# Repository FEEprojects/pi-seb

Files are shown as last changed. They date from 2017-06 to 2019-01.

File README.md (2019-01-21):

# Pi-Seb



A PCB for the Raspberry Pi to create a flexible sensor evaluation board.

Provides the following features:
* HAT identification EEPROM
* 12V DC input
* Battery backed RTC
* Temperature/Humidity Sensor
* 8 differential ADC
* 23 GPIO
* 8 I2C connectors
* 4 SPI connectors
* Debug LEDs (can be disabled)
* 4 port USB hub
  * RS232 connection / TTL Serial
  * 2 TTL Serial ports
  * RS485 connection
* Pycom Socket
  * SD card
  * Control of Raspberry Pi Power
  * 2 TTL Serial ports
  * I2C connection
  * SPI port
  * 8 GPIO

## Assembly
Most of the passives and some of the semi conductors are available in the Seeed studio OPL, additional components then need to be sourced and hand soldred.

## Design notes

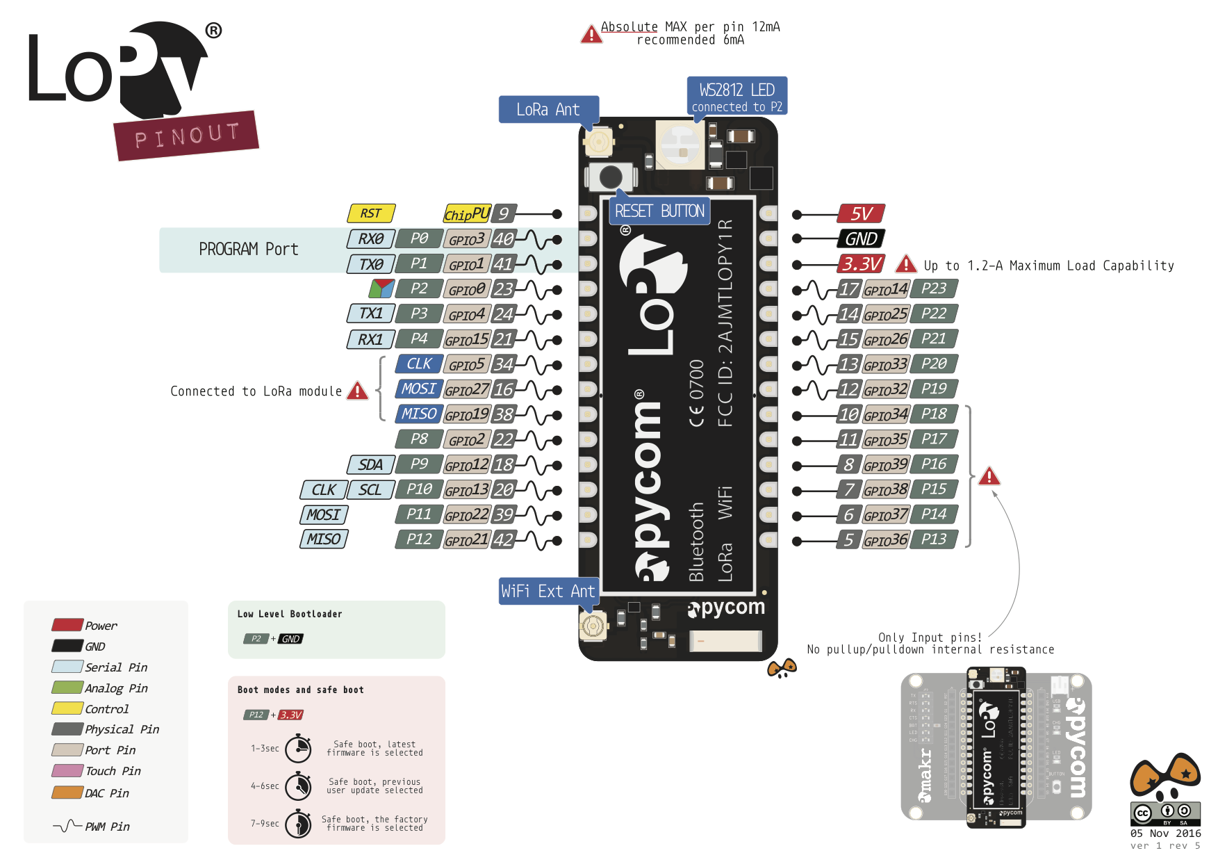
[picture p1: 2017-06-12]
datasheets/lopy_qr.png

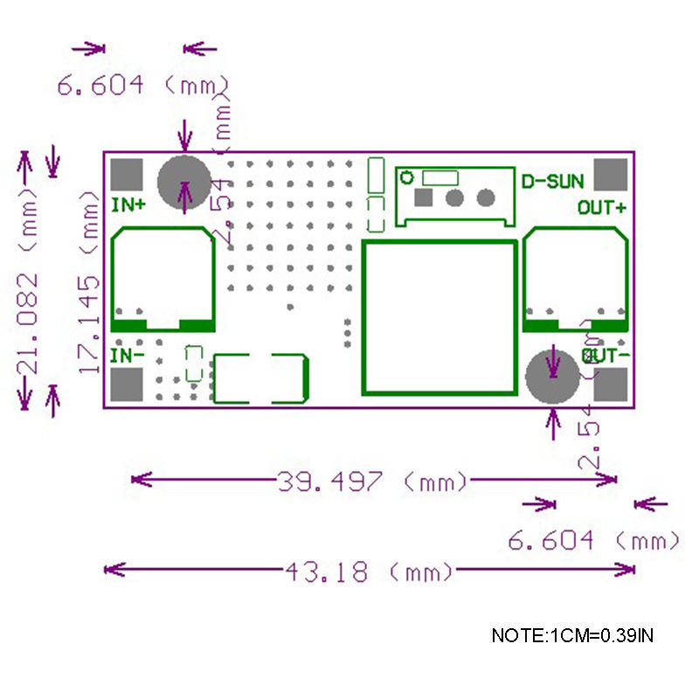
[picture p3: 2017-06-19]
datasheets/DC-Dc board dimensions.jpg

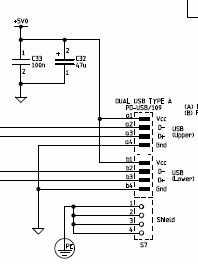
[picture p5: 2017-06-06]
OPL_pdf_lists/USB+INPUT+3+PI.png

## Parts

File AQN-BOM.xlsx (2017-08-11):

.Designator | Description | Qty | auto quantity | Value | Source (if not Seeed) | onecall part no | RS part no | Notes | MPN | Min Order (pcs) | Unit Price | Unit Price (£) | Line Total | To Order (pcs) | Order Price | Owned (pcs)
BAT1 | 320170002 | 1 | 1 |  |  |  |  |  |  | 1 | $0.01 | £0.01 | £0.01 | 6 | £0.05
C2, C6, C7, C11, C12, C13, C14, C18, C19, C20, C21, C22, C23, C24, C28, C29, C31, C35, C36, C38, C39, C42, C43, C46, C47 | 302010138 | 25 | 25 | 100nF |  |  |  |  | CC0603KRX7R9BB104 | 1 | $0.01 | £0.01 | £0.19 | 126 | £0.97
C25 | 302010140 | 1 | 1 | 10nF |  |  |  |  | CC0603KRX7R9BB103 | 1 | $0.01 | £0.01 | £0.01 | 6 | £0.05
C26, C34 | 302020002 | 2 | 2 | 10uF POL |  |  |  |  | TAJA106K016RNJ | 1 | $0.05 | £0.04 | £0.07 | 11 | £0.41
C30, C40, C44, C48 | 302020006 | 4 | 4 | 4.7uF POL |  |  |  |  | TAJA475*016#NJ | 1 | $0.04 | £0.03 | £0.13 | 21 | £0.66
C32 | 302010178 | 1 | 1 | 10uF |  |  |  |  | CC0805KKX5R8BB106 | 1 | $0.01 | £0.01 | £0.01 | 6 | £0.07
C4, C5, C8, C10 | 302020011 | 4 | 4 | 10uF POL |  |  |  |  | TAJA106K010RNJ | 1 | $0.04 | £0.03 | £0.13 | 21 | £0.66
D1 | 304020021 | 1 | 1 | 28V 5A diode |  |  |  |  | SS54B | 1 | $0.10 | £0.08 | £0.08 | 6 | £0.48
D12 | 304090071 | 1 | 1 | Yellow LED |  |  |  |  | ADL-0603W | 1 | $0.05 | £0.04 | £0.04 | 6 | £0.22
D15, D17, D19, D21 | 304090043 | 4 | 4 | green LED |  |  |  |  | 19-217-G7C-AN1P2-3T | 1 | $0.01 | £0.01 | £0.04 | 21 | £0.23
D4, D5, D6, D8, D9, D13, D14, D22 | 304090042 | 8 | 8 | red LED |  |  |  |  | 19-217-R6C-AL1M2VY-3T | 1 | $0.01 | £0.01 | £0.09 | 41 | £0.44
D7, D11, D16, D18, D20 | 304090045 | 5 | 5 | blue LED |  |  |  |  | 19-217-BHC-ZL1M2RY-3T | 1 | $0.01 | £0.01 | £0.05 | 26 | £0.28
DCDC Header |  | 4 | 1 |  | http://onecall.farnell.com/wurth-elektronik/61300111121/header-2-54mm-pin-tht-vertical/dp/2356152 | 2356152 |  |  | 61300111121 | 1 |  | £0.05 | £0.21 | 21 | £1.09
F1 |  | 1 | 1 |  |  | 1822224 |  |  |  | 1 | $0.10 | £0.08 | £0.08 | 6 | £0.45
F2, F5, F6, F9, F10, F15, F16, F19, F20, F26, F27, F28, F29, F40, F41, F42, F43, F46, F47, F48, F49, F50, F51, F54, F55, F56, F57, F59, F60, F62, F76, F78, F79, F82, F83 | 307010002 | 35 | 35 |  |  |  |  |  | SMD1206R500SF | 1 | $0.05 | £0.04 | £1.27 | 176 | £6.37
H1, H2, H3, H4, H5, H6 |  | 6 | 6 |  |  |  |  | Hole drilled through PCB |  |  |  |  |  |  | -
I2C_1, I2C_2, I2C_3, I2C_4, I2C_6, I2C_7, I2C_8, I2C_9, I_UART_HUB_1, LOPY_I2C, LOPY_UART0, LOPY_UART1, PI_RS_485, PI_UART, PI_UART_HUB_1, PI_UART_HUB_2, PI_UART_HUB_3 |  | 17 | 17 |  | http://uk.rs-online.com/web/p/pcb-headers/8201560/ |  | 820-1560 |  |  | 5 |  | £0.17 | £2.82 | 90 | £14.94
J1 | 320120002 | 1 | 1 | DC In |  |  |  |  | JACK-DC-044-A | 1 | $0.09 | £0.07 | £0.07 | 6 | £0.42
J12 | 320030017 | 1 | 1 | 4p-2.54 |  |  |  |  | F185-1104A1BSYA1 | 1 | $0.02 | £0.02 | £0.02 | 6 | £0.10
J2 | 320090008 | 1 | 1 | micro SD |  |  |  |  |  | 1 | $0.11 | £0.08 | £0.08 | 6 | £0.50
J3, J4 | 320020016 | 2 | 2 | 2 way male header |  |  |  |  | P125-1102A0BS116A1 | 1 | $0.01 | £0.01 | £0.02 | 11 | £0.08
J5, J6, J7, J9, J10, J11 | 320020034 | 6 | 6 | 16 way header |  |  |  |  | P125-1116A0BS116AX | 1 | $0.03 | £0.02 | £0.12 | 31 | £0.60
JP1, JP2 | JUMPER | 2 | 2 |  | http://onecall.farnell.com/harwin/m20-9990246/0-1-pin-header-2-way/dp/CN09983 | CN09983 |  |  | M20-9990246 | 10 |  | £0.07 | £0.13 | 20 | £1.30
L2, L3, L4 | 303030006 | 3 | 3 | 330R 1500mA |  |  |  |  | BLM21PG331SN1D | 1 | $0.01 | £0.01 | £0.03 | 16 | £0.18
LoPy Header |  | 2 | 1 |  | http://onecall.farnell.com/samtec/ces-114-01-t-s/receptacle-2-54mm-single-14way/dp/1667519 | 1667519 |  |  | CES-114-01-T-S | 1 |  | £1.41 | £2.82 | 11 | £15.51
LOPY_SPI, PI_ADC_1, PI_ADC_2, PI_ADC_3, PI_ADC_4, SPI_1, SPI_2, SPI_5, SPI_6 |  | 9 | 9 |  | http://uk.rs-online.com/web/p/pcb-headers/8201567/ |  | 820-1567 |  |  | 5 |  | £0.24 | £2.12 | 50 | £11.80
PCB1 |  | 1 | 1 |  | http://onecall.farnell.com/raspberry-pi/raspberrypi-modb-1gb/raspberry-pi-3-model-b/dp/2525225 |  |  | Raspberry Pi |  | 1 | $42.22 | £32.51 | £32.51 | 6 | £195.06
Q2, Q5 | 305030075 | 2 | 2 | ssm3j328r |  |  |  |  | SSM3J328R,LF | 1 | $0.14 | £0.10 | £0.21 | 11 | £1.15
Q3, Q4, Q6, Q7 | 305030000 | 4 | 4 | BSS138 |  |  |  |  | BSS138W-7-F | 1 | $0.03 | £0.03 | £0.10 | 21 | £0.53
Q8 | 305030014 | 1 | 1 | CJ2305 |  |  |  |  |  | 1 | $0.03 | £0.03 | £0.03 | 6 | £0.15
Q9, Q10 | 305020006 | 2 | 2 | S8550 |  |  |  |  |  | 1 | $0.01 | £0.01 | £0.02 | 11 | £0.09
R2, R16, R18, R19, R26, R27 | 301010299 | 6 | 6 | 10k |  |  |  |  | RC0603FR-0710KL | 1 | $0.01 | £0.01 | £0.05 | 31 | £0.24
R20 | 301010241 | 1 | 1 | 15k |  |  |  |  | RC0603FR-0715KL | 1 | $0.01 | £0.01 | £0.01 | 6 | £0.05
R25 |  | 1 | 1 | 120R | Onecall Part No | 9238379 |  |  |  | 10 |  | £0.01 | £0.01 | 10 | £0.14
R28 | 301010671 | 1 | 1 | 2.7k |  |  |  |  | RC0402FR-072K7L | 1 | $0.01 | £0.01 | £0.01 | 6 | £0.05
R37, R38 | 301010101 | 2 | 2 | 3.9k |  |  |  |  | RC0603JR-073K9L | 1 | $0.01 | £0.01 | £0.02 | 11 | £0.08
R39, R40, R43, R44, R45, R46 | 301010089 | 6 | 6 | 100k 5% |  |  |  |  | RC0603JR-07100KL | 1 | $0.01 | £0.01 | £0.05 | 31 | £0.24
R4, R6, R21 | 301010163 | 3 | 3 | 220R |  |  |  |  | RC0603JR-07220RL | 1 | $0.01 | £0.01 | £0.02 | 16 | £0.12
R47 | 301010084 | 1 | 1 |  |  |  |  |  |  | 1 | $0.01 | £0.01 | £0.01 | 6 | £0.05
R5, R35, R36 | 301010298 | 3 | 3 | 1k |  |  |  |  | RC0603FR-071KL | 1 | $0.01 | £0.01 | £0.02 | 16 | £0.12
R7, R23, R24, R29, R30, R31, R32, R33, R34, R42 | 301010300 | 10 | 10 | 330R |  |  |  |  | RC0603FR-07330RL | 1 | $0.01 | £0.01 | £0.08 | 51 | £0.39
R1, R3, R8, R12, R15, R17, R41 | 301010292 | 7 | 7 | 0R |  |  |  |  | RC0603JR-070RL | 1 | $0.01 | £0.01 | £0.05 | 36 | £0.28
R9, R10, R22 | 301010090 | 3 | 3 | 100R |  |  |  |  | RC0603JR-07100RL | 1 | $0.01 | £0.01 | £0.02 | 16 | £0.12
RPi Header |  | 1 | 1 |  | http://onecall.farnell.com/samtec/bcs-120-l-d-te/receptacle-2-54mm-vertical-40way/dp/2308433 | 2308433 |  |  | BCS-120-L-D-TE | 1 |  | £5.39 | £5.39 | 6 | £32.34
SW1, SW2, SW3, SW4 | 311030001 | 4 | 4 |  |  |  |  |  |  | 1 |  | £0.10 | £0.41 | 21 | £2.14
TP1, TP2, TP3, TP4, TP5, TP6, TP7, TP8, TP9, TP10, TP11, TP12, TP13, TP14, TP15, TP16, TP17 |  | 17 | 17 |  |  |  |  | Plain old test pads |  | 1 |  | £0.00 | £0.00 | 86 | £0.00
U$1, U$2 | adc | 2 | 2 |  | http://uk.farnell.com/microchip/mcp3424-e-sl/adc-18bit-quad-channel-14soic/dp/1630424 | 1630424 |  |  | MCP3424-E/SL | 1 |  | £3.41 | £6.82 | 11 | £37.51
U$3 | thyrister | 1 | 1 |  | http://uk.rs-online.com/web/p/thyristors/7743467/ | 2101366 |  |  |  | 10 |  | £0.36 | £0.36 | 10 | £3.62
U$4 | ldo | 1 | 1 |  | http://uk.farnell.com/microchip/mic29300-5-0wu/ldo-volt-reg-3a-5v-to-263-3/dp/2510021 | 2510021 |  |  |  | 1 |  | £2.85 | £2.85 | 6 | £17.10
U$5 | psu | 1 | 1 |  | http://www.amazon.co.uk/LM2596-Step-down-Adjustable-Supply-Module/dp/B008RE3YOA |  |  |  |  | 1 |  | £2.09 | £2.09 | 6 | £12.54
U$6 | usb hub | 1 | 1 |  | http://www.dhgate.com/store/product/fe1-1-s-fe1-1s-usb-2-0-hub-smd-ssop28-new/391709344.html |  |  |  |  | 10 | $0.48 | £0.37 | £0.37 | 10 | £3.72
U$7 |  | 1 | 1 | dht22 | https://www.adafruit.com/product/385 |  |  | DHT22 temp/humidity sensor - maybe you have this? |  | 1 | $9.95 | £7.66 | £7.66 | 6 | £45.97
U1 | port expander | 1 | 1 |  | http://uk.farnell.com/microchip/mcp23017-e-so/16bit-expander-i-o-i2c-i-f-smd/dp/1332087 | 1332087 |  |  | MCP23017-E/SO | 1 |  | £1.00 | £1.00 | 6 | £6.00
U10 | spi-mux | 1 | 1 |  | http://onecall.farnell.com/nexperia/74hct139d/74hct-cmos-smd-74hct139-soic16/dp/1085308 | 1085308 |  |  | 74HCT139D | 1 |  | £0.29 | £0.29 | 6 | £1.72
U11 | zener | 1 | 1 | 30v | http://onecall.farnell.com/multicomp/bzx84c30/diode-zener-0-3w-sot-23/dp/1466595 | 1466595 |  |  | BZX84C30 | 5 |  | £0.04 | £0.04 | 10 | £0.45
U12 | rs485 driver | 1 | 1 |  | http://uk.farnell.com/exar/sp483ecn-l/transceiver-rs485-smd-nsoic8-5v/dp/9387129 | 9387129 |  |  | SP483ECN-L | 1 |  | £1.46 | £1.46 | 6 | £8.76
U2 | rtc | 1 | 1 | DS3231SN | http://onecall.farnell.com/maxim-integrated-products/ds3231sn/rtc-tcxo-crystal-3-3v-16soic/dp/2518948 | 1593292 |  |  | DS3231SN# | 1 |  | £8.07 | £8.07 | 6 | £48.42
U3 |  | 1 | 1 |  | https://www.pycom.io/product/lopy/ |  |  | LoPy Board - you might have a few |  | 1 |  | £26.30 | £26.30 | 6 | £157.80
U4 | 232 driver | 1 | 1 |  | http://uk.farnell.com/texas-instruments/max213idbr/line-driv-rcvr-rs232-120kbps-ssop/dp/2395902 | 2395902 |  |  | MAX213IDBR | 1 |  | £1.50 | £1.50 | 6 | £9.00
U5, U13, U14, U15 | 310070022 | 4 | 4 | ftdi |  |  |  |  | FT232RL | 1 | $3.13 | £2.41 | £9.64 | 21 | £50.61
U8 | eeprom | 1 | 1 |  | http://uk.farnell.com/rohm/br24g32fj-3gte2/serial-eeprom-32kbit-1mhz-sop/dp/2373743?MER=sy-me-pd-mi-alte | 2373743 |  |  | br24g32-3 | 1 |  | £0.69 | £0.69 | 6 | £4.12
USB1 | 320010005 | 1 | 1 |  |  |  |  |  | ZX62-B-5PA | 1 | $0.12 | £0.09 | £0.09 | 6 | £0.54
Y2 | 306010047 | 1 | 1 |  |  |  |  |  | 5032/2P | 1 | $0.20 | £0.15 | £0.15 | 6 | £0.92
 |  |  |  |  |  |  |  |  | No. of PCBs to order: | 5 |  | Per PCB: | £118.78 | Order Total: | £700.01
 |  |  |  |  |  |  |  |  | Spares | 0.1%
 |  |  |  |  |  |  |  |  | Exchange rate | 0.77
 |  |  |  |  |  | 2449396 (http://onecall.farnell.com/iqd-frequency-products/lfxtal016178/crystal-32-768khz-6pf-smd/dp/2449396) | 10
 |  |  |  |  |  | 1085308 | 6
 |  |  |  |  |  | 2373743 | 6
 |  |  |  |  |  | 1466595 | 10
 |  |  |  |  |  | 2101366 | 10
 |  |  |  |  |  | 2395902 | 6
 |  |  |  |  |  | 1332087 | 6
 |  |  |  |  |  | 1630424 | 11
 |  |  |  |  |  | 2103565 | 6
 |  |  |  |  |  | 2510021 | 6
 |  |  |  |  |  | 9387129 | 6
 |  |  |  |  |  | 2308433 | 6
 |  |  |  |  |  | 2356152 | 21
 |  |  |  |  |  | 1667519 | 11

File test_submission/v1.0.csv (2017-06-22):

Part | Value | Device | Package | Description | MPN | OC_FARNELL | OC_NEWARK | PACKAGE | SUPPLIER | TP_SIGNAL_NAME | VALUE
BAT1 | cr1220 | DIP-BATTERY-CELL-HOLDER(1220) | BAT2P-13.5-CR1220 | 320170002 |  |  |  |  |  |  | cr1220
C1 | 10pf | CERAMIC-10PF-50V-5%-NPO(0603) | C0603 | 302010097 | CC0603JRNPO9BN100 |  |  |  |  |  | 10pf
C2 | 100nf | CERAMIC-100NF-50V-10%-X7R(0603) | C0603 | 302010138 | CC0603KRX7R9BB104 |  |  |  |  |  | 100nf
C3 | 10pf | CERAMIC-10PF-50V-5%-NPO(0603) | C0603 | 302010097 | CC0603JRNPO9BN100 |  |  |  |  |  | 10pf
C4 | 10uf | CERAMIC-10UF-10V-10%-X5R(0603) | C0603 | 302010103 | CC0603KRX5R6BB106 |  |  |  |  |  | 10uf
C5 | 1UF 6.3V | CERAMIC-1UF-6.3V-10%-X5R(0402) | C0402 | 302010003 | CC0402KRX5R5BB105 |  |  |  |  |  | 1UF 6.3V
C6 | 100nf | CERAMIC-100NF-50V-10%-X7R(0603) | C0603 | 302010138 | CC0603KRX7R9BB104 |  |  |  |  |  | 100nf
C7 | 100nf | CERAMIC-100NF-50V-10%-X7R(0603) | C0603 | 302010138 | CC0603KRX7R9BB104 |  |  |  |  |  | 100nf
C8 | 1UF 6.3V | CERAMIC-1UF-6.3V-10%-X5R(0402) | C0402 | 302010003 | CC0402KRX5R5BB105 |  |  |  |  |  | 1UF 6.3V
C9 | 10nf | CERAMIC-10NF-50V-5%-X7R(0805) | C0805 | 302010175 | CC0805JRX7R9BB103 |  |  |  |  |  | 10nf
C10 | 10uf | TANTALUM-SMD-10UF-10V-10%(AVX-A) | AVX-A | 302020011 | TAJA106K010RNJ |  |  |  |  |  | 10uf
C11 | 100nf | CERAMIC-100NF-50V-10%-X7R(0603) | C0603 | 302010138 | CC0603KRX7R9BB104 |  |  |  |  |  | 100nf
C12 | 100nf | CERAMIC-100NF-50V-10%-X7R(0603) | C0603 | 302010138 | CC0603KRX7R9BB104 |  |  |  |  |  | 100nf
C13 | 100nf | CERAMIC-100NF-50V-10%-X7R(0603) | C0603 | 302010138 | CC0603KRX7R9BB104 |  |  |  |  |  | 100nf
C14 | 100nf | CERAMIC-100NF-50V-10%-X7R(0603) | C0603 | 302010138 | CC0603KRX7R9BB104 |  |  |  |  |  | 100nf
C15 | 100nf | CERAMIC-100NF-50V-10%-X7R(0603) | C0603 | 302010138 | CC0603KRX7R9BB104 |  |  |  |  |  | 100nf
C16 | 100nf | CERAMIC-100NF-50V-10%-X7R(0603) | C0603 | 302010138 | CC0603KRX7R9BB104 |  |  |  |  |  | 100nf
C17 | 4.7uf | CERAMIC-4.7UF-10V-10%-X5R(0603) | C0603 | 302010111 | CC0603KRX5R6BB475 |  |  |  |  |  | 4.7uf
C18 | 100nf | CERAMIC-100NF-50V-10%-X7R(0603) | C0603 | 302010138 | CC0603KRX7R9BB104 |  |  |  |  |  | 100nf
C19 | 100nf | CERAMIC-100NF-50V-10%-X7R(0603) | C0603 | 302010138 | CC0603KRX7R9BB104 |  |  |  |  |  | 100nf
C28 | 100nf | CERAMIC-100NF-50V-10%-X7R(0603) | C0603 | 302010138 | CC0603KRX7R9BB104 |  |  |  |  |  | 100nf
C29 | 100nf | CERAMIC-100NF-50V-10%-X7R(0603) | C0603 | 302010138 | CC0603KRX7R9BB104 |  |  |  |  |  | 100nf
C30 | 4.7uf | CERAMIC-4.7UF-10V-10%-X5R(0603) | C0603 | 302010111 | CC0603KRX5R6BB475 |  |  |  |  |  | 4.7uf
C31 | 100nf | CERAMIC-100NF-50V-10%-X7R(0805) | C0805 | 302010165 | CC0805KRX7R9BB104 |  |  |  |  |  | 100nf
C32 | 10uf | CERAMIC-10UF-25V-10%-X5R(0805) | C0805 | 302010178 | CC0805KKX5R8BB106 |  |  |  |  |  | 10uf
C33 | 10uf | CERAMIC-10UF-25V-10%-X5R(0805) | C0805 | 302010178 | CC0805KKX5R8BB106 |  |  |  |  |  | 10uf
C34 | 10uf | CERAMIC-10UF-25V-10%-X5R(0805) | C0805 | 302010178 | CC0805KKX5R8BB106 |  |  |  |  |  | 10uf
C35 | 100nf | CERAMIC-100NF-50V-10%-X7R(0603) | C0603 | 302010138 | CC0603KRX7R9BB104 |  |  |  |  |  | 100nf
C36 | 100nf | CERAMIC-100NF-50V-10%-X7R(0603) | C0603 | 302010138 | CC0603KRX7R9BB104 |  |  |  |  |  | 100nf
C38 | 100nf | CERAMIC-100NF-50V-10%-X7R(0603) | C0603 | 302010138 | CC0603KRX7R9BB104 |  |  |  |  |  | 100nf
C39 | 100nf | CERAMIC-100NF-50V-10%-X7R(0603) | C0603 | 302010138 | CC0603KRX7R9BB104 |  |  |  |  |  | 100nf
C40 | 4.7uf | CERAMIC-4.7UF-10V-10%-X5R(0603) | C0603 | 302010111 | CC0603KRX5R6BB475 |  |  |  |  |  | 4.7uf
C42 | 100nf | CERAMIC-100NF-50V-10%-X7R(0603) | C0603 | 302010138 | CC0603KRX7R9BB104 |  |  |  |  |  | 100nf
C43 | 100nf | CERAMIC-100NF-50V-10%-X7R(0603) | C0603 | 302010138 | CC0603KRX7R9BB104 |  |  |  |  |  | 100nf
C44 | 4.7uf | CERAMIC-4.7UF-10V-10%-X5R(0603) | C0603 | 302010111 | CC0603KRX5R6BB475 |  |  |  |  |  | 4.7uf
C46 | 100nf | CERAMIC-100NF-50V-10%-X7R(0603) | C0603 | 302010138 | CC0603KRX7R9BB104 |  |  |  |  |  | 100nf
C47 | 100nf | CERAMIC-100NF-50V-10%-X7R(0603) | C0603 | 302010138 | CC0603KRX7R9BB104 |  |  |  |  |  | 100nf
C48 | 4.7uf | CERAMIC-4.7UF-10V-10%-X5R(0603) | C0603 | 302010111 | CC0603KRX5R6BB475 |  |  |  |  |  | 4.7uf
D1 | 28V-5A | SMD-DIODE-SCHOTTKY-28V-5A(DO-214AA) | DO-214AA | 304020021 | SS54B |  |  |  |  |  | 28V-5A
D2 | BLUE-0603 | SMD-LED-CLEAR-BLUE(0603) | LED-0603 | 304090045 | 19-217-BHC-ZL1M2RY-3T |  |  |  |  |  | BLUE-0603
D3 | GREEN-0603 | SMD-LED-CLEAR-GREEN(0603) | LED-0603 | 304090043 | 19-217-G7C-AN1P2-3T |  |  |  |  |  | GREEN-0603
D4 | RED-0603 | LED-SMD-RED-DIFFUSED(0603) | LED-0603 | 304090042 | 19-217-R6C-AL1M2VY-3T |  |  |  |  |  | RED-0603
D5 | RED-0603 | LED-SMD-RED-DIFFUSED(0603) | LED-0603 | 304090042 | 19-217-R6C-AL1M2VY-3T |  |  |  |  |  | RED-0603
D6 | RED-0603 | LED-SMD-RED-DIFFUSED(0603) | LED-0603 | 304090042 | 19-217-R6C-AL1M2VY-3T |  |  |  |  |  | RED-0603
D7 | BLUE-0603 | SMD-LED-CLEAR-BLUE(0603) | LED-0603 | 304090045 | 19-217-BHC-ZL1M2RY-3T |  |  |  |  |  | BLUE-0603
D8 | RED-0603 | LED-SMD-RED-DIFFUSED(0603) | LED-0603 | 304090042 | 19-217-R6C-AL1M2VY-3T |  |  |  |  |  | RED-0603
D9 | RED-0603 | LED-SMD-RED-DIFFUSED(0603) | LED-0603 | 304090042 | 19-217-R6C-AL1M2VY-3T |  |  |  |  |  | RED-0603
D10 | RED-0603 | LED-SMD-RED-DIFFUSED(0603) | LED-0603 | 304090042 | 19-217-R6C-AL1M2VY-3T |  |  |  |  |  | RED-0603
D11 | BLUE-0603 | SMD-LED-CLEAR-BLUE(0603) | LED-0603 | 304090045 | 19-217-BHC-ZL1M2RY-3T |  |  |  |  |  | BLUE-0603
D13 | RED-0603 | LED-SMD-RED-DIFFUSED(0603) | LED-0603 | 304090042 | 19-217-R6C-AL1M2VY-3T |  |  |  |  |  | RED-0603
D14 | RED-0603 | LED-SMD-RED-DIFFUSED(0603) | LED-0603 | 304090042 | 19-217-R6C-AL1M2VY-3T |  |  |  |  |  | RED-0603
D15 | GREEN-0603 | SMD-LED-CLEAR-GREEN(0603) | LED-0603 | 304090043 | 19-217-G7C-AN1P2-3T |  |  |  |  |  | GREEN-0603
D16 | BLUE-0603 | SMD-LED-CLEAR-BLUE(0603) | LED-0603 | 304090045 | 19-217-BHC-ZL1M2RY-3T |  |  |  |  |  | BLUE-0603
D17 | GREEN-0603 | SMD-LED-CLEAR-GREEN(0603) | LED-0603 | 304090043 | 19-217-G7C-AN1P2-3T |  |  |  |  |  | GREEN-0603
D18 | BLUE-0603 | SMD-LED-CLEAR-BLUE(0603) | LED-0603 | 304090045 | 19-217-BHC-ZL1M2RY-3T |  |  |  |  |  | BLUE-0603
D19 | GREEN-0603 | SMD-LED-CLEAR-GREEN(0603) | LED-0603 | 304090043 | 19-217-G7C-AN1P2-3T |  |  |  |  |  | GREEN-0603
D20 | BLUE-0603 | SMD-LED-CLEAR-BLUE(0603) | LED-0603 | 304090045 | 19-217-BHC-ZL1M2RY-3T |  |  |  |  |  | BLUE-0603
D21 | GREEN-0603 | SMD-LED-CLEAR-GREEN(0603) | LED-0603 | 304090043 | 19-217-G7C-AN1P2-3T |  |  |  |  |  | GREEN-0603
F1 | 307010005_DIP_PPTC_4A_0310 | 307010005_DIP_PPTC_4A_0310 | TH_5MM_14MM | DIP PPTC 4A-30V;0310, RLD30P400UF 2P, SKU: 307010005
F2 | SMD1206R500SF | SMD-PPTC-500MA(1206) | F1206 | 307010002 | SMD1206R500SF |  |  |  |  |  | SMD1206R500SF
F3 | SMD1206R500SF | SMD-PPTC-500MA(1206) | F1206 | 307010002 | SMD1206R500SF |  |  |  |  |  | SMD1206R500SF
F4 | SMD1206R500SF | SMD-PPTC-500MA(1206) | F1206 | 307010002 | SMD1206R500SF |  |  |  |  |  | SMD1206R500SF
F5 | SMD1206R500SF | SMD-PPTC-500MA(1206) | F1206 | 307010002 | SMD1206R500SF |  |  |  |  |  | SMD1206R500SF
F6 | SMD1206R500SF | SMD-PPTC-500MA(1206) | F1206 | 307010002 | SMD1206R500SF |  |  |  |  |  | SMD1206R500SF
F7 | SMD1206R500SF | SMD-PPTC-500MA(1206) | F1206 | 307010002 | SMD1206R500SF |  |  |  |  |  | SMD1206R500SF
F8 | SMD1206R500SF | SMD-PPTC-500MA(1206) | F1206 | 307010002 | SMD1206R500SF |  |  |  |  |  | SMD1206R500SF
F9 | SMD1206R500SF | SMD-PPTC-500MA(1206) | F1206 | 307010002 | SMD1206R500SF |  |  |  |  |  | SMD1206R500SF
F10 | SMD1206R500SF | SMD-PPTC-500MA(1206) | F1206 | 307010002 | SMD1206R500SF |  |  |  |  |  | SMD1206R500SF
F11 | SMD1206R500SF | SMD-PPTC-500MA(1206) | F1206 | 307010002 | SMD1206R500SF |  |  |  |  |  | SMD1206R500SF
F12 | SMD1206R500SF | SMD-PPTC-500MA(1206) | F1206 | 307010002 | SMD1206R500SF |  |  |  |  |  | SMD1206R500SF
F13 | SMD1206R500SF | SMD-PPTC-500MA(1206) | F1206 | 307010002 | SMD1206R500SF |  |  |  |  |  | SMD1206R500SF
F14 | SMD1206R500SF | SMD-PPTC-500MA(1206) | F1206 | 307010002 | SMD1206R500SF |  |  |  |  |  | SMD1206R500SF
F15 | SMD1206R500SF | SMD-PPTC-500MA(1206) | F1206 | 307010002 | SMD1206R500SF |  |  |  |  |  | SMD1206R500SF
F16 | SMD1206R500SF | SMD-PPTC-500MA(1206) | F1206 | 307010002 | SMD1206R500SF |  |  |  |  |  | SMD1206R500SF
F17 | SMD1206R500SF | SMD-PPTC-500MA(1206) | F1206 | 307010002 | SMD1206R500SF |  |  |  |  |  | SMD1206R500SF
F18 | SMD1206R500SF | SMD-PPTC-500MA(1206) | F1206 | 307010002 | SMD1206R500SF |  |  |  |  |  | SMD1206R500SF
F19 | SMD1206R500SF | SMD-PPTC-500MA(1206) | F1206 | 307010002 | SMD1206R500SF |  |  |  |  |  | SMD1206R500SF
F20 | SMD1206R500SF | SMD-PPTC-500MA(1206) | F1206 | 307010002 | SMD1206R500SF |  |  |  |  |  | SMD1206R500SF
F21 | SMD1206R500SF | SMD-PPTC-500MA(1206) | F1206 | 307010002 | SMD1206R500SF |  |  |  |  |  | SMD1206R500SF
F22 | SMD1206R500SF | SMD-PPTC-500MA(1206) | F1206 | 307010002 | SMD1206R500SF |  |  |  |  |  | SMD1206R500SF
F23 | SMD1206R500SF | SMD-PPTC-500MA(1206) | F1206 | 307010002 | SMD1206R500SF |  |  |  |  |  | SMD1206R500SF
F24 | SMD1206R500SF | SMD-PPTC-500MA(1206) | F1206 | 307010002 | SMD1206R500SF |  |  |  |  |  | SMD1206R500SF
F25 | SMD1206R500SF | SMD-PPTC-500MA(1206) | F1206 | 307010002 | SMD1206R500SF |  |  |  |  |  | SMD1206R500SF
F26 | SMD1206R500SF | SMD-PPTC-500MA(1206) | F1206 | 307010002 | SMD1206R500SF |  |  |  |  |  | SMD1206R500SF
F27 | SMD1206R500SF | SMD-PPTC-500MA(1206) | F1206 | 307010002 | SMD1206R500SF |  |  |  |  |  | SMD1206R500SF
F28 | SMD1206R500SF | SMD-PPTC-500MA(1206) | F1206 | 307010002 | SMD1206R500SF |  |  |  |  |  | SMD1206R500SF
F29 | SMD1206R500SF | SMD-PPTC-500MA(1206) | F1206 | 307010002 | SMD1206R500SF |  |  |  |  |  | SMD1206R500SF
F30 | SMD1206R500SF | SMD-PPTC-500MA(1206) | F1206 | 307010002 | SMD1206R500SF |  |  |  |  |  | SMD1206R500SF
F31 | SMD1206R500SF | SMD-PPTC-500MA(1206) | F1206 | 307010002 | SMD1206R500SF |  |  |  |  |  | SMD1206R500SF
F32 | SMD1206R500SF | SMD-PPTC-500MA(1206) | F1206 | 307010002 | SMD1206R500SF |  |  |  |  |  | SMD1206R500SF
F33 | SMD1206R500SF | SMD-PPTC-500MA(1206) | F1206 | 307010002 | SMD1206R500SF |  |  |  |  |  | SMD1206R500SF
F34 | SMD1206R500SF | SMD-PPTC-500MA(1206) | F1206 | 307010002 | SMD1206R500SF |  |  |  |  |  | SMD1206R500SF
F35 | SMD1206R500SF | SMD-PPTC-500MA(1206) | F1206 | 307010002 | SMD1206R500SF |  |  |  |  |  | SMD1206R500SF
F36 | SMD1206R500SF | SMD-PPTC-500MA(1206) | F1206 | 307010002 | SMD1206R500SF |  |  |  |  |  | SMD1206R500SF
F37 | SMD1206R500SF | SMD-PPTC-500MA(1206) | F1206 | 307010002 | SMD1206R500SF |  |  |  |  |  | SMD1206R500SF
F38 | SMD1206R500SF | SMD-PPTC-500MA(1206) | F1206 | 307010002 | SMD1206R500SF |  |  |  |  |  | SMD1206R500SF
F39 | SMD1206R500SF | SMD-PPTC-500MA(1206) | F1206 | 307010002 | SMD1206R500SF |  |  |  |  |  | SMD1206R500SF
F40 | SMD1206R500SF | SMD-PPTC-500MA(1206) | F1206 | 307010002 | SMD1206R500SF |  |  |  |  |  | SMD1206R500SF
F41 | SMD1206R500SF | SMD-PPTC-500MA(1206) | F1206 | 307010002 | SMD1206R500SF |  |  |  |  |  | SMD1206R500SF
F42 | SMD1206R500SF | SMD-PPTC-500MA(1206) | F1206 | 307010002 | SMD1206R500SF |  |  |  |  |  | SMD1206R500SF
F43 | SMD1206R500SF | SMD-PPTC-500MA(1206) | F1206 | 307010002 | SMD1206R500SF |  |  |  |  |  | SMD1206R500SF
F44 | SMD1206R500SF | SMD-PPTC-500MA(1206) | F1206 | 307010002 | SMD1206R500SF |  |  |  |  |  | SMD1206R500SF
F45 | SMD1206R500SF | SMD-PPTC-500MA(1206) | F1206 | 307010002 | SMD1206R500SF |  |  |  |  |  | SMD1206R500SF
F46 | SMD1206R500SF | SMD-PPTC-500MA(1206) | F1206 | 307010002 | SMD1206R500SF |  |  |  |  |  | SMD1206R500SF
F47 | SMD1206R500SF | SMD-PPTC-500MA(1206) | F1206 | 307010002 | SMD1206R500SF |  |  |  |  |  | SMD1206R500SF
F48 | SMD1206R500SF | SMD-PPTC-500MA(1206) | F1206 | 307010002 | SMD1206R500SF |  |  |  |  |  | SMD1206R500SF
F49 | SMD1206R500SF | SMD-PPTC-500MA(1206) | F1206 | 307010002 | SMD1206R500SF |  |  |  |  |  | SMD1206R500SF
F50 | SMD1206R500SF | SMD-PPTC-500MA(1206) | F1206 | 307010002 | SMD1206R500SF |  |  |  |  |  | SMD1206R500SF
F51 | SMD1206R500SF | SMD-PPTC-500MA(1206) | F1206 | 307010002 | SMD1206R500SF |  |  |  |  |  | SMD1206R500SF
F52 | SMD1206R500SF | SMD-PPTC-500MA(1206) | F1206 | 307010002 | SMD1206R500SF |  |  |  |  |  | SMD1206R500SF
F53 | SMD1206R500SF | SMD-PPTC-500MA(1206) | F1206 | 307010002 | SMD1206R500SF |  |  |  |  |  | SMD1206R500SF
F54 | SMD1206R500SF | SMD-PPTC-500MA(1206) | F1206 | 307010002 | SMD1206R500SF |  |  |  |  |  | SMD1206R500SF
F55 | SMD1206R500SF | SMD-PPTC-500MA(1206) | F1206 | 307010002 | SMD1206R500SF |  |  |  |  |  | SMD1206R500SF
F56 | SMD1206R500SF | SMD-PPTC-500MA(1206) | F1206 | 307010002 | SMD1206R500SF |  |  |  |  |  | SMD1206R500SF
F57 | SMD1206R500SF | SMD-PPTC-500MA(1206) | F1206 | 307010002 | SMD1206R500SF |  |  |  |  |  | SMD1206R500SF
F58 | SMD1206R500SF | SMD-PPTC-500MA(1206) | F1206 | 307010002 | SMD1206R500SF |  |  |  |  |  | SMD1206R500SF
F74 | SMD1206R500SF | SMD-PPTC-500MA(1206) | F1206 | 307010002 | SMD1206R500SF |  |  |  |  |  | SMD1206R500SF
F75 | SMD1206R500SF | SMD-PPTC-500MA(1206) | F1206 | 307010002 | SMD1206R500SF |  |  |  |  |  | SMD1206R500SF
F76 | SMD1206R500SF | SMD-PPTC-500MA(1206) | F1206 | 307010002 | SMD1206R500SF |  |  |  |  |  | SMD1206R500SF
F77 | SMD1206R500SF | SMD-PPTC-500MA(1206) | F1206 | 307010002 | SMD1206R500SF |  |  |  |  |  | SMD1206R500SF
F78 | SMD1206R500SF | SMD-PPTC-500MA(1206) | F1206 | 307010002 | SMD1206R500SF |  |  |  |  |  | SMD1206R500SF
F79 | SMD1206R500SF | SMD-PPTC-500MA(1206) | F1206 | 307010002 | SMD1206R500SF |  |  |  |  |  | SMD1206R500SF
F80 | SMD1206R500SF | SMD-PPTC-500MA(1206) | F1206 | 307010002 | SMD1206R500SF |  |  |  |  |  | SMD1206R500SF
F81 | SMD1206R500SF | SMD-PPTC-500MA(1206) | F1206 | 307010002 | SMD1206R500SF |  |  |  |  |  | SMD1206R500SF
F82 | SMD1206R500SF | SMD-PPTC-500MA(1206) | F1206 | 307010002 | SMD1206R500SF |  |  |  |  |  | SMD1206R500SF
F83 | SMD1206R500SF | SMD-PPTC-500MA(1206) | F1206 | 307010002 | SMD1206R500SF |  |  |  |  |  | SMD1206R500SF
I2C_1 | JST-XH-05-PIN-ROUND-PAD | JST-XH-05-PIN-ROUND-PAD | JST-XH-05-PACKAGE-ROUND-PAD | JST XH Connector 2 Pin
I2C_2 | JST-XH-05-PIN-ROUND-PAD | JST-XH-05-PIN-ROUND-PAD | JST-XH-05-PACKAGE-ROUND-PAD | JST XH Connector 2 Pin
I2C_3 | JST-XH-05-PIN-ROUND-PAD | JST-XH-05-PIN-ROUND-PAD | JST-XH-05-PACKAGE-ROUND-PAD | JST XH Connector 2 Pin
I2C_4 | JST-XH-05-PIN-ROUND-PAD | JST-XH-05-PIN-ROUND-PAD | JST-XH-05-PACKAGE-ROUND-PAD | JST XH Connector 2 Pin
I2C_5 | JST-XH-05-PIN-ROUND-PAD | JST-XH-05-PIN-ROUND-PAD | JST-XH-05-PACKAGE-ROUND-PAD | JST XH Connector 2 Pin
I2C_6 | JST-XH-05-PIN-ROUND-PAD | JST-XH-05-PIN-ROUND-PAD | JST-XH-05-PACKAGE-ROUND-PAD | JST XH Connector 2 Pin
I2C_7 | JST-XH-05-PIN-ROUND-PAD | JST-XH-05-PIN-ROUND-PAD | JST-XH-05-PACKAGE-ROUND-PAD | JST XH Connector 2 Pin
I2C_8 | JST-XH-05-PIN-ROUND-PAD | JST-XH-05-PIN-ROUND-PAD | JST-XH-05-PACKAGE-ROUND-PAD | JST XH Connector 2 Pin
I2C_9 | JST-XH-05-PIN-ROUND-PAD | JST-XH-05-PIN-ROUND-PAD | JST-XH-05-PACKAGE-ROUND-PAD | JST XH Connector 2 Pin
I2C_10 | JST-XH-05-PIN-ROUND-PAD | JST-XH-05-PIN-ROUND-PAD | JST-XH-05-PACKAGE-ROUND-PAD | JST XH Connector 2 Pin
I_UART_HUB_1 | JST-XH-05-PIN-ROUND-PAD | JST-XH-05-PIN-ROUND-PAD | JST-XH-05-PACKAGE-ROUND-PAD | JST XH Connector 2 Pin
J1 | DC-044-A | JACK-DC-044-A | DCJ3P-11.6X9.6X7.0MM | 320120002 | JACK-DC-044-A |  |  |  |  |  | DC-044-A
J2 | MICROSD-9P | MICRO-SD-CARD-HOLDER-9P | MICRO-SD9+4P-SMD-16.1X14.5X1.85MM | 320090008 |  |  |  |  |  |  | MICROSD-9P
J3 | 2p-2.54 | DIP-BLACK-MALE-HEADER-VERT(2P-2.54) | H2-2.54 | 320020016 | P125-1102A0BS116A1 |  |  |  |  |  | 2p-2.54
J4 | 2p-2.54 | DIP-BLACK-MALE-HEADER-VERT(2P-2.54) | H2-2.54 | 320020016 | P125-1102A0BS116A1 |  |  |  |  |  | 2p-2.54
J5 | 16p-2.54 | DIP-BLACK-MALE-HEADER-VERT(16P-2.54) | H16-2.54 | 320020034 | P125-1116A0BS116AX |  |  |  |  |  | 16p-2.54
J6 | 16p-2.54 | DIP-BLACK-MALE-HEADER-VERT(16P-2.54) | H16-2.54 | 320020034 | P125-1116A0BS116AX |  |  |  |  |  | 16p-2.54
J7 | 2x3p-2.54 | DIP-BLACK-MALE-HEADER(2X3P-2.54）-2.54 | H2X3-2.54 | 320020077 | P125-12A1BS116A1 |  |  |  |  |  | 2x3p-2.54
J8 | 2p-2.54 | DIP-BLACK-ROUND-FEMALE-HEADER-VERT(2P-2.54) | H2-2.54 | 320030050 | RF130-1023ABS0741 |  |  |  |  |  | 2p-2.54
L1 | 330R-1500MA | SMD-FERRITE-BEAD-330R-1500MA(0805)'0805' | L0805 | 303030006 | BLM21PG331SN1D |  |  |  |  |  | 330R-1500MA
L2 | 330R-1500MA | SMD-FERRITE-BEAD-330R-1500MA(0805)'0805' | L0805 | 303030006 | BLM21PG331SN1D |  |  |  |  |  | 330R-1500MA
L3 | 330R-1500MA | SMD-FERRITE-BEAD-330R-1500MA(0805)'0805' | L0805 | 303030006 | BLM21PG331SN1D |  |  |  |  |  | 330R-1500MA
LOPY_I2C | JST-XH-05-PIN-ROUND-PAD | JST-XH-05-PIN-ROUND-PAD | JST-XH-05-PACKAGE-ROUND-PAD | JST XH Connector 2 Pin
LOPY_SPI | JST-XH-07-PIN-ROUND-PAD | JST-XH-07-PIN-ROUND-PAD | JST-XH-07-PACKAGE-ROUND-PAD | JST XH Connector 2 Pin
LOPY_UART0 | JST-XH-05-PIN-ROUND-PAD | JST-XH-05-PIN-ROUND-PAD | JST-XH-05-PACKAGE-ROUND-PAD | JST XH Connector 2 Pin
LOPY_UART1 | JST-XH-05-PIN-ROUND-PAD | JST-XH-05-PIN-ROUND-PAD | JST-XH-05-PACKAGE-ROUND-PAD | JST XH Connector 2 Pin
PCB1 | RPI2 | RPI2 | RPI2 | Device for Raspberry Pi 2 board created by www.element14.com
PI_ADC_1 | JST-XH-07-PIN-ROUND-PAD | JST-XH-07-PIN-ROUND-PAD | JST-XH-07-PACKAGE-ROUND-PAD | JST XH Connector 2 Pin
PI_ADC_2 | JST-XH-07-PIN-ROUND-PAD | JST-XH-07-PIN-ROUND-PAD | JST-XH-07-PACKAGE-ROUND-PAD | JST XH Connector 2 Pin
PI_ADC_3 | JST-XH-07-PIN-ROUND-PAD | JST-XH-07-PIN-ROUND-PAD | JST-XH-07-PACKAGE-ROUND-PAD | JST XH Connector 2 Pin
PI_ADC_4 | JST-XH-07-PIN-ROUND-PAD | JST-XH-07-PIN-ROUND-PAD | JST-XH-07-PACKAGE-ROUND-PAD | JST XH Connector 2 Pin
PI_RS_485 | JST-XH-05-PIN-ROUND-PAD | JST-XH-05-PIN-ROUND-PAD | JST-XH-05-PACKAGE-ROUND-PAD | JST XH Connector 2 Pin
PI_UART | JST-XH-05-PIN-ROUND-PAD | JST-XH-05-PIN-ROUND-PAD | JST-XH-05-PACKAGE-ROUND-PAD | JST XH Connector 2 Pin
PI_UART_HUB_2 | JST-XH-05-PIN-ROUND-PAD | JST-XH-05-PIN-ROUND-PAD | JST-XH-05-PACKAGE-ROUND-PAD | JST XH Connector 2 Pin
PI_UART_HUB_3 | JST-XH-05-PIN-ROUND-PAD | JST-XH-05-PIN-ROUND-PAD | JST-XH-05-PACKAGE-ROUND-PAD | JST XH Connector 2 Pin
Q2 | SSM3J328R,LF | SMD-MOSFET-P-CH-20V-6A-SSM3J328R(SOT-23) | SOT-23 | 305030075 | SSM3J328R,LF |  |  |  |  |  | SSM3J328R,LF
Q3 | 6pF@32.7680kHz | CRYTAL68SMX | 86SMX | CRYSTAL
Q4 | BSS138W-7-F | SMD-MOSFET-N-CH-50V-200MA-BSS138W-7-F(SOT-23) | SOT-23 | 305030000 | BSS138W-7-F |  |  |  |  |  | BSS138W-7-F
Q5 | SSM3J328R,LF | SMD-MOSFET-P-CH-20V-6A-SSM3J328R(SOT-23) | SOT-23 | 305030075 | SSM3J328R,LF |  |  |  |  |  | SSM3J328R,LF
R1 | 330R | SMD-RES-330R-1%-1/10W(0603) | R0603 | 301010300 | RC0603FR-07330RL |  |  |  |  |  | 330R
R2 | 10K 1/10W | SMD-RES-10K-5%-1/10W(0603) | R0603 | 301010293 | RC0603JR-0710KL |  |  |  |  |  | 10K 1/10W
R3 | 330R | SMD-RES-330R-1%-1/10W(0603) | R0603 | 301010300 | RC0603FR-07330RL |  |  |  |  |  | 330R
R4 | 4.7K | SMD-RES-4.7K-5%-1/10W(0603) | R0603 | 301010290 | RC0603JR-074K7L |  |  |  |  |  | 4.7K
R5 | 1K | SMD-RES-1K-1%-1/10W(0603) | R0603 | 301010298 | RC0603FR-071KL |  |  |  |  |  | 1K
R6 | 220R | SMD-RES-220R-5%-1/10W(0603) | R0603 | 301010163 | RC0603JR-07220RL |  |  |  |  |  | 220R
R7 | 330R | SMD-RES-330R-1%-1/10W(0603) | R0603 | 301010300 | RC0603FR-07330RL |  |  |  |  |  | 330R
R8 | 10K | SMD-RES-10K-1%-1/10W(0603) | R0603 | 301010299 | RC0603FR-0710KL |  |  |  |  |  | 10K
R9 | 100R | SMD-RES-100R-5%-1/10W(0603) | R0603 | 301010090 | RC0603JR-07100RL |  |  |  |  |  | 100R
R10 | 100R | SMD-RES-100R-5%-1/10W(0603) | R0603 | 301010090 | RC0603JR-07100RL |  |  |  |  |  | 100R
R11 | 1K | SMD-RES-1K-1%-1/10W(0603) | R0603 | 301010298 | RC0603FR-071KL |  |  |  |  |  | 1K
R12 | 4.7K | SMD-RES-4.7K-5%-1/10W(0603) | R0603 | 301010290 | RC0603JR-074K7L |  |  |  |  |  | 4.7K
R13 | 10K | SMD-RES-10K-1%-1/10W(0603) | R0603 | 301010299 | RC0603FR-0710KL |  |  |  |  |  | 10K
R14 | 4.7K | SMD-RES-4.7K-5%-1/10W(0603) | R0603 | 301010290 | RC0603JR-074K7L |  |  |  |  |  | 4.7K
R15 | 10K | SMD-RES-10K-1%-1/10W(0603) | R0603 | 301010299 | RC0603FR-0710KL |  |  |  |  |  | 10K
R16 | 10K | SMD-RES-10K-1%-1/10W(0603) | R0603 | 301010299 | RC0603FR-0710KL |  |  |  |  |  | 10K
R18 | 10K | SMD-RES-10K-1%-1/10W(0603) | R0603 | 301010299 | RC0603FR-0710KL |  |  |  |  |  | 10K
R19 | 10K | SMD-RES-10K-1%-1/10W(0603) | R0603 | 301010299 | RC0603FR-0710KL |  |  |  |  |  | 10K
R20 | 15K 1/10W | SMD-RES-15K-1%-1/10W(0603) | R0603 | 301010241 | RC0603FR-0715KL |  |  |  |  |  | 15K 1/10W
R21 | 220R | SMD-RES-220R-5%-1/10W(0603) | R0603 | 301010163 | RC0603JR-07220RL |  |  |  |  |  | 220R
R22 | 100R | SMD-RES-100R-5%-1/10W(0603) | R0603 | 301010090 | RC0603JR-07100RL |  |  |  |  |  | 100R
R23 | 330R | SMD-RES-330R-1%-1/10W(0603) | R0603 | 301010300 | RC0603FR-07330RL |  |  |  |  |  | 330R
R24 | 330R | SMD-RES-330R-1%-1/10W(0603) | R0603 | 301010300 | RC0603FR-07330RL |  |  |  |  |  | 330R
R25 | 4.7K | SMD-RES-4.7K-5%-1/10W(0603) | R0603 | 301010290 | RC0603JR-074K7L |  |  |  |  |  | 4.7K
R26 | 10K | SMD-RES-10K-1%-1/10W(0603) | R0603 | 301010299 | RC0603FR-0710KL |  |  |  |  |  | 10K
R27 | 10K | SMD-RES-10K-1%-1/10W(0603) | R0603 | 301010299 | RC0603FR-0710KL |  |  |  |  |  | 10K
R28 | 2.7K 1/16W | SMD-RES-2.7K-1%-1/16W(0402) | R0402 | 301010671 | RC0402FR-072K7L |  |  |  |  |  | 2.7K 1/16W
R29 | 330R | SMD-RES-330R-1%-1/10W(0603) | R0603 | 301010300 | RC0603FR-07330RL |  |  |  |  |  | 330R
R30 | 330R | SMD-RES-330R-1%-1/10W(0603) | R0603 | 301010300 | RC0603FR-07330RL |  |  |  |  |  | 330R
R31 | 330R | SMD-RES-330R-1%-1/10W(0603) | R0603 | 301010300 | RC0603FR-07330RL |  |  |  |  |  | 330R
R32 | 330R | SMD-RES-330R-1%-1/10W(0603) | R0603 | 301010300 | RC0603FR-07330RL |  |  |  |  |  | 330R
R33 | 330R | SMD-RES-330R-1%-1/10W(0603) | R0603 | 301010300 | RC0603FR-07330RL |  |  |  |  |  | 330R
R34 | 330R | SMD-RES-330R-1%-1/10W(0603) | R0603 | 301010300 | RC0603FR-07330RL |  |  |  |  |  | 330R
R35 | 1K | SMD-RES-1K-1%-1/10W(0603) | R0603 | 301010298 | RC0603FR-071KL |  |  |  |  |  | 1K
R36 | 1M | SMD-RES-1M-1%-1/10W(0603) | R0603 | 301010151 | RC0603FR-071ML |  |  |  |  |  | 1M
R37 | 3.9K | SMD-RES-3.9K-5%-1/10W(0603) | R0603 | 301010101 | RC0603JR-073K9L |  |  |  |  |  | 3.9K
R38 | 3.9K | SMD-RES-3.9K-5%-1/10W(0603) | R0603 | 301010101 | RC0603JR-073K9L |  |  |  |  |  | 3.9K
R39 | 100K 1/10W | SMD-RES-100K-5%-1/10W(0603) | R0603 | 301010089 | RC0603JR-07100KL |  |  |  |  |  | 100K 1/10W
R40 | 100K 1/10W | SMD-RES-100K-5%-1/10W(0603) | R0603 | 301010089 | RC0603JR-07100KL |  |  |  |  |  | 100K 1/10W
SPI_1 | JST-XH-07-PIN-ROUND-PAD | JST-XH-07-PIN-ROUND-PAD | JST-XH-07-PACKAGE-ROUND-PAD | JST XH Connector 2 Pin
SPI_2 | JST-XH-07-PIN-ROUND-PAD | JST-XH-07-PIN-ROUND-PAD | JST-XH-07-PACKAGE-ROUND-PAD | JST XH Connector 2 Pin
SPI_3 | JST-XH-07-PIN-ROUND-PAD | JST-XH-07-PIN-ROUND-PAD | JST-XH-07-PACKAGE-ROUND-PAD | JST XH Connector 2 Pin
SPI_4 | JST-XH-07-PIN-ROUND-PAD | JST-XH-07-PIN-ROUND-PAD | JST-XH-07-PACKAGE-ROUND-PAD | JST XH Connector 2 Pin
SPI_5 | JST-XH-07-PIN-ROUND-PAD | JST-XH-07-PIN-ROUND-PAD | JST-XH-07-PACKAGE-ROUND-PAD | JST XH Connector 2 Pin
SPI_6 | JST-XH-07-PIN-ROUND-PAD | JST-XH-07-PIN-ROUND-PAD | JST-XH-07-PACKAGE-ROUND-PAD | JST XH Connector 2 Pin
SPI_7 | JST-XH-07-PIN-ROUND-PAD | JST-XH-07-PIN-ROUND-PAD | JST-XH-07-PACKAGE-ROUND-PAD | JST XH Connector 2 Pin
SPI_8 | JST-XH-07-PIN-ROUND-PAD | JST-XH-07-PIN-ROUND-PAD | JST-XH-07-PACKAGE-ROUND-PAD | JST XH Connector 2 Pin
SW1 | SW-200D | DIP-TILT-SWITCH-SW-200D(2P-12X3.6MM) | SW2-12.7-12.0X3.6X3.6MM | 311100000 | SW-200D |  |  |  |  |  | SW-200D
SW2 | SW-200D | DIP-TILT-SWITCH-SW-200D(2P-12X3.6MM) | SW2-12.7-12.0X3.6X3.6MM | 311100000 | SW-200D |  |  |  |  |  | SW-200D
SW3 | SW-200D | DIP-TILT-SWITCH-SW-200D(2P-12X3.6MM) | SW2-12.7-12.0X3.6X3.6MM | 311100000 | SW-200D |  |  |  |  |  | SW-200D
SW4 | SW-200D | DIP-TILT-SWITCH-SW-200D(2P-12X3.6MM) | SW2-12.7-12.0X3.6X3.6MM | 311100000 | SW-200D |  |  |  |  |  | SW-200D
SW5 | SW-200D | DIP-TILT-SWITCH-SW-200D(2P-12X3.6MM) | SW2-12.7-12.0X3.6X3.6MM | 311100000 | SW-200D |  |  |  |  |  | SW-200D
SW6 | SW-200D | DIP-TILT-SWITCH-SW-200D(2P-12X3.6MM) | SW2-12.7-12.0X3.6X3.6MM | 311100000 | SW-200D |  |  |  |  |  | SW-200D
SW7 | SW-200D | DIP-TILT-SWITCH-SW-200D(2P-12X3.6MM) | SW2-12.7-12.0X3.6X3.6MM | 311100000 | SW-200D |  |  |  |  |  | SW-200D
SW8 | SW-200D | DIP-TILT-SWITCH-SW-200D(2P-12X3.6MM) | SW2-12.7-12.0X3.6X3.6MM | 311100000 | SW-200D |  |  |  |  |  | SW-200D
TP1 | TPB2,54 | TPB2,54 | B2,54 | Test pad
TP2 | TPB2,54 | TPB2,54 | B2,54 | Test pad
TP3 | TPB2,54 | TPB2,54 | B2,54 | Test pad
TP4 | TPB2,54 | TPB2,54 | B2,54 | Test pad
TP5 | TPB2,54 | TPB2,54 | B2,54 | Test pad
TP6 | TPB2,54 | TPB2,54 | B2,54 | Test pad
TP7 | TPB2,54 | TPB2,54 | B2,54 | Test pad
TP8 | TPB2,54 | TPB2,54 | B2,54 | Test pad
U$1 | MCP3424-E/SL | MCP3424-E/SL | SOIC127P600X175-14N | Analog-to-Digital Converter | MCP3424-E/SL | 1630424 | 54M4871 | SOIC-14 | Microchip
U$2 | MCP3424-E/SL | MCP3424-E/SL | SOIC127P600X175-14N | Analog-to-Digital Converter | MCP3424-E/SL | 1630424 | 54M4871 | SOIC-14 | Microchip
U$3 | C106DG | C106DG | TO-225AA
U$4 | MCR29300 | MCR29300 | TO-263
U$5 | DC-DC-STEP-DOWN-LM2596 | DC-DC-STEP-DOWN-LM2596 | DC-DC-STEP-DOWN-LM2596 | DC/DC Step-Down Regulator based on LM2596-ADJ chip
U$6 | FE1.1S | FE1.1S | FE1.1S_SSOP-28 | A USB 2.0 hub IC.
U$7 | TEMP-HUM-SENSOR-DHT22 | TEMP-HUM-SENSOR-DHT22 | TEMP-HUM-SENSOR-DHT22 | DHT22 - digital humidity & temperature sensor
U1 | MCP23017-E/SO | MCP23017-E/SO | SOIC127P1032X265-28N | IC, 16-Bit I/O Expander with Serial Interface, SOIC-28 | MCP23017-E/SO | 1332087 | 34M7442 | SOIC-28 | Microchip
U2 | MCP79412-I/SN | MCP79412-I/SN | SOIC127P600X175-8N | RTCC, I2C, 1K EE, 64B SRAM, 8SOIC | MCP79412-I/SN | 2103565 | 94T5863 | SOIC-8 | Microchip
U3 | LOPY | LOPY | LOPY
U5 | FT232RL-SSOP28 | INTERFACE-FT232RL(SSOP28) | SSOP28-0.65-10.2X5.2MM | 310070022 | FT232RL |  |  |  |  |  | FT232RL-SSOP28
U6 | FT232RL-SSOP28 | INTERFACE-FT232RL(SSOP28) | SSOP28-0.65-10.2X5.2MM | 310070022 | FT232RL |  |  |  |  |  | FT232RL-SSOP28
U7 | 2x14p-2.54 | DIP-IC-SOCKET(2X14P-2.54) | SCK28-2.54-35.6X10MM | 320070000 | ICX-28P |  |  |  |  |  | 2x14p-2.54
U8 | BR24G32-3 | BR24G32-3 | SOP8 | http://uk.farnell.com/rohm/br24g32fj-3gte2/serial-eeprom-32kbit-1mhz-sop/dp/2373743?MER=sy-me-pd-mi-alte
U10 | 74HC139N | 74HC139N | DIP254P762X420-16 | Dual 2-to-4 line decoder/demultiplexer | 74HC139N | 380556 | 07WX3674 | DIP-16 | NXP
U11 | BZX84C30 | BZX84C30 | SOT91P240X110-3N | 350mW SURFACE MOUNT ZENER DIODE | BZX84C30 | 1902456 | - | SOT-23-3 | DIODES INC.
U12 | SP483ECN-L | SP483ECN-L | SOIC127P600X175-8N | Transceiver | SP483ECN-L | 9387129 | 24R0561 | SOIC-8 | Exar
U13 | FT232RL-SSOP28 | INTERFACE-FT232RL(SSOP28) | SSOP28-0.65-10.2X5.2MM | 310070022 | FT232RL |  |  |  |  |  | FT232RL-SSOP28
U14 | FT232RL-SSOP28 | INTERFACE-FT232RL(SSOP28) | SSOP28-0.65-10.2X5.2MM | 310070022 | FT232RL |  |  |  |  |  | FT232RL-SSOP28
U15 | FT232RL-SSOP28 | INTERFACE-FT232RL(SSOP28) | SSOP28-0.65-10.2X5.2MM | 310070022 | FT232RL |  |  |  |  |  | FT232RL-SSOP28
USB1 | ZX62-B-5PA | MICRO-USB-SMD(ZX62-B-5PA) | MICRO-USB5+6P-SMD-0.65-AB | 320010005 | ZX62-B-5PA |  |  |  |  |  | ZX62-B-5PA
USB3 | ZX62-B-5PA | MICRO-USB-SMD(ZX62-B-5PA) | MICRO-USB5+6P-SMD-0.65-AB | 320010005 | ZX62-B-5PA |  |  |  |  |  | ZX62-B-5PA
Y2 | 12MHZ | SMD-CRYSTAL-12MHZ-20PF-20PPM-40R(2P-5.0X3.2MM) | X2-SMD-5.0X3.2X1.3MM | 306010047 | 5032/2P |  |  |  |  |  | 12MHZ

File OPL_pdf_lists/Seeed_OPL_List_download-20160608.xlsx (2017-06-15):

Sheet: OPL on sale list
OPL on sale list. 20160608
Seeed SKU | MPN | Description | Category | Package | Manufacturer | Datasheet | Price（$）/pcs | Pieces/set | Solder points Qty | Assem.Cost/pcs（$） | Image URL | Distributor-URL
306010055 | FC-135 | SMD Crystal 32.768KHz-7pF-20ppm-70k | Crystal Oscillator | 2P-L3.2*W1.5mm | Xinhunjing | http://www.seeedstudio.com/wiki/images/7/78/306010055.pdf | 0.391 | 5 | 4 | 0.40 |  | http://www.seeedstudio.com/depot/OPLopen-parts-library-catalog-c-136_138/#306010055
306010037 | 49S/18PF | DIP Crystal 16MHz-18pF-30ppm-50R | Crystal Oscillator | HC49/US | Xinhunjing | http://www.seeedstudio.com/wiki/images/5/57/306010037.pdf | 0.131 | 10 | 2 | 0.20 |  | http://www.seeedstudio.com/depot/OPLopen-parts-library-catalog-c-136_138/#306010037
306010054 | X053201602002 | SMD Crystal 16MHz-8pF-20ppm-40R | Crystal Oscillator | 2P-SMD-5.0X3.2 | JINGPENGYUAN | http://www.seeedstudio.com/wiki/images/9/9f/0500290P1.pdf | 0.430 | 5 | 2 | 0.20 |  | http://www.seeedstudio.com/depot/OPLopen-parts-library-catalog-c-136_138/#0500290P1
306010047 | 5032/2P | SMD Crystal 12MHz-20pF-20ppm-40R | Crystal Oscillator | 2P-L5.0*W3.2mm | Xinhunjing | http://www.seeedstudio.com/wiki/images/c/c7/306010047.pdf | 0.449 | 5 | 2 | 0.20 |  | http://www.seeedstudio.com/depot/OPLopen-parts-library-catalog-c-136_138/#306010047
305030028 | 2N7002,215 | SMD MOSFET N-CH 60V 300mA | Transistor | SOT-23 | NXP | http://www.seeedstudio.com/wiki/images/c/c6/305030028.pdf | 0.037 | 30 | 3 | 0.30 |  | http://www.seeedstudio.com/depot/OPLopen-parts-library-catalog-c-136_138/#305030028
305030015 | CJ2302 | SMD MOSFET N-CH 20V 2.1A | Transistor | SOT23 | JCET | http://www.seeedstudio.com/wiki/images/e/e7/0440200P1.pdf | 0.090 | 10 | 3 | 0.30 |  | http://www.seeedstudio.com/depot/OPLopen-parts-library-catalog-c-136_138/#0440200P1
305030014 | CJ2305 | SMD MOSFET P-CH 8V 4.1A | Transistor | SOT-23 | JCET | http://www.seeedstudio.com/wiki/images/a/ac/0440210P1.pdf | 0.078 | 10 | 3 | 0.30 |  | http://www.seeedstudio.com/depot/OPLopen-parts-library-catalog-c-136_138/#0440210P1
305010018 | S9013 | SMD Transistors NPN 25V 500mA | Transistor | SOT-23 | JCET | http://www.seeedstudio.com/wiki/images/6/67/0400000P1.pdf | 0.023 | 50 | 3 | 0.30 |  | http://www.seeedstudio.com/depot/OPLopen-parts-library-catalog-c-136_138/#0400000P1
305020006 | S8550 | SMD Transistors PNP 25V 500mA | Transistor | SOT-23 |  | http://www.seeedstudio.com/wiki/images/e/e5/0410030P1.pdf | 0.023 | 50 | 3 | 0.30 |  | http://www.seeedstudio.com/depot/OPLopen-parts-library-catalog-c-136_138/#0410030P1
305010017 | S8050 | SMD Transistors NPN 25V 500mW | Transistor | SOT-23 | JCET | http://www.seeedstudio.com/wiki/images/b/ba/305010017.pdf | 0.023 | 50 | 3 | 0.30 |  | http://www.seeedstudio.com/depot/OPLopen-parts-library-catalog-c-136_138/#305010017
312010004 | KS-12065D03YA | DIP Buzzer 3V/30mA;2700±300Hz | Audio product | 2P-7.6-D12*H6.5mm | Guangjixing | http://www.seeedstudio.com/wiki/images/c/cb/312020003.pdf | 0.504 | 5 | 2 | 0.20 |  | http://www.seeedstudio.com/depot/OPLopen-parts-library-catalog-c-136_138/#312010004
302020027 | TAJD477M006RNJ | SMD CAP Tantalum 470uF-6.3V;D | Capacitor | AVX-D | AVX |  | 0.918 | 5 | 2 | 0.20 |  | http://www.seeedstudio.com/depot/OPLopen-parts-library-catalog-c-136_138/#302020027
302030031 |  | DIP CAP Aluminum 100uF-16V | Capacitor | Radial-D5.0*H7.0mm | JWCO | http://www.seeedstudio.com/wiki/images/1/14/302030031.pdf | 0.015 | 50 | 2 | 0.20 |  | http://www.seeedstudio.com/depot/OPLopen-parts-library-catalog-c-136_138/#302030031
302020025 | TAJC107K010RNJ | SMD CAP Tantalum 100uF-10V 10% | Capacitor | AVX-C | AVX | http://www.seeedstudio.com/wiki/images/a/ae/0130170P1.pdf | 0.281 | 10 | 2 | 0.20 |  | http://www.seeedstudio.com/depot/OPLopen-parts-library-catalog-c-136_138/#0130170P1
302020022 | TAJC476K016RNJ | SMD CAP Tantalum 47uF-16V | Capacitor | AVX-C | AVX | http://www.seeedstudio.com/wiki/images/c/c7/302020022.pdf | 0.300 | 10 | 2 | 0.20 |  | http://www.seeedstudio.com/depot/OPLopen-parts-library-catalog-c-136_138/#302020022
302020020 | TAJB476K010RNJ | SMD CAP Tantalum 47uF-10V 10% | Capacitor | AVX-B | AVX | http://www.seeedstudio.com/wiki/images/f/fb/0130180P1.pdf | 0.157 | 10 | 2 | 0.20 |  | http://www.seeedstudio.com/depot/OPLopen-parts-library-catalog-c-136_138/#0130180P1
302020005 | TAJC476K006RNJ | SMD CAP Tantalum 47uF-6.3V | Capacitor | AVX-A | AVX |  | 0.109 | 20 | 2 | 0.20 |  | http://www.seeedstudio.com/depot/OPLopen-parts-library-catalog-c-136_138/#302020005
302020021 | TAJB226K010RNJ | SMD CAP Tantalum 22uF-10V 10% | Capacitor | AVX-B | AVX | http://www.seeedstudio.com/wiki/images/8/82/0130240P1.pdf | 0.125 | 20 | 2 | 0.20 |  | http://www.seeedstudio.com/depot/OPLopen-parts-library-catalog-c-136_138/#0130240P1
302010171 | CC0805MKX5R5BB226 | SMD CAP Ceramic 22uF-6.3V-20%-X5R; | Capacitor | 0805 | YAGEO |  | 0.055 | 50 | 2 | 0.20 |  | http://www.seeedstudio.com/depot/OPLopen-parts-library-catalog-c-136_138/#302010171
302010181 | CC1206KKX5R8BB106 | SMD CAP Ceramic 10uF-25V-10%-X5R | Capacitor | 1206 | YAGEO |  | 0.091 | 20 | 2 | 0.20 |  | http://www.seeedstudio.com/depot/OPLopen-parts-library-catalog-c-136_138/#302010181
302010178 | CC0805KKX5R8BB106 | SMD CAP Ceramic 10uF-25V-10%-X5R | Capacitor | 0805 | YAGEO | http://www.seeedstudio.com/wiki/images/2/20/0100080P1.pdf | 0.055 | 50 | 2 | 0.20 |  | http://www.seeedstudio.com/depot/OPLopen-parts-library-catalog-c-136_138/#0100080P1
302020019 | TAJB106K016RNJ | SMD CAP Tantalum 10uF-16V 10% | Capacitor | AVX-B | AVX | http://www.seeedstudio.com/wiki/images/f/f6/0130120P1.pdf | 0.109 | 20 | 2 | 0.20 |  | http://www.seeedstudio.com/depot/OPLopen-parts-library-catalog-c-136_138/#0130120P1
302020002 | TAJA106K016RNJ | SMD CAP Tantalum 10uF-16V 10% | Capacitor | AVX-A | AVX | http://www.seeedstudio.com/wiki/images/1/1b/0130050P1.pdf | 0.098 | 20 | 2 | 0.20 |  | http://www.seeedstudio.com/depot/OPLopen-parts-library-catalog-c-136_138/#0130050P1
302020011 | TAJA106K010RNJ | SMD CAP Tantalum 10uF-10V 10% | Capacitor | AVX-A | AVX | http://www.seeedstudio.com/wiki/images/5/59/0130040P1.pdf (http://www.seeedstudio.com/wiki/images/0/0d/302010146.pdf) | 0.105 | 20 | 2 | 0.20 |  | http://www.seeedstudio.com/depot/OPLopen-parts-library-catalog-c-136_138/#0130040P1
302010146 | CC0805KKX5R8BB475 | SMD CAP Ceramic 4.7uF-25V-10%-X5R;0805 | Capacitor | C0805 | YAGEO | http://www.seeedstudio.com/wiki/images/0/0d/302010146.pdf | 0.041 | 50 | 2 | 0.20 |  | http://www.seeedstudio.com/depot/OPLopen-parts-library-catalog-c-136_138/#302010146
302010111 | CC0603KRX5R6BB475 | SMD CAP Ceramic 4.7uF-10V-10%-X5R; | Capacitor | 0603 | YAGEO |  | 0.023 | 50 | 2 | 0.20 |  | http://www.seeedstudio.com/depot/OPLopen-parts-library-catalog-c-136_138/#302010111
302010019 | CC0402MRX5R5BB475 | SMD CAP Ceramic 4.7uF-6.3V-20%-X5R | Capacitor | 0402 | YAGEO |  | 0.016 | 10 | 2 | 0.20 |  | http://www.seeedstudio.com/depot/OPLopen-parts-library-catalog-c-136_138/#302010019
302010148 | CC0805KKX7R8BB225 | SMD CAP Ceramic 2.2uF-25V-10%-X7R;0805 | Capacitor | C0805 | YAGEO | http://www.seeedstudio.com/wiki/images/a/ac/302010056.pdf | 0.042 | 50 | 2 | 0.20 |  | http://www.seeedstudio.com/depot/OPLopen-parts-library-catalog-c-136_138/#302010148
302010179 | CC0805KKX7R8BB105 | SMD CAP Ceramic 1uF-25V-10%-X7R | Capacitor | 0805 | YAGEO | http://www.seeedstudio.com/wiki/images/8/89/0100440P1.pdf (http://www.seeedstudio.com/wiki/images/a/ac/302010056.pdf) | 0.014 | 50 | 2 | 0.20 |  | http://www.seeedstudio.com/depot/OPLopen-parts-library-catalog-c-136_138/#0100440P1
302010139 | CC0603KRX7R8BB105 | SMD CAP Ceramic 1uF-25V-10%-X7R | Capacitor | 0603 | YAGEO | http://www.seeedstudio.com/wiki/images/a/af/0100340P1.pdf (http://www.seeedstudio.com/wiki/File:302010056.pdf) | 0.010 | 100 | 2 | 0.20 |  | http://www.seeedstudio.com/depot/OPLopen-parts-library-catalog-c-136_138/#0100340P1
302010040 | CC0402KRX5R6BB105 | SMD CAP Ceramic 1uF-10V-10%-X5R | Capacitor | 0402 | YAGEO |  | 0.010 | 100 | 2 | 0.20 |  | http://www.seeedstudio.com/depot/OPLopen-parts-library-catalog-c-136_138/#302010040
302010073 | CC0603KRX7R8BB224 | SMD CAP Ceramic 220nF-25V-10%-X7R;0603 | Capacitor | 0603 | YAGEO | http://www.seeedstudio.com/wiki/images/a/ac/302010056.pdf | 0.014 | 100 | 2 | 0.20 |  | http://www.seeedstudio.com/depot/OPLopen-parts-library-catalog-c-136_138/#302010073
302010165 | CC0805KRX7R9BB104 | SMD CAP Ceramic 100nF-50V-10%-X7R; | Capacitor | 0805 | YAGEO | http://www.seeedstudio.com/wiki/File:302010056.pdf (http://www.seeedstudio.com/wiki/images/a/ac/302010056.pdf) | 0.010 | 100 | 2 | 0.20 |  | http://www.seeedstudio.com/depot/OPLopen-parts-library-catalog-c-136_138/#302010165
302010138 | CC0603KRX7R9BB104 | SMD CAP Ceramic 100nF-50V-10%-X7R | Capacitor | 0603 | YAGEO | http://www.seeedstudio.com/wiki/images/3/35/0100020P1.pdf | 0.010 | 100 | 2 | 0.20 |  | http://www.seeedstudio.com/depot/OPLopen-parts-library-catalog-c-136_138/#0100020P1
302010024 | CC0402KRX7R8BB104 | SMD CAP Ceramic 100nF-25V-10%-X7R | Capacitor | 0402 | YAGEO | http://www.seeedstudio.com/wiki/images/a/ac/302010056.pdf | 0.010 | 100 | 2 | 0.20 |  | http://www.seeedstudio.com/depot/OPLopen-parts-library-catalog-c-136_138/#302010024
302010002 | CC0402KRX7R8BB473 | SMD CAP Ceramic 47nF-25V-10%-X7R; | Capacitor | 0402 | YAGEO |  | 0.010 | 100 | 2 | 0.20 |  | http://www.seeedstudio.com/depot/OPLopen-parts-library-catalog-c-136_138/#302010002
302010088 | CC0603KRX7R9BB333 | SMD CAP Ceramic 33nF-50V-10%-X7R;0603 | Capacitor | 0603 | YAGEO | http://www.seeedstudio.com/wiki/images/a/ac/302010056.pdf | 0.010 | 100 | 2 | 0.20 |  | http://www.seeedstudio.com/depot/OPLopen-parts-library-catalog-c-136_138/#302010088
302010095 | CC0603KRX7R9BB223 | SMD CAP Ceramic 22nF-50V-10%-X7R;0603 | Capacitor | C0603 | YAGEO | http://www.seeedstudio.com/wiki/images/a/ac/302010056.pdf | 0.010 | 100 | 2 | 0.20 |  | http://www.seeedstudio.com/depot/OPLopen-parts-library-catalog-c-136_138/#302010095
302010202 |  | DIP CAP Ceramic Disc 10nF-50V-Y5V | Capacitor | Radial-Disc-2.5-D4.0mm |  |  | 0.020 | 100 | 2 | 0.20 |  | http://www.seeedstudio.com/depot/OPLopen-parts-library-catalog-c-136_138/#302010202
302010140 | CC0603KRX7R9BB103 | SMD CAP Ceramic 10nF-50V-10%-X7R | Capacitor | 0603 | YAGEO | http://www.seeedstudio.com/wiki/images/e/eb/0100350P1.pdf (http://www.seeedstudio.com/wiki/images/f/f0/302010067.pdf%20302010094) | 0.010 | 100 | 2 | 0.20 |  | http://www.seeedstudio.com/depot/OPLopen-parts-library-catalog-c-136_138/#0100350P1
302010006 | CC0402KRX7R9BB103 | SMD CAP Ceramic 10nF-50V-10%-X7R | Capacitor | 0402 | YAGEO | http://www.seeedstudio.com/wiki/images/f/f0/302010067.pdf | 0.010 | 100 | 2 | 0.20 |  | http://www.seeedstudio.com/depot/OPLopen-parts-library-catalog-c-136_138/#302010006
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

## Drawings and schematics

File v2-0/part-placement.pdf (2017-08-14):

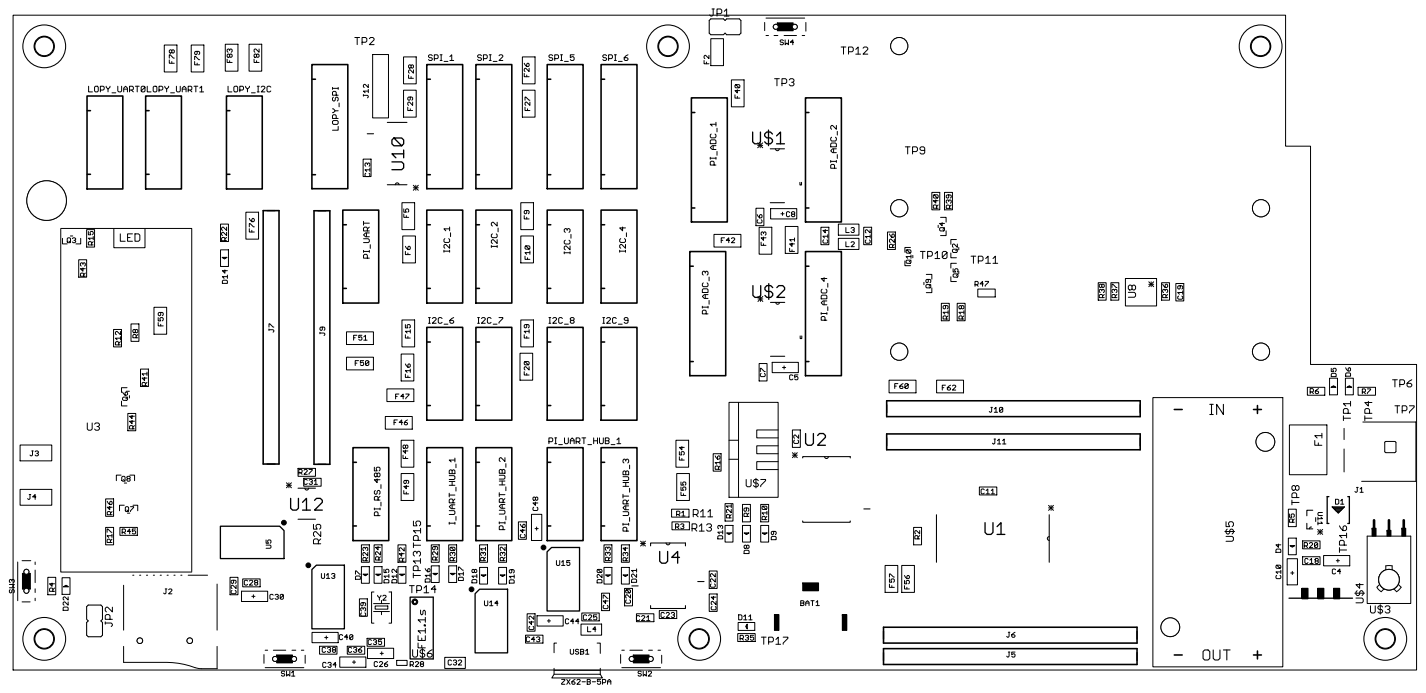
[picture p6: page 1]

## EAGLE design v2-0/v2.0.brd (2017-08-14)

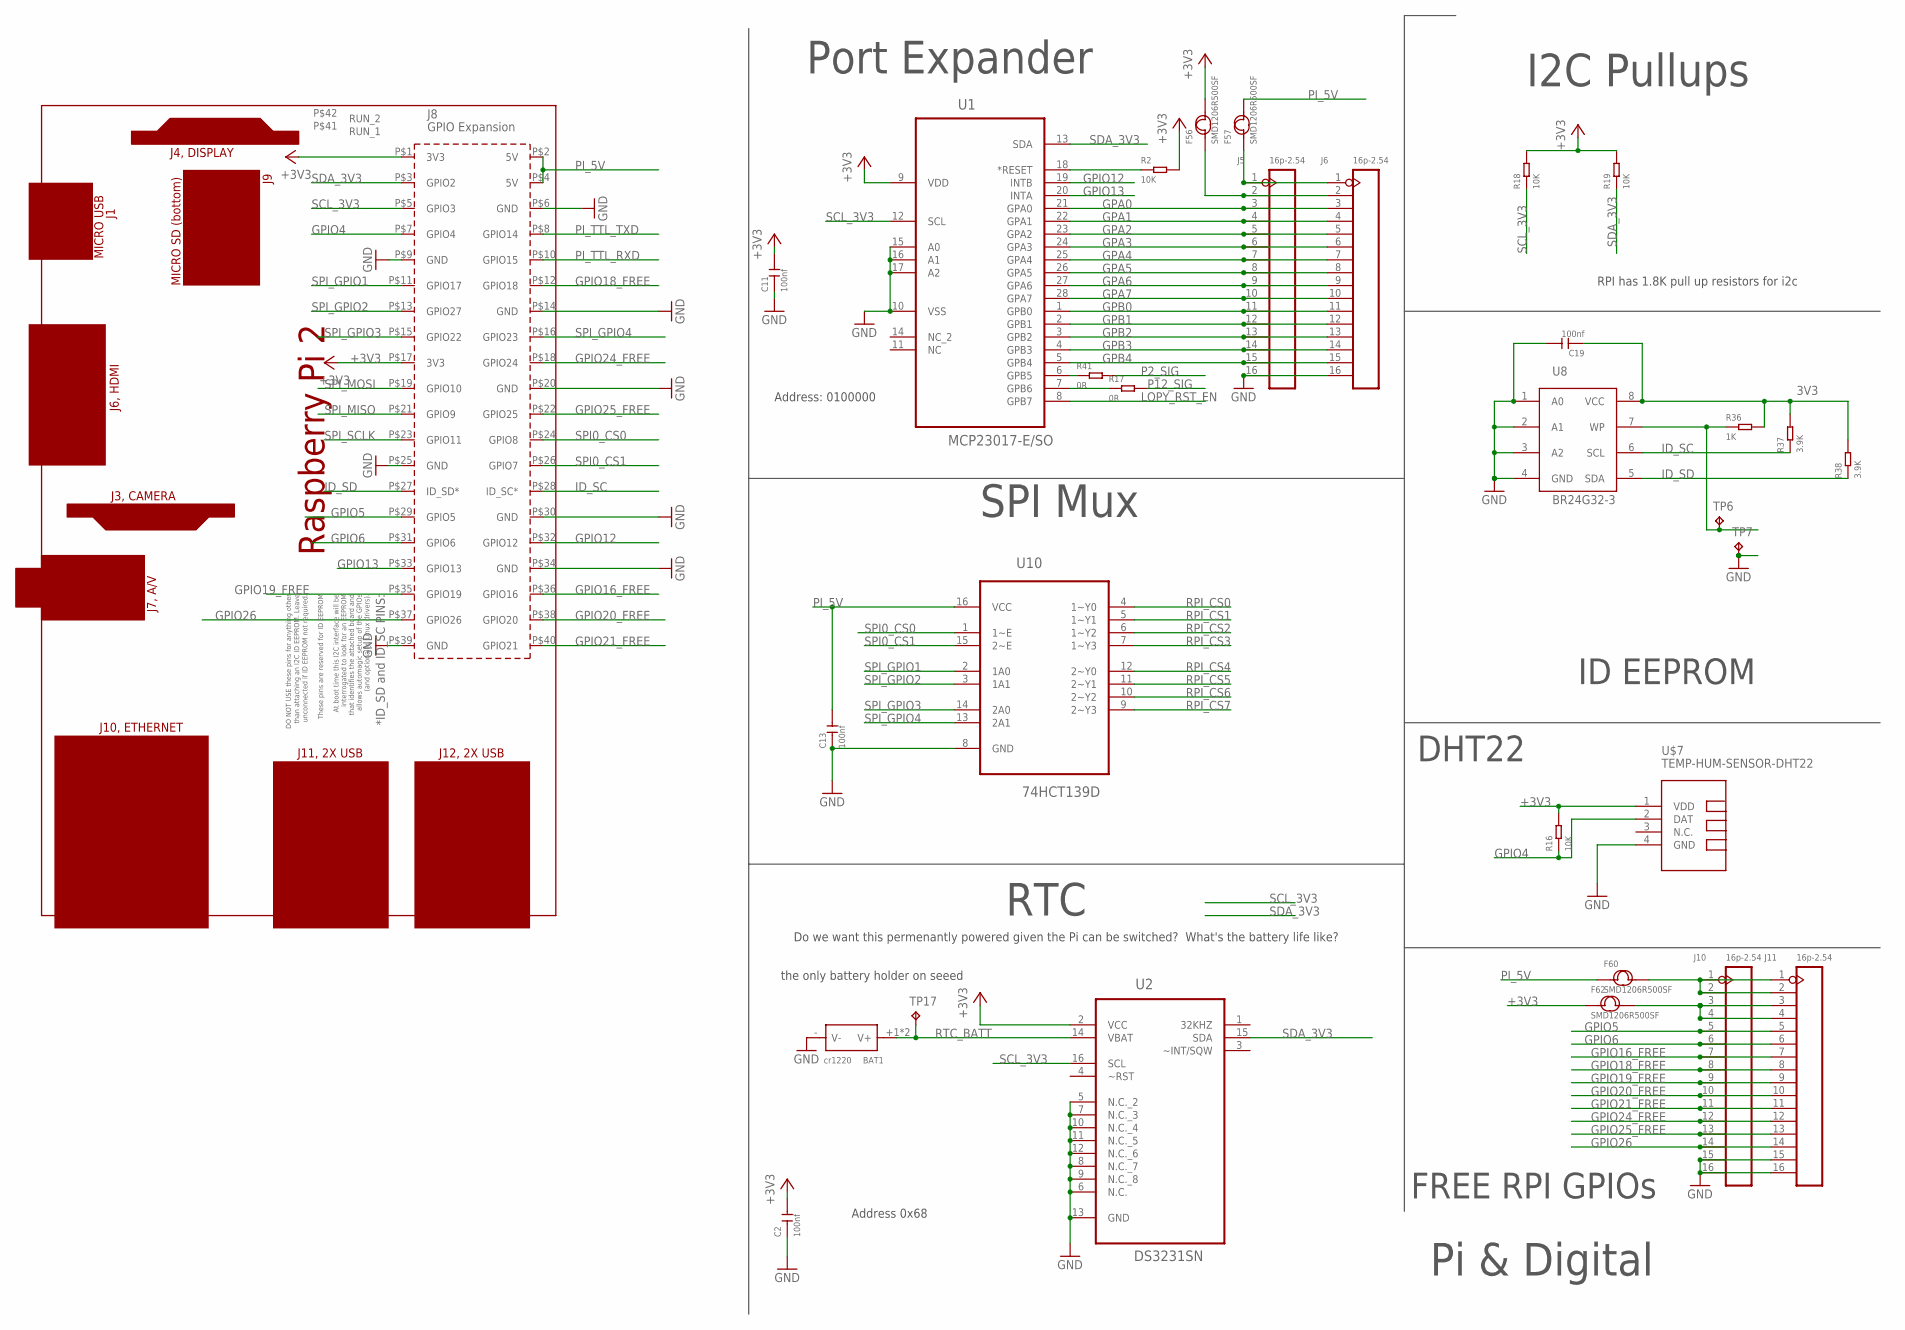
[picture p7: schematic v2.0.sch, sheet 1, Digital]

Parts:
BAT1: cr1220; BAT2P-13.5-CR1220
C2, C11, C13, C19: 100nf; C0603
F56, F57, F60, F62: SMD1206R500SF; F1206
J5, J6, J10, J11: 16p-2.54; H16-2.54
PCB1: RPI2
R2, R16, R18, R19: 10K; R0603
R17, R41: 0R; R0603
R36: 1K; R0603
R37, R38: 3.9K; R0603
TP6, TP7, TP17: TPB2,54; B2,54
U1: MCP23017-E/SO; SOIC127P1032X265-28N
U2: DS3231SN; SOIC127P1032X265-16N
U8: BR24G32-3; SOP8
U10: 74HCT139D; SOIC127P600X175-16N
U$7: TEMP-HUM-SENSOR-DHT22

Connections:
3V3: C19.1, R36.2, R37.2, R38.2, U8.8 (VCC)
+3V3: C2.2, C11.2, F56.2, F62.1, PCB1.P$1 (3V3), PCB1.P$17 (3V3), R2.2, R16.2, R18.2, R19.2, U1.9 (VDD), U2.2 (VCC), U$7.1 (VDD); also elsewhere on the board
EEPROM_WP: R36.1, TP6.TP, U8.7 (WP)
EXP_3V3: F56.1, J5.2, J6.2
EXP_5V: F57.1, J5.1, J6.1
GND: BAT1.- (V-), C2.1, C11.1, C13.1, C19.2, J5.16, J6.16, J10.15, J10.16, J11.15, J11.16, PCB1.P$6 (GND), PCB1.P$9 (GND), PCB1.P$14 (GND), PCB1.P$20 (GND), PCB1.P$25 (GND), PCB1.P$30 (GND), PCB1.P$34 (GND), PCB1.P$39 (GND), TP7.TP, U1.10 (VSS), U1.15 (A0), U1.16 (A1), U1.17 (A2), U2.5 (N.C._2), U2.6 (N.C.), U2.7 (N.C._3), U2.8 (N.C._7), U2.9 (N.C._8), U2.10 (N.C._4), U2.11 (N.C._5), U2.12 (N.C._6), U2.13 (GND), U8.1 (A0), U8.2 (A1), U8.3 (A2), U8.4 (GND), U10.8 (GND), U$7.4 (GND); also elsewhere on the board
GPA0: J5.3, J6.3, U1.21 (GPA0)
GPA1: J5.4, J6.4, U1.22 (GPA1)
GPA2: J5.5, J6.5, U1.23 (GPA2)
GPA3: J5.6, J6.6, U1.24 (GPA3)
GPA4: J5.7, J6.7, U1.25 (GPA4)
GPA5: J5.8, J6.8, U1.26 (GPA5)
GPA6: J5.9, J6.9, U1.27 (GPA6)
GPA7: J5.10, J6.10, U1.28 (GPA7)
GPB0: J5.11, J6.11, U1.1 (GPB0)
GPB1: J5.12, J6.12, U1.2 (GPB1)
GPB2: J5.13, J6.13, U1.3 (GPB2)
GPB3: J5.14, J6.14, U1.4 (GPB3)
GPB4: J5.15, J6.15, U1.5 (GPB4)
GPIO4: PCB1.P$7 (GPIO4), R16.1, U$7.2 (DAT)
GPIO5: J10.5, J11.5, PCB1.P$29 (GPIO5)
GPIO6: J10.6, J11.6, PCB1.P$31 (GPIO6)
GPIO12: PCB1.P$32 (GPIO12), U1.19 (INTB)
GPIO13: PCB1.P$33 (GPIO13), U1.20 (INTA)
GPIO16_FREE: J10.7, J11.7, PCB1.P$36 (GPIO16)
GPIO18_FREE: J10.8, J11.8, PCB1.P$12 (GPIO18)
GPIO19_FREE: J10.9, J11.9, PCB1.P$35 (GPIO19)
GPIO20_FREE: J10.10, J11.10, PCB1.P$38 (GPIO20)
GPIO21_FREE: J10.11, J11.11, PCB1.P$40 (GPIO21)
GPIO24_FREE: J10.12, J11.12, PCB1.P$18 (GPIO24)
GPIO25_FREE: J10.13, J11.13, PCB1.P$22 (GPIO25)
GPIO26: J10.14, J11.14, PCB1.P$37 (GPIO26)
GPIO_5V_FUSED: F60.2, J10.1, J10.2, J11.1, J11.2
ID_SC: PCB1.P$28 (ID_SC*), R37.1, U8.6 (SCL)
ID_SD: PCB1.P$27 (ID_SD*), R38.1, U8.5 (SDA)
LOPY_RST_EN: U1.8 (GPB7); also elsewhere on the board
unnamed: R2.1, U1.18 (*RESET)
unnamed: F62.2, J10.3, J10.4, J11.3, J11.4
P2_EN: R41.1, U1.6 (GPB5)
P2_SIG: R41.2; also elsewhere on the board
P12_SIG: R17.2; also elsewhere on the board
PI12_EN: R17.1, U1.7 (GPB6)
PI_5V: C13.2, F57.2, F60.1, PCB1.P$2 (5V), PCB1.P$4 (5V), U10.16 (VCC); also elsewhere on the board
PI_TTL_RXD: PCB1.P$10 (GPIO15); also elsewhere on the board
PI_TTL_TXD: PCB1.P$8 (GPIO14); also elsewhere on the board
RPI_CS0: U10.4 (1~Y0); also elsewhere on the board
RPI_CS1: U10.5 (1~Y1); also elsewhere on the board
RPI_CS2: U10.6 (1~Y2); also elsewhere on the board
RPI_CS3: U10.7 (1~Y3); also elsewhere on the board
RPI_CS4: U10.12 (2~Y0); also elsewhere on the board
RPI_CS5: U10.11 (2~Y1); also elsewhere on the board
RPI_CS6: U10.10 (2~Y2); also elsewhere on the board
RPI_CS7: U10.9 (2~Y3); also elsewhere on the board
RTC_BATT: BAT1.+1 (V+), BAT1.+2 (V+), TP17.TP, U2.14 (VBAT)
SCL_3V3: PCB1.P$5 (GPIO3), R18.1, U1.12 (SCL), U2.16 (SCL); also elsewhere on the board
SDA_3V3: PCB1.P$3 (GPIO2), R19.1, U1.13 (SDA), U2.15 (SDA); also elsewhere on the board
SPI0_CS0: PCB1.P$24 (GPIO8), U10.1 (1~E)
SPI0_CS1: PCB1.P$26 (GPIO7), U10.15 (2~E)
SPI_GPIO1: PCB1.P$11 (GPIO17), U10.2 (1A0)
SPI_GPIO2: PCB1.P$13 (GPIO27), U10.3 (1A1)
SPI_GPIO3: PCB1.P$15 (GPIO22), U10.14 (2A0)
SPI_GPIO4: PCB1.P$16 (GPIO23), U10.13 (2A1)
SPI_MISO: PCB1.P$21 (GPIO9); also elsewhere on the board
SPI_MOSI: PCB1.P$19 (GPIO10); also elsewhere on the board
SPI_SCLK: PCB1.P$23 (GPIO11); also elsewhere on the board

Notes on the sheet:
Pi & Digital
Port Expander
SPI Mux
RTC
I2C Pullups
Do we want this permenantly powered given the Pi can be switched? What's the battery life like?
RPI has 1.8K pull up resistors for i2c
the only battery holder on seeed
ID EEPROM
Address: 0100000
DHT22
FREE RPI GPIOs
Address 0x68

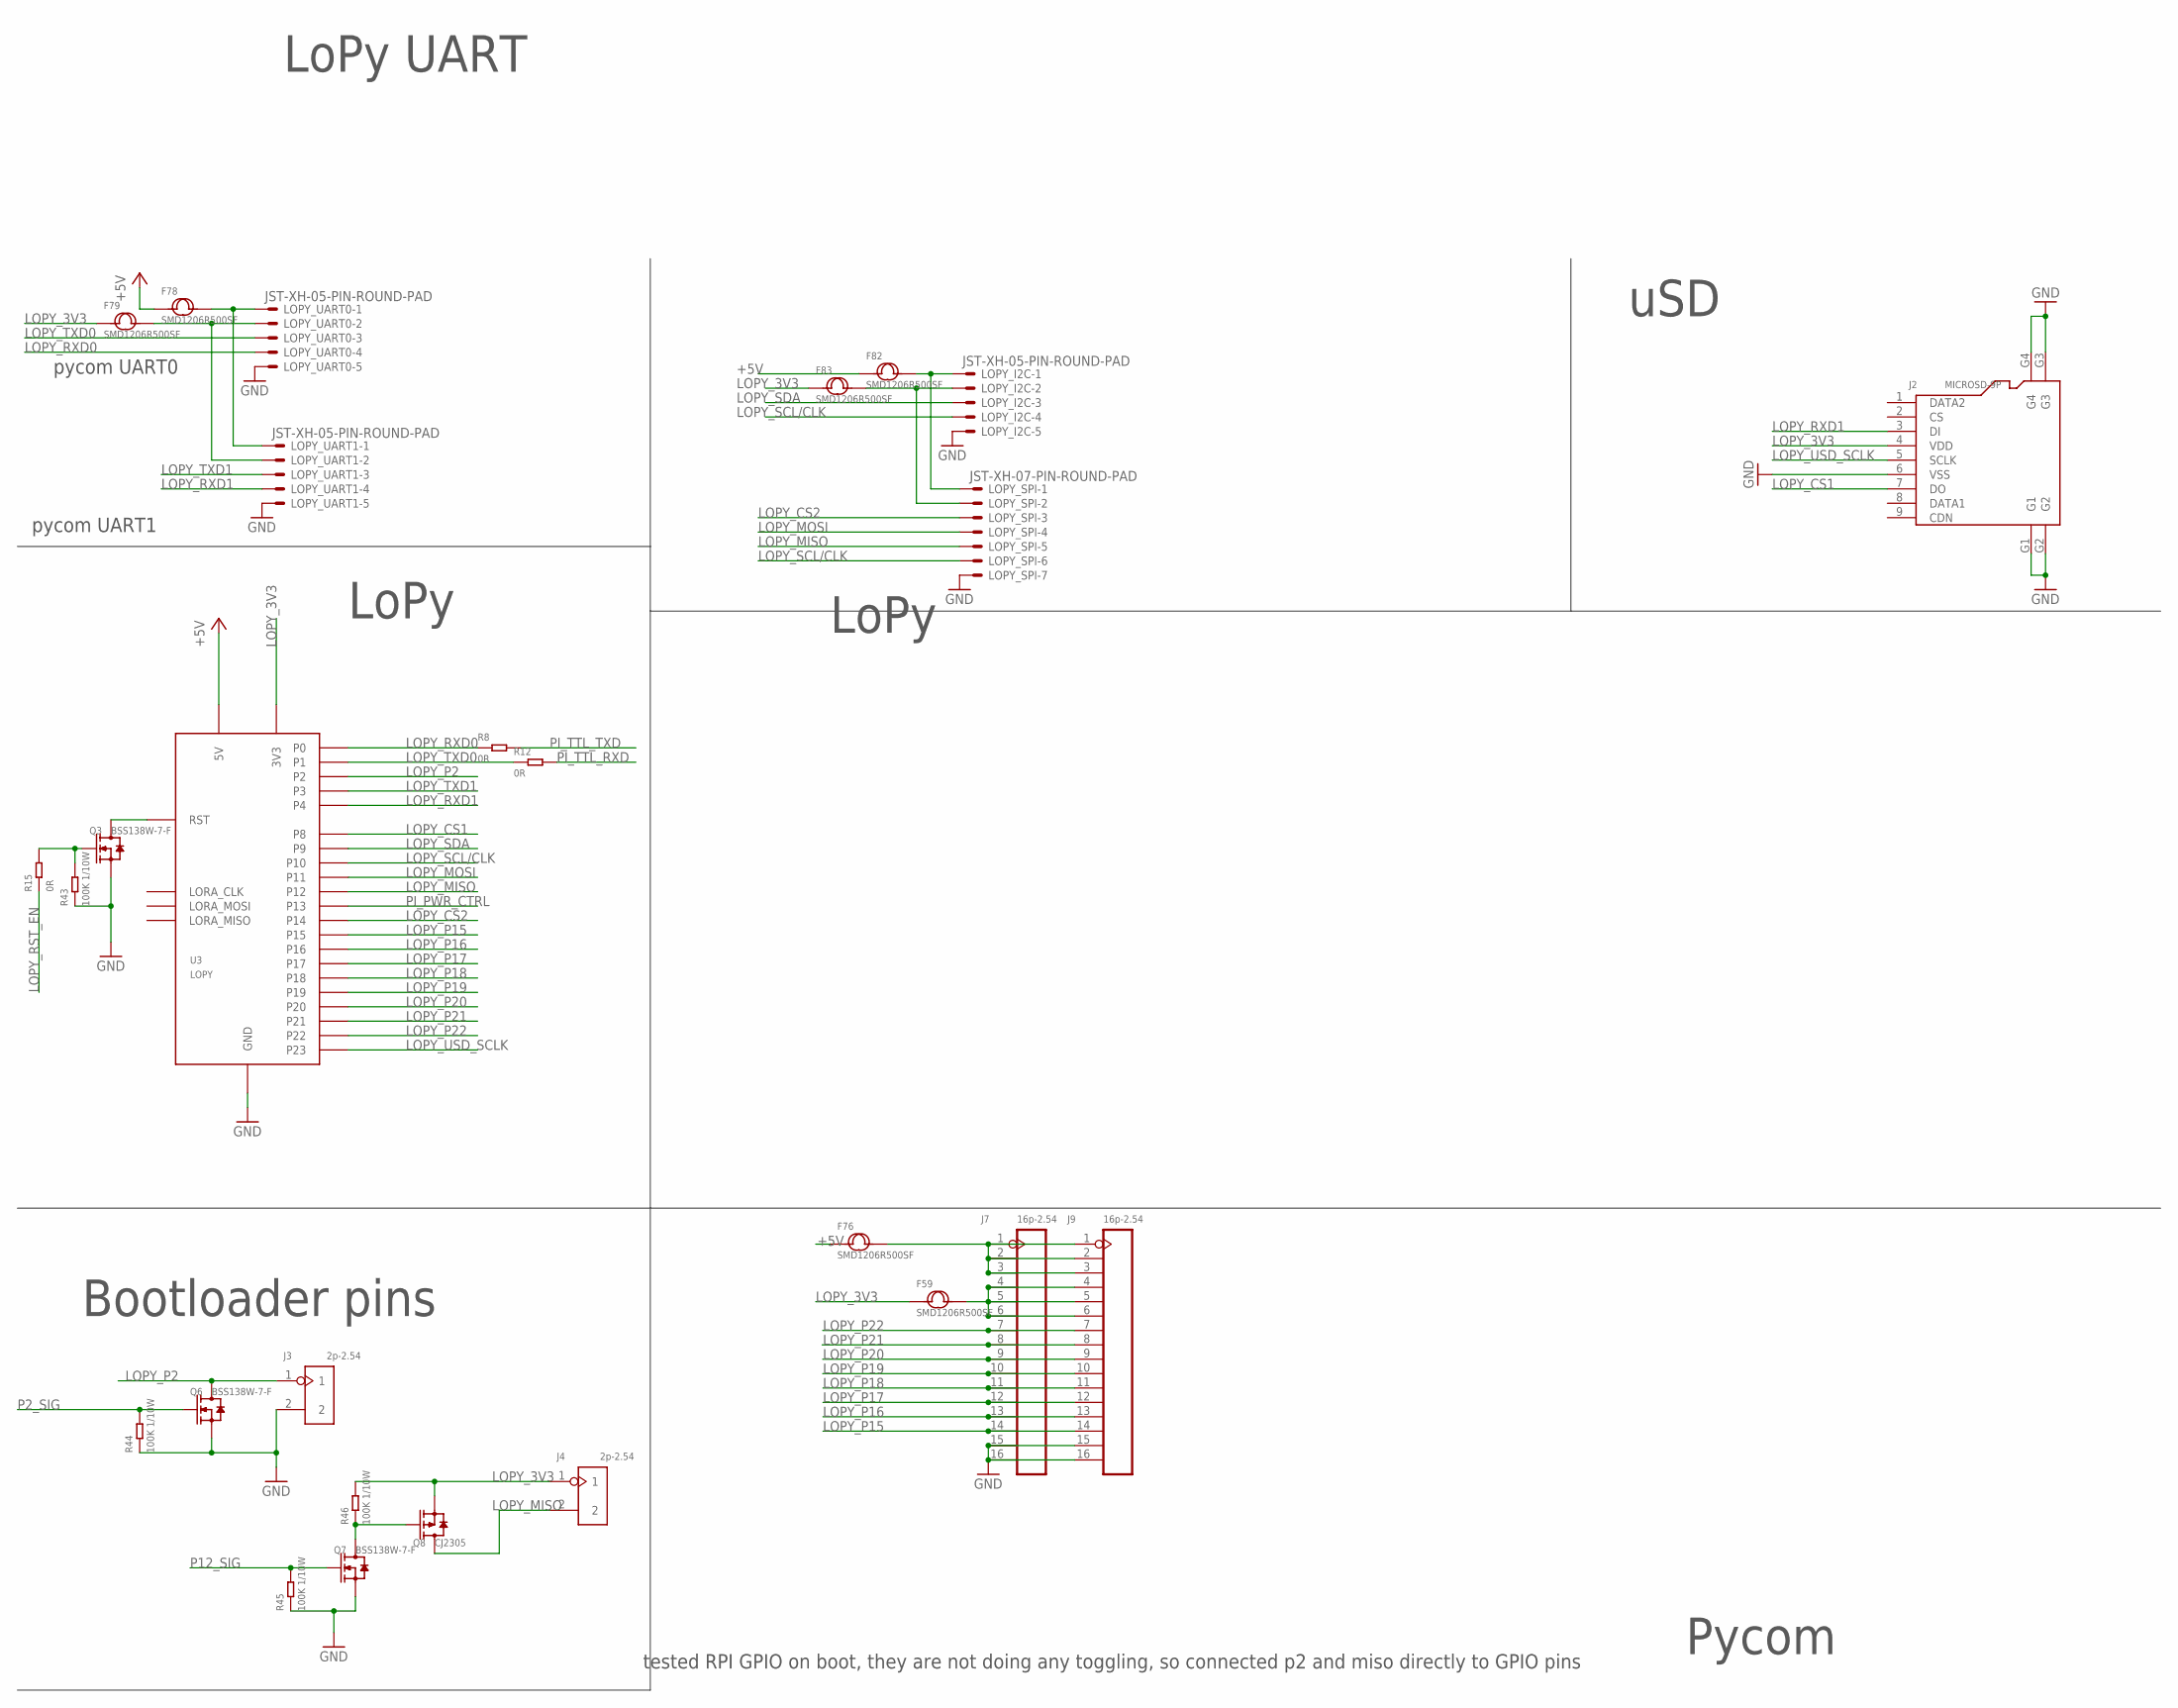
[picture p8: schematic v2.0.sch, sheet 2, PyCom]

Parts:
F59, F76, F78, F79, F82, F83: SMD1206R500SF; F1206
J2: MICROSD-9P; MICRO-SD9+4P-SMD-16.1X14.5X1.85MM
J3, J4: 2p-2.54; H2-2.54
J7, J9: 16p-2.54; H16-2.54
LOPY_I2C: JST-XH-05-PIN-ROUND-PAD; JST-XH-05-PACKAGE-ROUND-PAD
LOPY_SPI: JST-XH-07-PIN-ROUND-PAD; JST-XH-07-PACKAGE-ROUND-PAD
LOPY_UART0, LOPY_UART1: JST-XH-05-PIN-ROUND-PAD; JST-XH-05-PACKAGE-ROUND-PAD
Q3, Q6, Q7: BSS138W-7-F; SOT-23
Q8: CJ2305; SOT-23
R8, R12, R15: 0R; R0603
R43, R44, R45, R46: 100K 1/10W; R0603
U3: LOPY

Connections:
+5V: F76.1, F78.1, F82.1, U3.P$28 (5V); also elsewhere on the board
GND: J2.6 (VSS), J2.G1, J2.G2, J2.G3, J2.G4, J3.2, J7.15, J7.16, J9.15, J9.16, LOPY_I2C.5, LOPY_SPI.7, LOPY_UART0.5, LOPY_UART1.5, Q3.2 (S), Q6.2 (S), Q7.2 (S), R43.1, R44.1, R45.1, U3.P$27 (GND); also elsewhere on the board
LOPY_3V3: F59.1, F79.1, F83.1, J2.4 (VDD), J4.1, Q8.2 (S), R46.2, U3.P$26 (3V3); also elsewhere on the board
LOPY_3V3_FUSED: F59.2, J7.4, J7.5, J7.6, J9.4, J9.5, J9.6
LOPY_5V_FUSED: F76.2, J7.1, J7.2, J7.3, J9.1, J9.2, J9.3
LOPY_CS1: J2.7 (DO), U3.P$10 (P8)
LOPY_CS2: LOPY_SPI.3, U3.P$16 (P14)
LOPY_I2C_3V3_PROTECTED: F83.2, LOPY_I2C.2, LOPY_SPI.2
LOPY_MISO: J4.2, LOPY_SPI.5, Q8.3 (D), U3.P$14 (P12)
LOPY_MOSI: LOPY_SPI.4, U3.P$13 (P11)
LOPY_P2: J3.1, Q6.3 (D), U3.P$4 (P2)
LOPY_P15: J7.14, J9.14, U3.P$17 (P15)
LOPY_P16: J7.13, J9.13, U3.P$18 (P16)
LOPY_P17: J7.12, J9.12, U3.P$19 (P17)
LOPY_P18: J7.11, J9.11, U3.P$20 (P18)
LOPY_P19: J7.10, J9.10, U3.P$21 (P19)
LOPY_P20: J7.9, J9.9, U3.P$22 (P20)
LOPY_P21: J7.8, J9.8, U3.P$23 (P21)
LOPY_P22: J7.7, J9.7, U3.P$24 (P22)
LOPY_RST: Q3.3 (D), U3.P$1 (RST)
LOPY_RST_EN: R15.1; also elsewhere on the board
LOPY_RXD0: LOPY_UART0.4, R8.1, U3.P$2 (P0)
LOPY_RXD1: J2.3 (DI), LOPY_UART1.4, U3.P$6 (P4)
LOPY_SCL/CLK: LOPY_I2C.4, LOPY_SPI.6, U3.P$12 (P10)
LOPY_SDA: LOPY_I2C.3, U3.P$11 (P9)
LOPY_TXD0: LOPY_UART0.3, R12.1, U3.P$3 (P1)
LOPY_TXD1: LOPY_UART1.3, U3.P$5 (P3)
LOPY_UART0_3V3_PROTECTED: F79.2, LOPY_UART0.2, LOPY_UART1.2
LOPY_UART0_5V_PROTECTED: F78.2, LOPY_UART0.1, LOPY_UART1.1
LOPY_USD_SCLK: J2.5 (SCLK), U3.P$25 (P23)
unnamed: F82.2, LOPY_I2C.1, LOPY_SPI.1
unnamed: Q3.1 (G), R15.2, R43.2
unnamed: Q7.3 (D), Q8.1 (G), R46.1
P2_SIG: Q6.1 (G), R44.2; also elsewhere on the board
P12_SIG: Q7.1 (G), R45.2; also elsewhere on the board
PI_PWR_CTRL: U3.P$15 (P13); also elsewhere on the board
PI_TTL_RXD: R12.2; also elsewhere on the board
PI_TTL_TXD: R8.2; also elsewhere on the board

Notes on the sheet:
Pycom
pycom UART1
pycom UART0
LoPy
LoPy UART
uSD
tested RPI GPIO on boot, they are not doing any toggling, so connected p2 and miso directly to GPIO pins
Bootloader pins

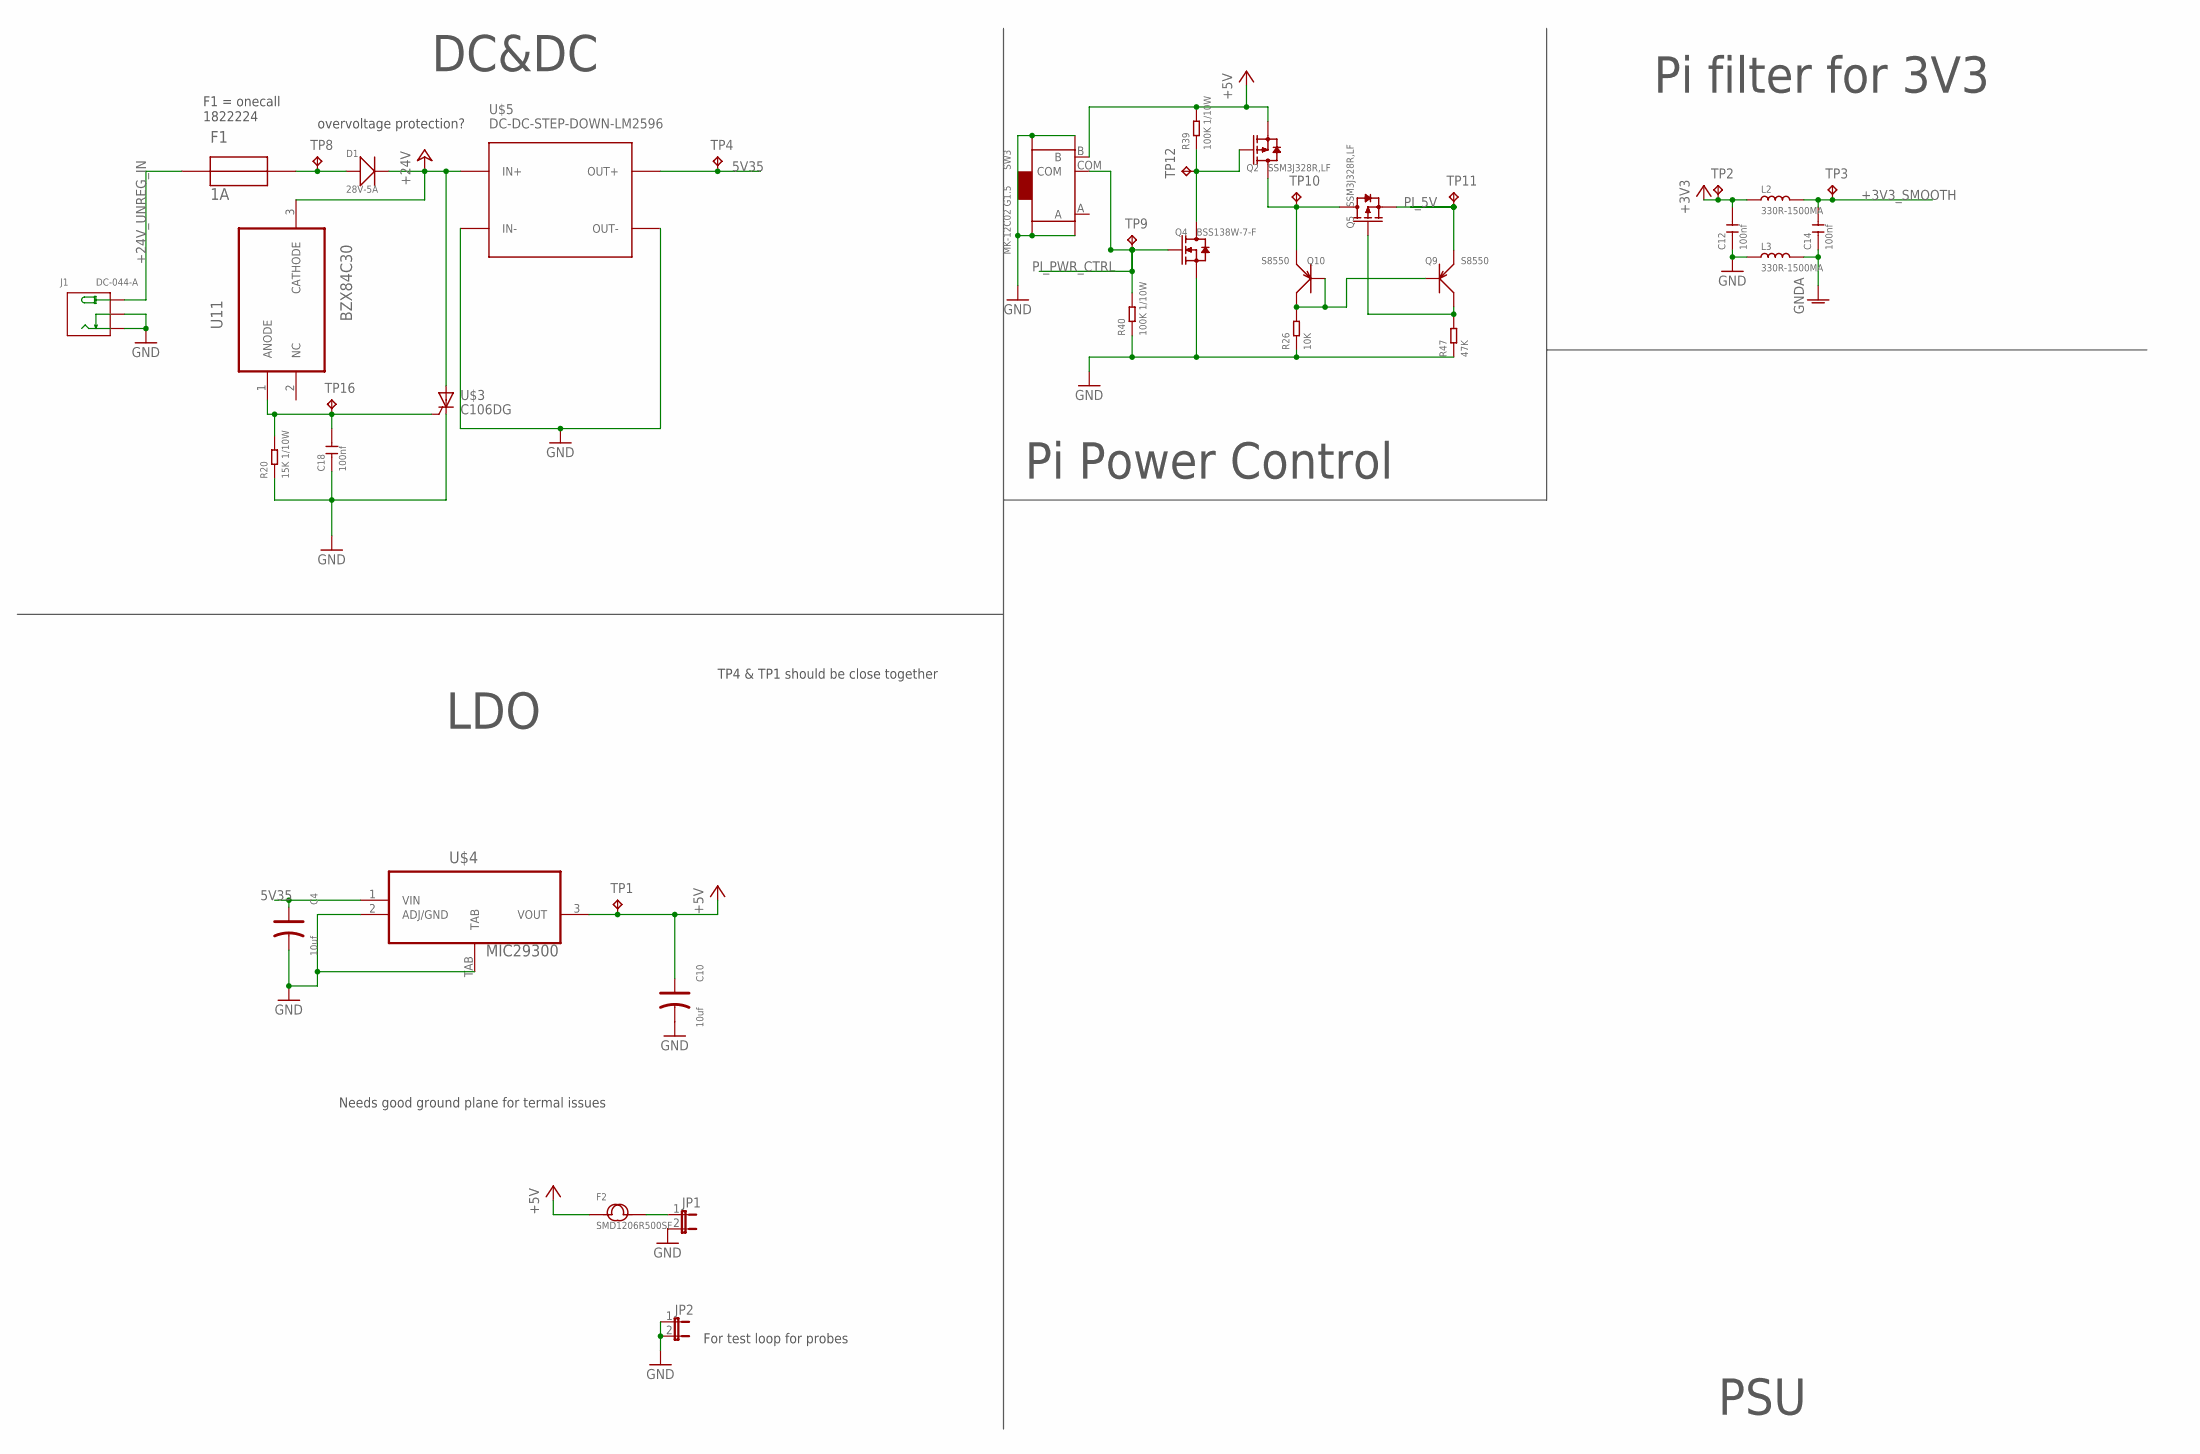
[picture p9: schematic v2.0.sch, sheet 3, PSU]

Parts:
C4, C10: 10uf; AVX-A
C12, C14, C18: 100nf; C0603
D1: 28V-5A; DO-214AA
F1: 1A; 2920
F2: SMD1206R500SF; F1206
J1: DC-044-A; DCJ3P-11.6X9.6X7.0MM
JP1, JP2: JP1E; JP1
L2, L3: 330R-1500MA; L0805
Q2, Q5: SSM3J328R,LF; SOT-23
Q4: BSS138W-7-F; SOT-23
Q9, Q10: S8550; SOT-23
R20: 15K 1/10W; R0603
R26: 10K; R0603
R39, R40: 100K 1/10W; R0603
R47: 47K; R0603
SW3: MK-12C02 G1.5; SW7-SMD-L6.7X2.7X3.2MM
TP1, TP2, TP3, TP4, TP8, TP9, TP10, TP11, TP12, TP16: TPB2,54; B2,54
U11: BZX84C30; SOT91P240X110-3N
U$3: C106DG; TO-225AA
U$4: MIC29300; TO-263
U$5: DC-DC-STEP-DOWN-LM2596

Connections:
5V35: C4.+, TP4.TP, U$4.1 (VIN), U$5.OUT+; also elsewhere on the board
+3V3: C12.2, L2.1, TP2.TP; also elsewhere on the board
+3V3_SMOOTH: C14.2, L2.2, TP3.TP; also elsewhere on the board
+5V: C10.+, F2.1, Q2.2 (S), R39.2, SW3.B, TP1.TP, U$4.3 (VOUT); also elsewhere on the board
+24V: D1.-, U11.3 (CATHODE), U$3.2 (A), U$5.IN+; also elsewhere on the board
+24V_UNREG_IN: F1.1, J1.+
GND: C4.-, C10.-, C12.1, C18.1, J1.-, J1.CDN, JP1.2, JP2.1, JP2.2, L3.1, Q4.2 (S), R20.1, R26.1, R40.1, R47.1, SW3.SS1, SW3.SS2, SW3.SS3, SW3.SS4, U$3.1 (C), U$4.2 (ADJ/GND), U$4.TAB, U$5.IN-, U$5.OUT-; also elsewhere on the board
GNDA: C14.1, L3.2; also elsewhere on the board
unnamed: F2.2, JP1.1
unnamed: Q9.1 (B), Q10.1 (B), Q10.3 (C), R26.2
unnamed: Q5.1 (G), Q9.3 (C), R47.2
unnamed: D1.+, F1.2, TP8.TP
unnamed: C18.2, R20.2, TP16.TP, U11.1 (ANODE), U$3.3 (G1)
unnamed: Q2.3 (D), Q5.3 (D), Q10.2 (E), TP10.TP
unnamed: Q2.1 (G), Q4.3 (D), R39.1, TP12.TP
PI_5V: Q5.2 (S), Q9.2 (E), TP11.TP; also elsewhere on the board
PI_PWR_CTRL: Q4.1 (G), R40.2, SW3.COM, TP9.TP; also elsewhere on the board

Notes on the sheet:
PSU
LDO
DC&DC
Pi filter for 3V3
overvoltage protection?
Pi Power Control
Needs good ground plane for termal issues
TP4 & TP1 should be close together
F1 = onecall 1822224
For test loop for probes

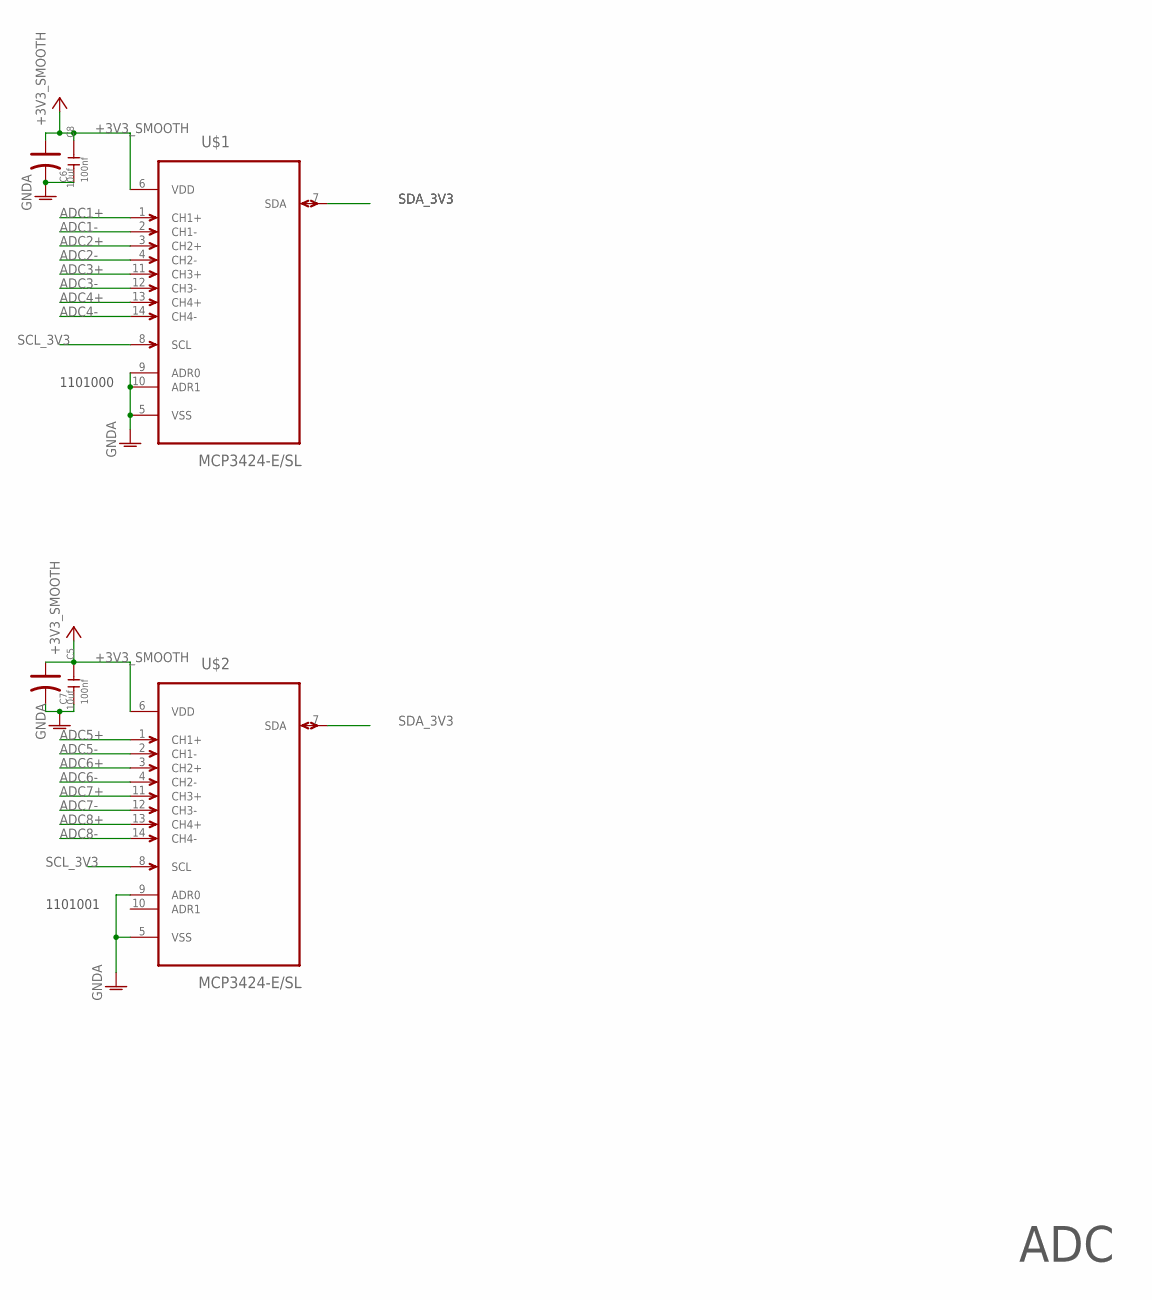
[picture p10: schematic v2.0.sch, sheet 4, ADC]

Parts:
C5, C8: 10uf; AVX-A
C6, C7: 100nf; C0603
U$1, U$2: MCP3424-E/SL; SOIC127P600X175-14N

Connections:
+3V3_SMOOTH: C5.+, C6.2, C7.2, C8.+, U$1.6 (VDD), U$2.6 (VDD); also elsewhere on the board
ADC1+: U$1.1 (CH1+); also elsewhere on the board
ADC1-: U$1.2 (CH1-); also elsewhere on the board
ADC2+: U$1.3 (CH2+); also elsewhere on the board
ADC2-: U$1.4 (CH2-); also elsewhere on the board
ADC3+: U$1.11 (CH3+); also elsewhere on the board
ADC3-: U$1.12 (CH3-); also elsewhere on the board
ADC4+: U$1.13 (CH4+); also elsewhere on the board
ADC4-: U$1.14 (CH4-); also elsewhere on the board
ADC5+: U$2.1 (CH1+); also elsewhere on the board
ADC5-: U$2.2 (CH1-); also elsewhere on the board
ADC6+: U$2.3 (CH2+); also elsewhere on the board
ADC6-: U$2.4 (CH2-); also elsewhere on the board
ADC7+: U$2.11 (CH3+); also elsewhere on the board
ADC7-: U$2.12 (CH3-); also elsewhere on the board
ADC8+: U$2.13 (CH4+); also elsewhere on the board
ADC8-: U$2.14 (CH4-); also elsewhere on the board
GNDA: C5.-, C6.1, C7.1, C8.-, U$1.5 (VSS), U$1.9 (ADR0), U$1.10 (ADR1), U$2.5 (VSS), U$2.9 (ADR0); also elsewhere on the board
SCL_3V3: U$1.8 (SCL), U$2.8 (SCL); also elsewhere on the board
SDA_3V3: U$1.7 (SDA), U$2.7 (SDA); also elsewhere on the board

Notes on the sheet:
ADC
1101000
1101001

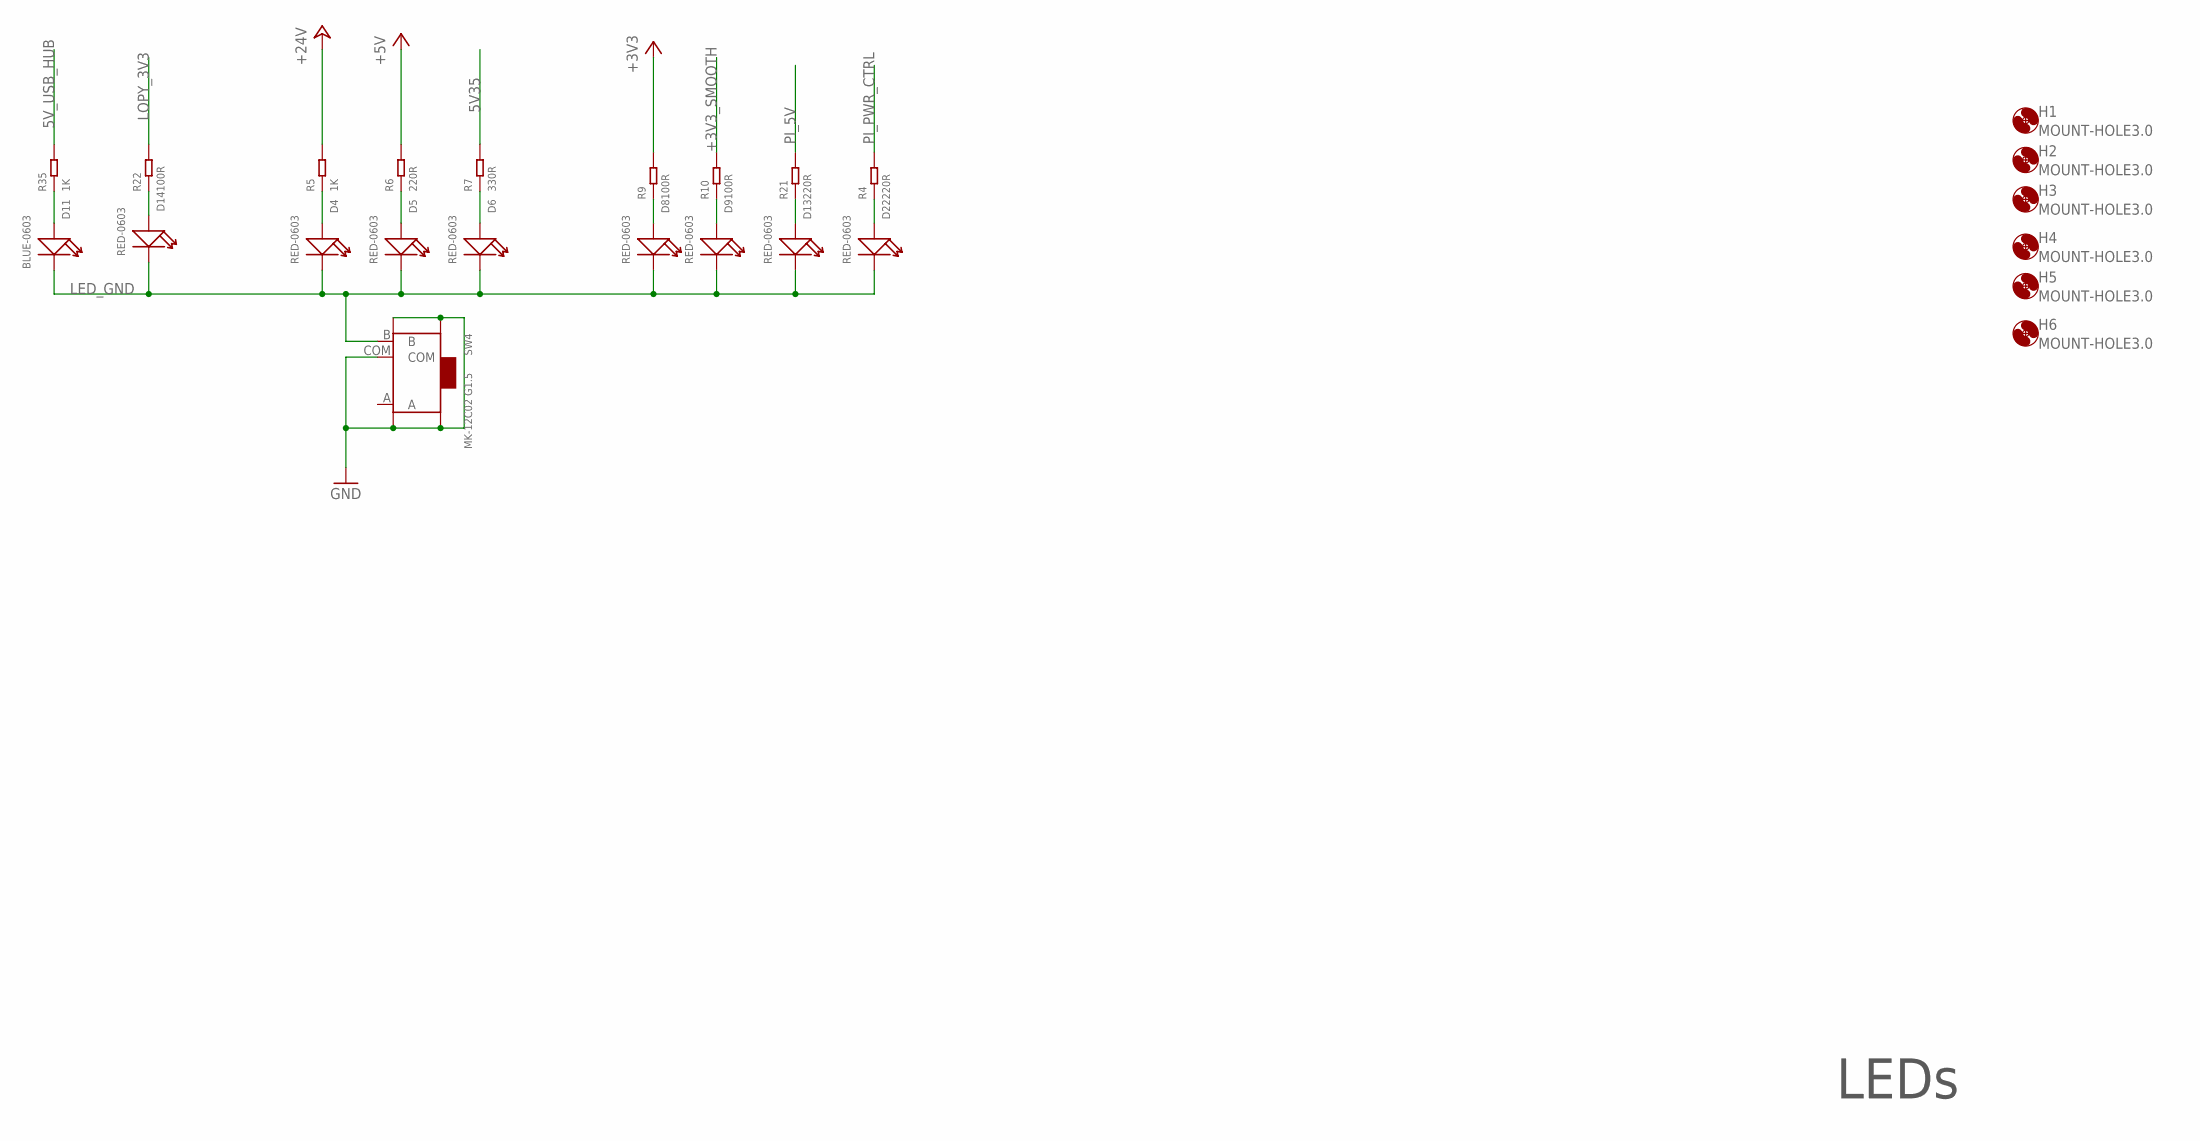
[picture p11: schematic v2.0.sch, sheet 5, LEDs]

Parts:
D4, D5, D6, D8, D9, D13, D14, D22: RED-0603; LED-0603
D11: BLUE-0603; LED-0603
H1, H2, H3, H4, H5, H6: MOUNT-HOLE3.0; 3,0
R4, R6, R21: 220R; R0603
R5, R35: 1K; R0603
R7: 330R; R0603
R9, R10, R22: 100R; R0603
SW4: MK-12C02 G1.5; SW7-SMD-L6.7X2.7X3.2MM

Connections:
5V35: R7.2; also elsewhere on the board
5V_USB_HUB: R35.2; also elsewhere on the board
+3V3: R9.2; also elsewhere on the board
+3V3_SMOOTH: R10.2; also elsewhere on the board
+5V: R6.2; also elsewhere on the board
+24V: R5.2; also elsewhere on the board
GND: SW4.COM, SW4.SS1, SW4.SS2, SW4.SS3, SW4.SS4; also elsewhere on the board
LED_GND: D4.-, D5.-, D6.-, D8.-, D9.-, D11.-, D13.-, D14.-, D22.-, SW4.B; also elsewhere on the board
LOPY_3V3: R22.2; also elsewhere on the board
unnamed: D22.+, R4.1
unnamed: D9.+, R10.1
unnamed: D8.+, R9.1
unnamed: D6.+, R7.1
unnamed: D5.+, R6.1
unnamed: D4.+, R5.1
unnamed: D11.+, R35.1
unnamed: D14.+, R22.1
unnamed: D13.+, R21.1
PI_5V: R21.2; also elsewhere on the board
PI_PWR_CTRL: R4.2; also elsewhere on the board

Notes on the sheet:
LEDs

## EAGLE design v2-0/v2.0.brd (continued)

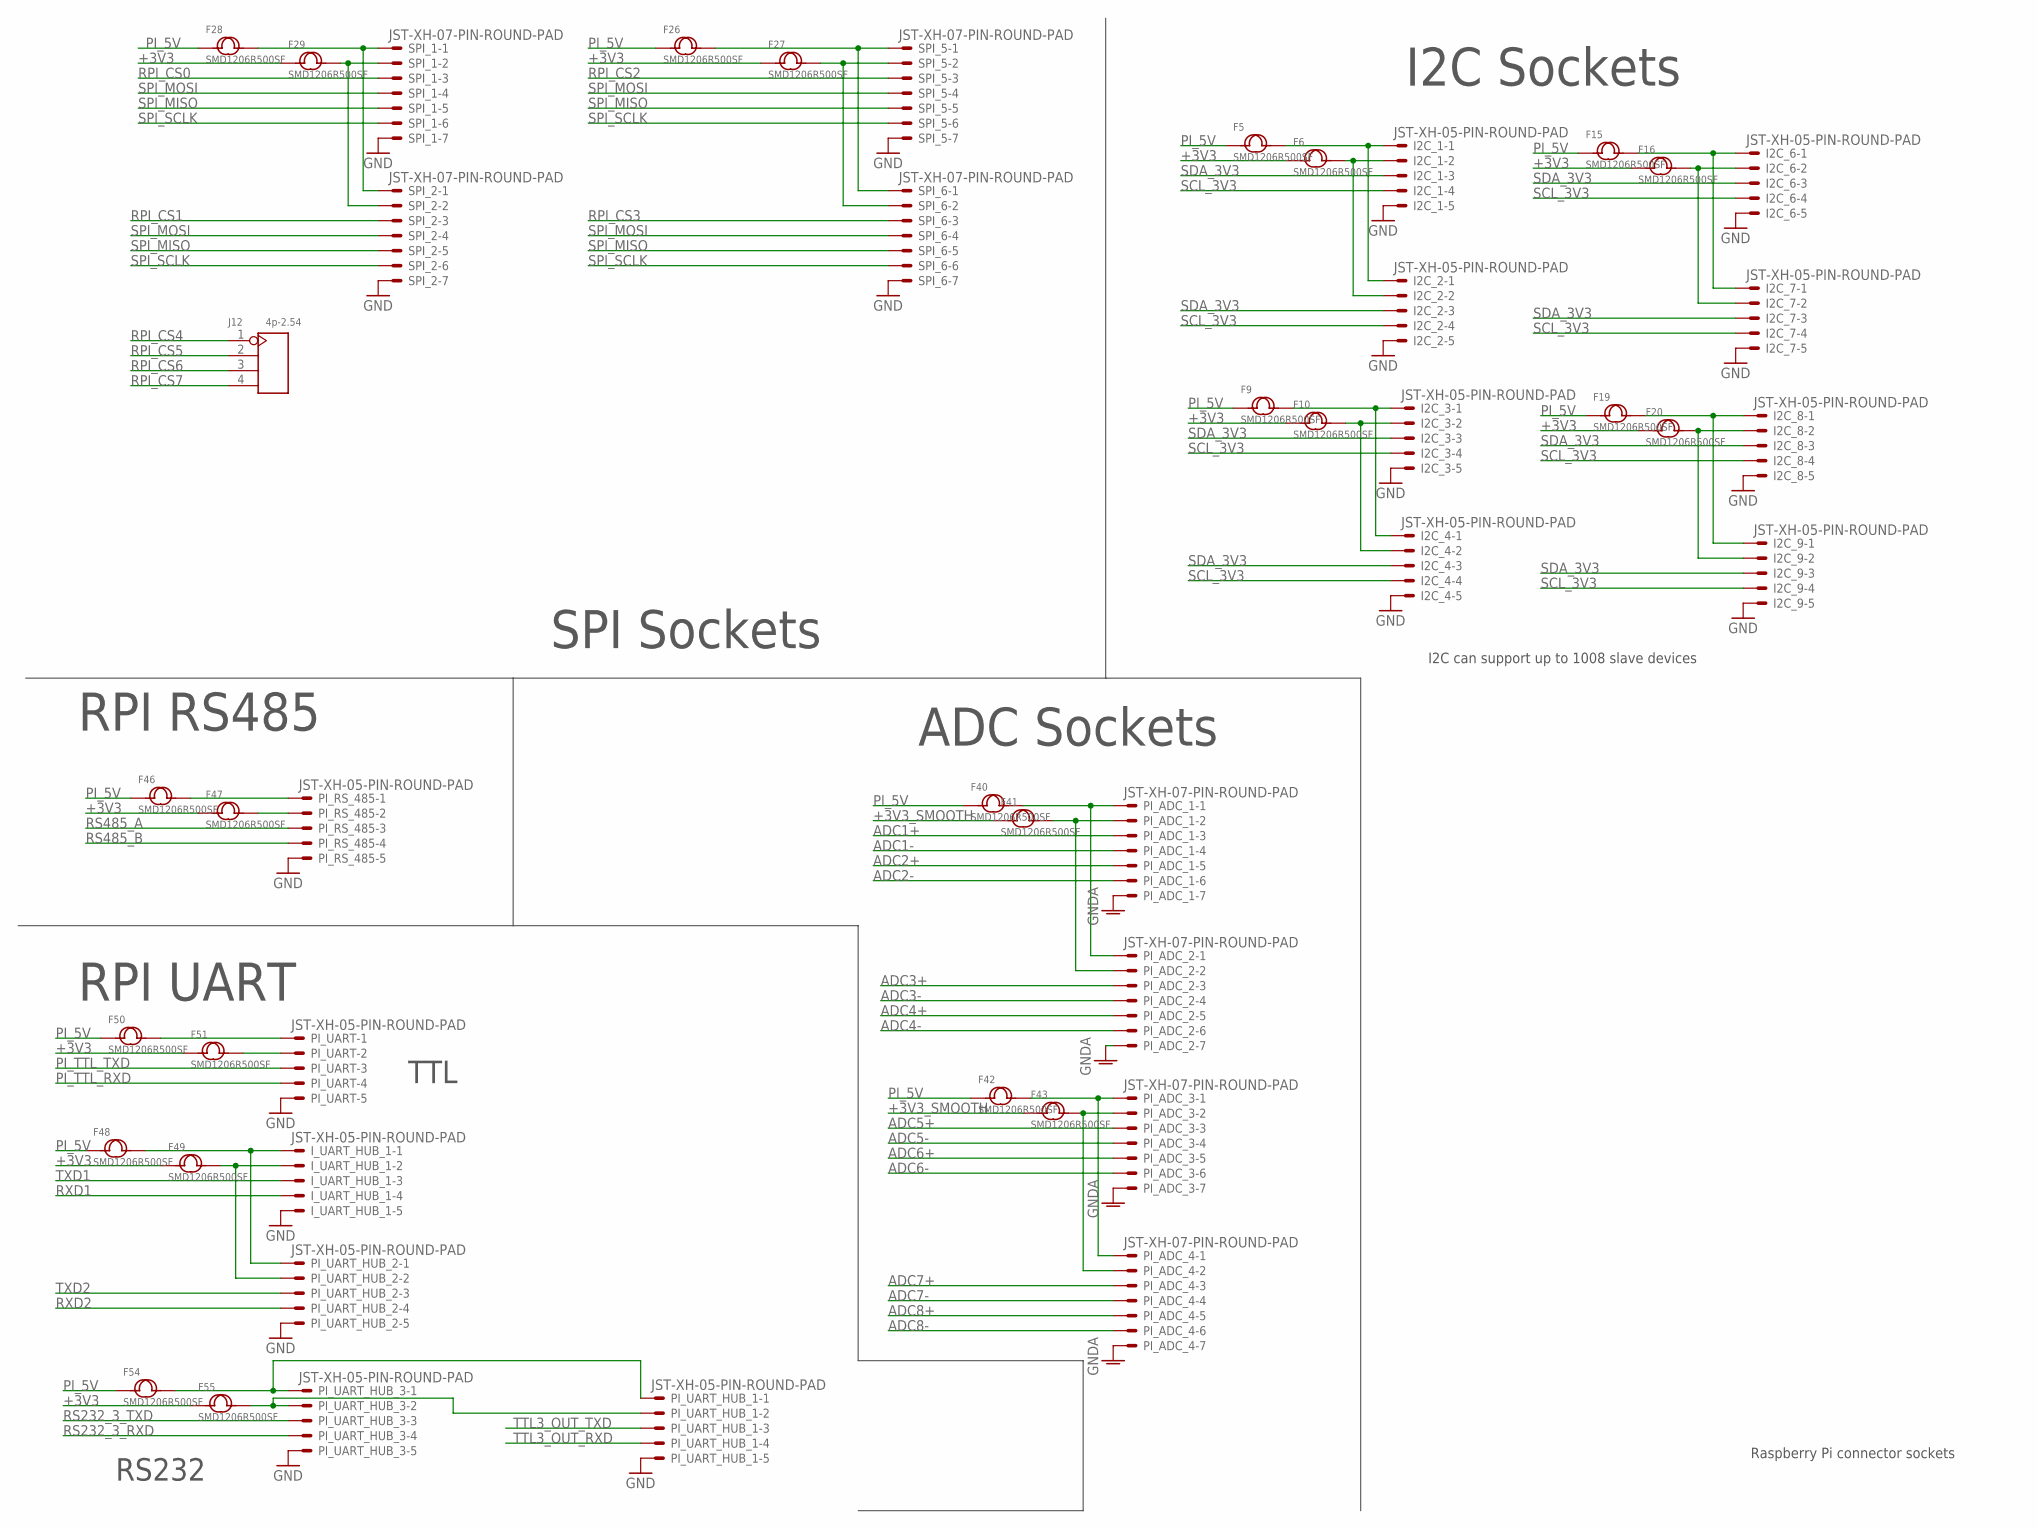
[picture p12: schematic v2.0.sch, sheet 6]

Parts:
F5, F6, F9, F10, F15, F16, F19, F20, F26, F27, F28, F29, F40, F41, F42, F43, F46, F47, F48, F49, F50, F51, F54, F55: SMD1206R500SF; F1206
I2C_1, I2C_2, I2C_3, I2C_4, I2C_6, I2C_7, I2C_8, I2C_9: JST-XH-05-PIN-ROUND-PAD; JST-XH-05-PACKAGE-ROUND-PAD
I_UART_HUB_1: JST-XH-05-PIN-ROUND-PAD; JST-XH-05-PACKAGE-ROUND-PAD
J12: 4p-2.54; H4-2.54
PI_ADC_1, PI_ADC_2, PI_ADC_3, PI_ADC_4: JST-XH-07-PIN-ROUND-PAD; JST-XH-07-PACKAGE-ROUND-PAD
PI_RS_485: JST-XH-05-PIN-ROUND-PAD; JST-XH-05-PACKAGE-ROUND-PAD
PI_UART: JST-XH-05-PIN-ROUND-PAD; JST-XH-05-PACKAGE-ROUND-PAD
PI_UART_HUB_1, PI_UART_HUB_2, PI_UART_HUB_3: JST-XH-05-PIN-ROUND-PAD; JST-XH-05-PACKAGE-ROUND-PAD
SPI_1, SPI_2, SPI_5, SPI_6: JST-XH-07-PIN-ROUND-PAD; JST-XH-07-PACKAGE-ROUND-PAD

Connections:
+3V3: F6.1, F10.1, F16.1, F20.1, F27.1, F29.1, F47.1, F49.1, F51.1, F55.1; also elsewhere on the board
+3V3_SMOOTH: F41.1, F43.1; also elsewhere on the board
ADC1+: PI_ADC_1.3; also elsewhere on the board
ADC1-: PI_ADC_1.4; also elsewhere on the board
ADC2+: PI_ADC_1.5; also elsewhere on the board
ADC2-: PI_ADC_1.6; also elsewhere on the board
ADC3+: PI_ADC_2.3; also elsewhere on the board
ADC3-: PI_ADC_2.4; also elsewhere on the board
ADC4+: PI_ADC_2.5; also elsewhere on the board
ADC4-: PI_ADC_2.6; also elsewhere on the board
ADC5+: PI_ADC_3.3; also elsewhere on the board
ADC5-: PI_ADC_3.4; also elsewhere on the board
ADC6+: PI_ADC_3.5; also elsewhere on the board
ADC6-: PI_ADC_3.6; also elsewhere on the board
ADC7+: PI_ADC_4.3; also elsewhere on the board
ADC7-: PI_ADC_4.4; also elsewhere on the board
ADC8+: PI_ADC_4.5; also elsewhere on the board
ADC8-: PI_ADC_4.6; also elsewhere on the board
ADC_1_3V3_P: F41.2, PI_ADC_1.2, PI_ADC_2.2
ADC_1_5V_P: F40.2, PI_ADC_1.1, PI_ADC_2.1
ADC_3_5V_P: F42.2, PI_ADC_3.1, PI_ADC_4.1
ADC_4_3V3_P: F43.2, PI_ADC_3.2, PI_ADC_4.2
GND: I2C_1.5, I2C_2.5, I2C_3.5, I2C_4.5, I2C_6.5, I2C_7.5, I2C_8.5, I2C_9.5, I_UART_HUB_1.5, PI_RS_485.5, PI_UART.5, PI_UART_HUB_1.5, PI_UART_HUB_2.5, PI_UART_HUB_3.5, SPI_1.7, SPI_2.7, SPI_5.7, SPI_6.7; also elsewhere on the board
GNDA: PI_ADC_1.7, PI_ADC_2.7, PI_ADC_3.7, PI_ADC_4.7; also elsewhere on the board
PI_5V: F5.1, F9.1, F15.1, F19.1, F26.1, F28.1, F40.1, F42.1, F46.1, F48.1, F50.1, F54.1; also elsewhere on the board
PI_5V_SPI_1_P: F28.2, SPI_1.1, SPI_2.1
PI_I2C_3V3_2: F10.2, I2C_3.2, I2C_4.2
PI_I2C_3V3_3: F6.2, I2C_1.2, I2C_2.2
PI_I2C_3V3_6: F16.2, I2C_6.2, I2C_7.2
PI_I2C_3V3_8: F20.2, I2C_8.2, I2C_9.2
PI_I2C_5V_P: F5.2, I2C_1.1, I2C_2.1
PI_I2C_5V_P2: F9.2, I2C_3.1, I2C_4.1
PI_I2C_5V_P5: F15.2, I2C_6.1, I2C_7.1
PI_I2C_5V_P7: F19.2, I2C_8.1, I2C_9.1
PI_RS485_3V3_P: F47.2, PI_RS_485.2
PI_RS485_5V_P: F46.2, PI_RS_485.1
PI_SPI_3V3_1_P: F29.2, SPI_1.2, SPI_2.2
PI_TTL_RXD: PI_UART.4; also elsewhere on the board
PI_TTL_TXD: PI_UART.3; also elsewhere on the board
PI_UART_3V3_P: F51.2, PI_UART.2
PI_UART_5V_P: F50.2, PI_UART.1
PI_UART_HUB_1_3V3_P: F49.2, I_UART_HUB_1.2, PI_UART_HUB_2.2
PI_UART_HUB_1_5V_P: F48.2, I_UART_HUB_1.1, PI_UART_HUB_2.1
RPI_CS0: SPI_1.3; also elsewhere on the board
RPI_CS1: SPI_2.3; also elsewhere on the board
RPI_CS2: SPI_5.3; also elsewhere on the board
RPI_CS3: SPI_6.3; also elsewhere on the board
RPI_CS4: J12.1; also elsewhere on the board
RPI_CS5: J12.2; also elsewhere on the board
RPI_CS6: J12.3; also elsewhere on the board
RPI_CS7: J12.4; also elsewhere on the board
RS232_3_RXD: PI_UART_HUB_3.4; also elsewhere on the board
RS232_3_TXD: PI_UART_HUB_3.3; also elsewhere on the board
RS485_A: PI_RS_485.3; also elsewhere on the board
RS485_B: PI_RS_485.4; also elsewhere on the board
RXD1: I_UART_HUB_1.4; also elsewhere on the board
RXD2: PI_UART_HUB_2.4; also elsewhere on the board
SCL_3V3: I2C_1.4, I2C_2.4, I2C_3.4, I2C_4.4, I2C_6.4, I2C_7.4, I2C_8.4, I2C_9.4; also elsewhere on the board
SDA_3V3: I2C_1.3, I2C_2.3, I2C_3.3, I2C_4.3, I2C_6.3, I2C_7.3, I2C_8.3, I2C_9.3; also elsewhere on the board
SPI_3V3_5_P: F27.2, SPI_5.2, SPI_6.2
SPI_5V_5_P: F26.2, SPI_5.1, SPI_6.1
SPI_MISO: SPI_1.5, SPI_2.5, SPI_5.5, SPI_6.5; also elsewhere on the board
SPI_MOSI: SPI_1.4, SPI_2.4, SPI_5.4, SPI_6.4; also elsewhere on the board
SPI_SCLK: SPI_1.6, SPI_2.6, SPI_5.6, SPI_6.6; also elsewhere on the board
TTL3_OUT_RXD: PI_UART_HUB_1.4; also elsewhere on the board
TTL3_OUT_TXD: PI_UART_HUB_1.3; also elsewhere on the board
TXD1: I_UART_HUB_1.3; also elsewhere on the board
TXD2: PI_UART_HUB_2.3; also elsewhere on the board
UART_HUB_3_3V3_P: F55.2, PI_UART_HUB_1.2, PI_UART_HUB_3.2
UART_USB_HUB_3_5V: F54.2, PI_UART_HUB_1.1, PI_UART_HUB_3.1

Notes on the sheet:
Raspberry Pi connector sockets
I2C can support up to 1008 slave devices
ADC Sockets
RPI RS485
RPI UART
I2C Sockets
SPI Sockets
TTL
RS232

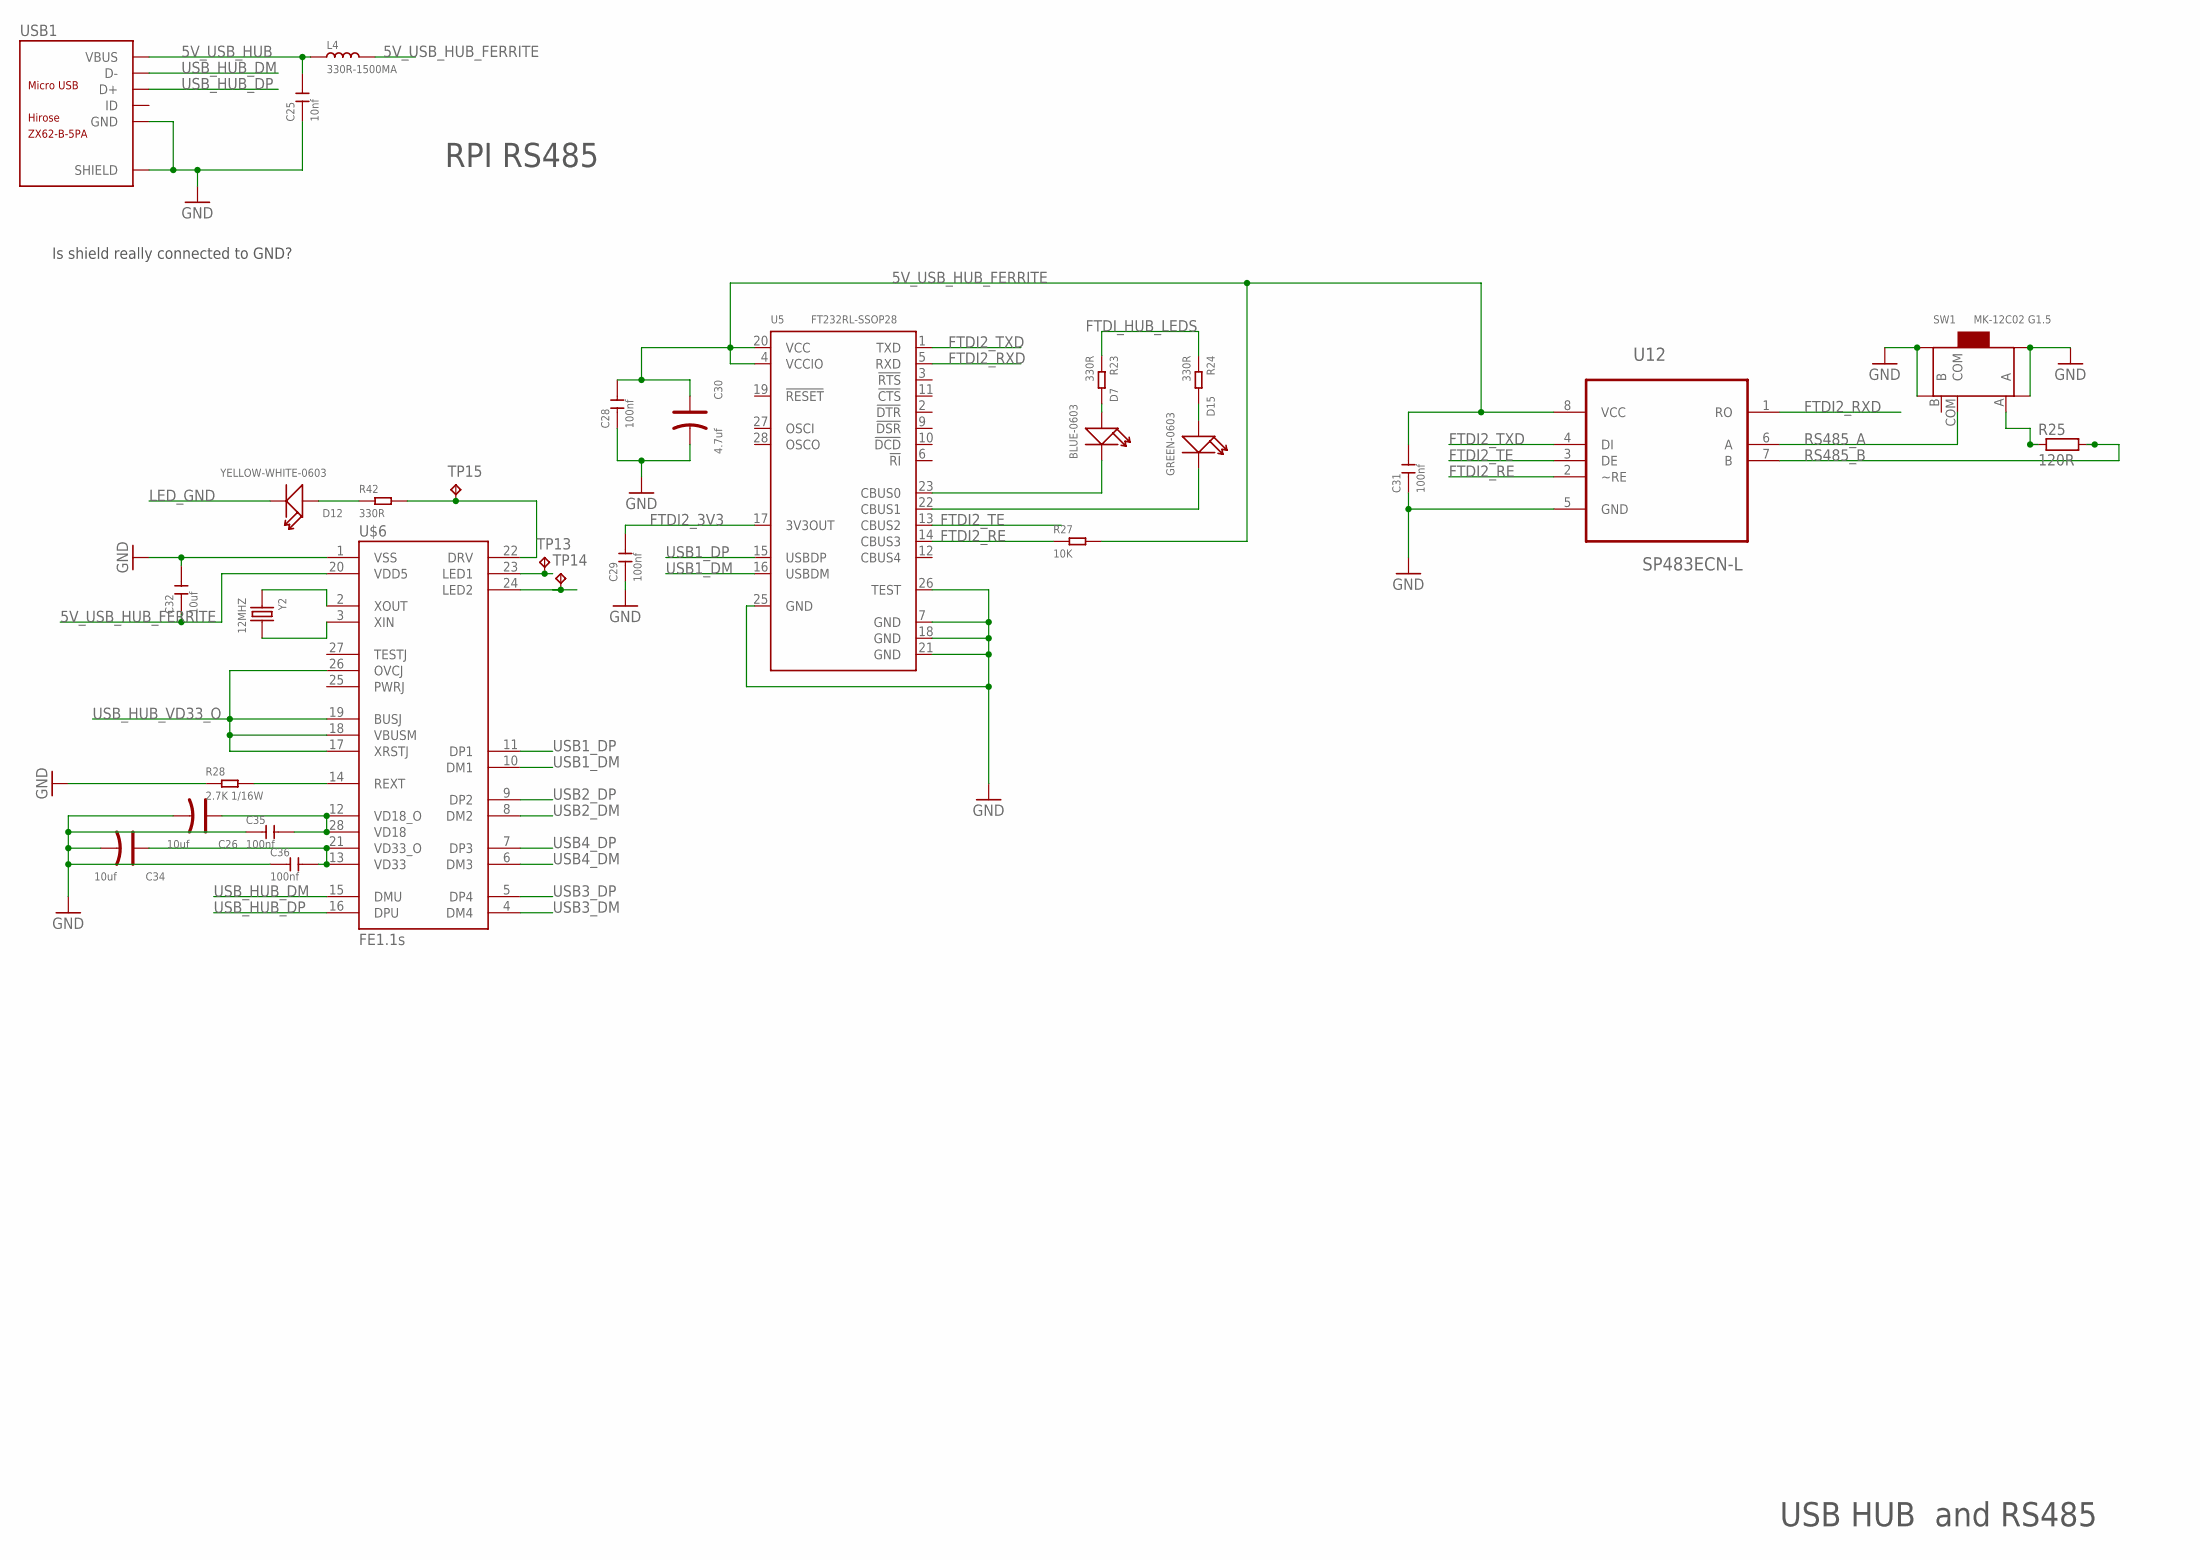
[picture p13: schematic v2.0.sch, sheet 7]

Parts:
C25: 10nf; C0603
C26, C34: 10uf; AVX-A
C28, C29, C31, C35, C36: 100nf; C0603
C30: 4.7uf; AVX-A
C32: 10uf; C0805
D7: BLUE-0603; LED-0603
D12: YELLOW-WHITE-0603; LED-0603
D15: GREEN-0603; LED-0603
L4: 330R-1500MA; L0805
R23, R24, R42: 330R; R0603
R25: 120R; R0603
R27: 10K; R0603
R28: 2.7K 1/16W; R0402
SW1: MK-12C02 G1.5; SW7-SMD-L6.7X2.7X3.2MM
TP13, TP14, TP15: TPB2,54; B2,54
U5: FT232RL-SSOP28; SSOP28-0.65-10.2X5.2MM
U12: SP483ECN-L; SOIC127P600X175-8N
U$6: FE1.1S; FE1.1S_SSOP-28
USB1: ZX62-B-5PA; MICRO-USB5+6P-SMD-0.65-AB
Y2: 12MHZ; X2-SMD-5.0X3.2X1.3MM

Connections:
5V_USB_HUB: C25.2, L4.1, USB1.1 (VBUS); also elsewhere on the board
5V_USB_HUB_FERRITE: C28.2, C30.+, C31.2, C32.1, L4.2, R27.2, U5.4 (VCCIO), U5.20 (VCC), U12.8 (VCC), U$6.20 (VDD5); also elsewhere on the board
FTDI2_3V3: C29.2, U5.17 (3V3OUT)
FTDI2_RE: R27.1, U5.14 (CBUS3), U12.2 (~RE)
FTDI2_RXD: U5.5 (RXD), U12.1 (RO)
FTDI2_TE: U5.13 (CBUS2), U12.3 (DE)
FTDI2_TXD: U5.1 (TXD), U12.4 (DI)
FTDI_HUB_LEDS: R23.1, R24.1; also elsewhere on the board
GND: C25.1, C26.-, C28.1, C29.1, C30.-, C31.1, C32.2, C34.-, C35.1, C36.1, R28.1, SW1.SS1, SW1.SS2, SW1.SS3, SW1.SS4, U5.7 (GND), U5.18 (GND), U5.21 (GND), U5.25 (GND), U5.26 (TEST), U12.5 (GND), U$6.1 (VSS), USB1.5 (GND), USB1.P1 (SHIELD), USB1.P2 (SHIELD), USB1.P3 (SHIELD), USB1.P4 (SHIELD), USB1.P5 (SHIELD), USB1.P6 (SHIELD); also elsewhere on the board
LED_GND: D12.-; also elsewhere on the board
unnamed: R25.1, SW1.A
unnamed: D15.+, R24.2
unnamed: D7.+, R23.2
unnamed: D12.+, R42.1
unnamed: U$6.2 (XOUT), Y2.1
unnamed: U$6.3 (XIN), Y2.2
unnamed: R28.2, U$6.14 (REXT)
unnamed: C26.+, C35.2, U$6.12 (VD18_O), U$6.28 (VD18)
unnamed: C34.+, C36.2, U$6.13 (VD33), U$6.21 (VD33_O)
RS485_A: SW1.COM, U12.6 (A); also elsewhere on the board
RS485_B: R25.2, U12.7 (B); also elsewhere on the board
RS485_CBUS0: D7.-, U5.23 (CBUS0)
RS485_CBUS2: D15.-, U5.22 (CBUS1)
USB1_DM: U5.16 (USBDM), U$6.10 (DM1)
USB1_DP: U5.15 (USBDP), U$6.11 (DP1)
USB2_DM: U$6.8 (DM2); also elsewhere on the board
USB2_DP: U$6.9 (DP2); also elsewhere on the board
USB3_DM: U$6.4 (DM4); also elsewhere on the board
USB3_DP: U$6.5 (DP4); also elsewhere on the board
USB4_DM: U$6.6 (DM3); also elsewhere on the board
USB4_DP: U$6.7 (DP3); also elsewhere on the board
USB_HUB_DM: U$6.15 (DMU), USB1.2 (D-)
USB_HUB_DP: U$6.16 (DPU), USB1.3 (D+)
USB_HUB_DRV: R42.2, TP15.TP, U$6.22 (DRV)
USB_HUB_LED1: TP13.TP, U$6.23 (LED1)
USB_HUB_LED2: TP14.TP, U$6.24 (LED2)
USB_HUB_VD33_O: U$6.17 (XRSTJ), U$6.18 (VBUSM), U$6.19 (BUSJ), U$6.26 (OVCJ)

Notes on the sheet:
RPI RS485
USB HUB and RS485
Is shield really connected to GND?

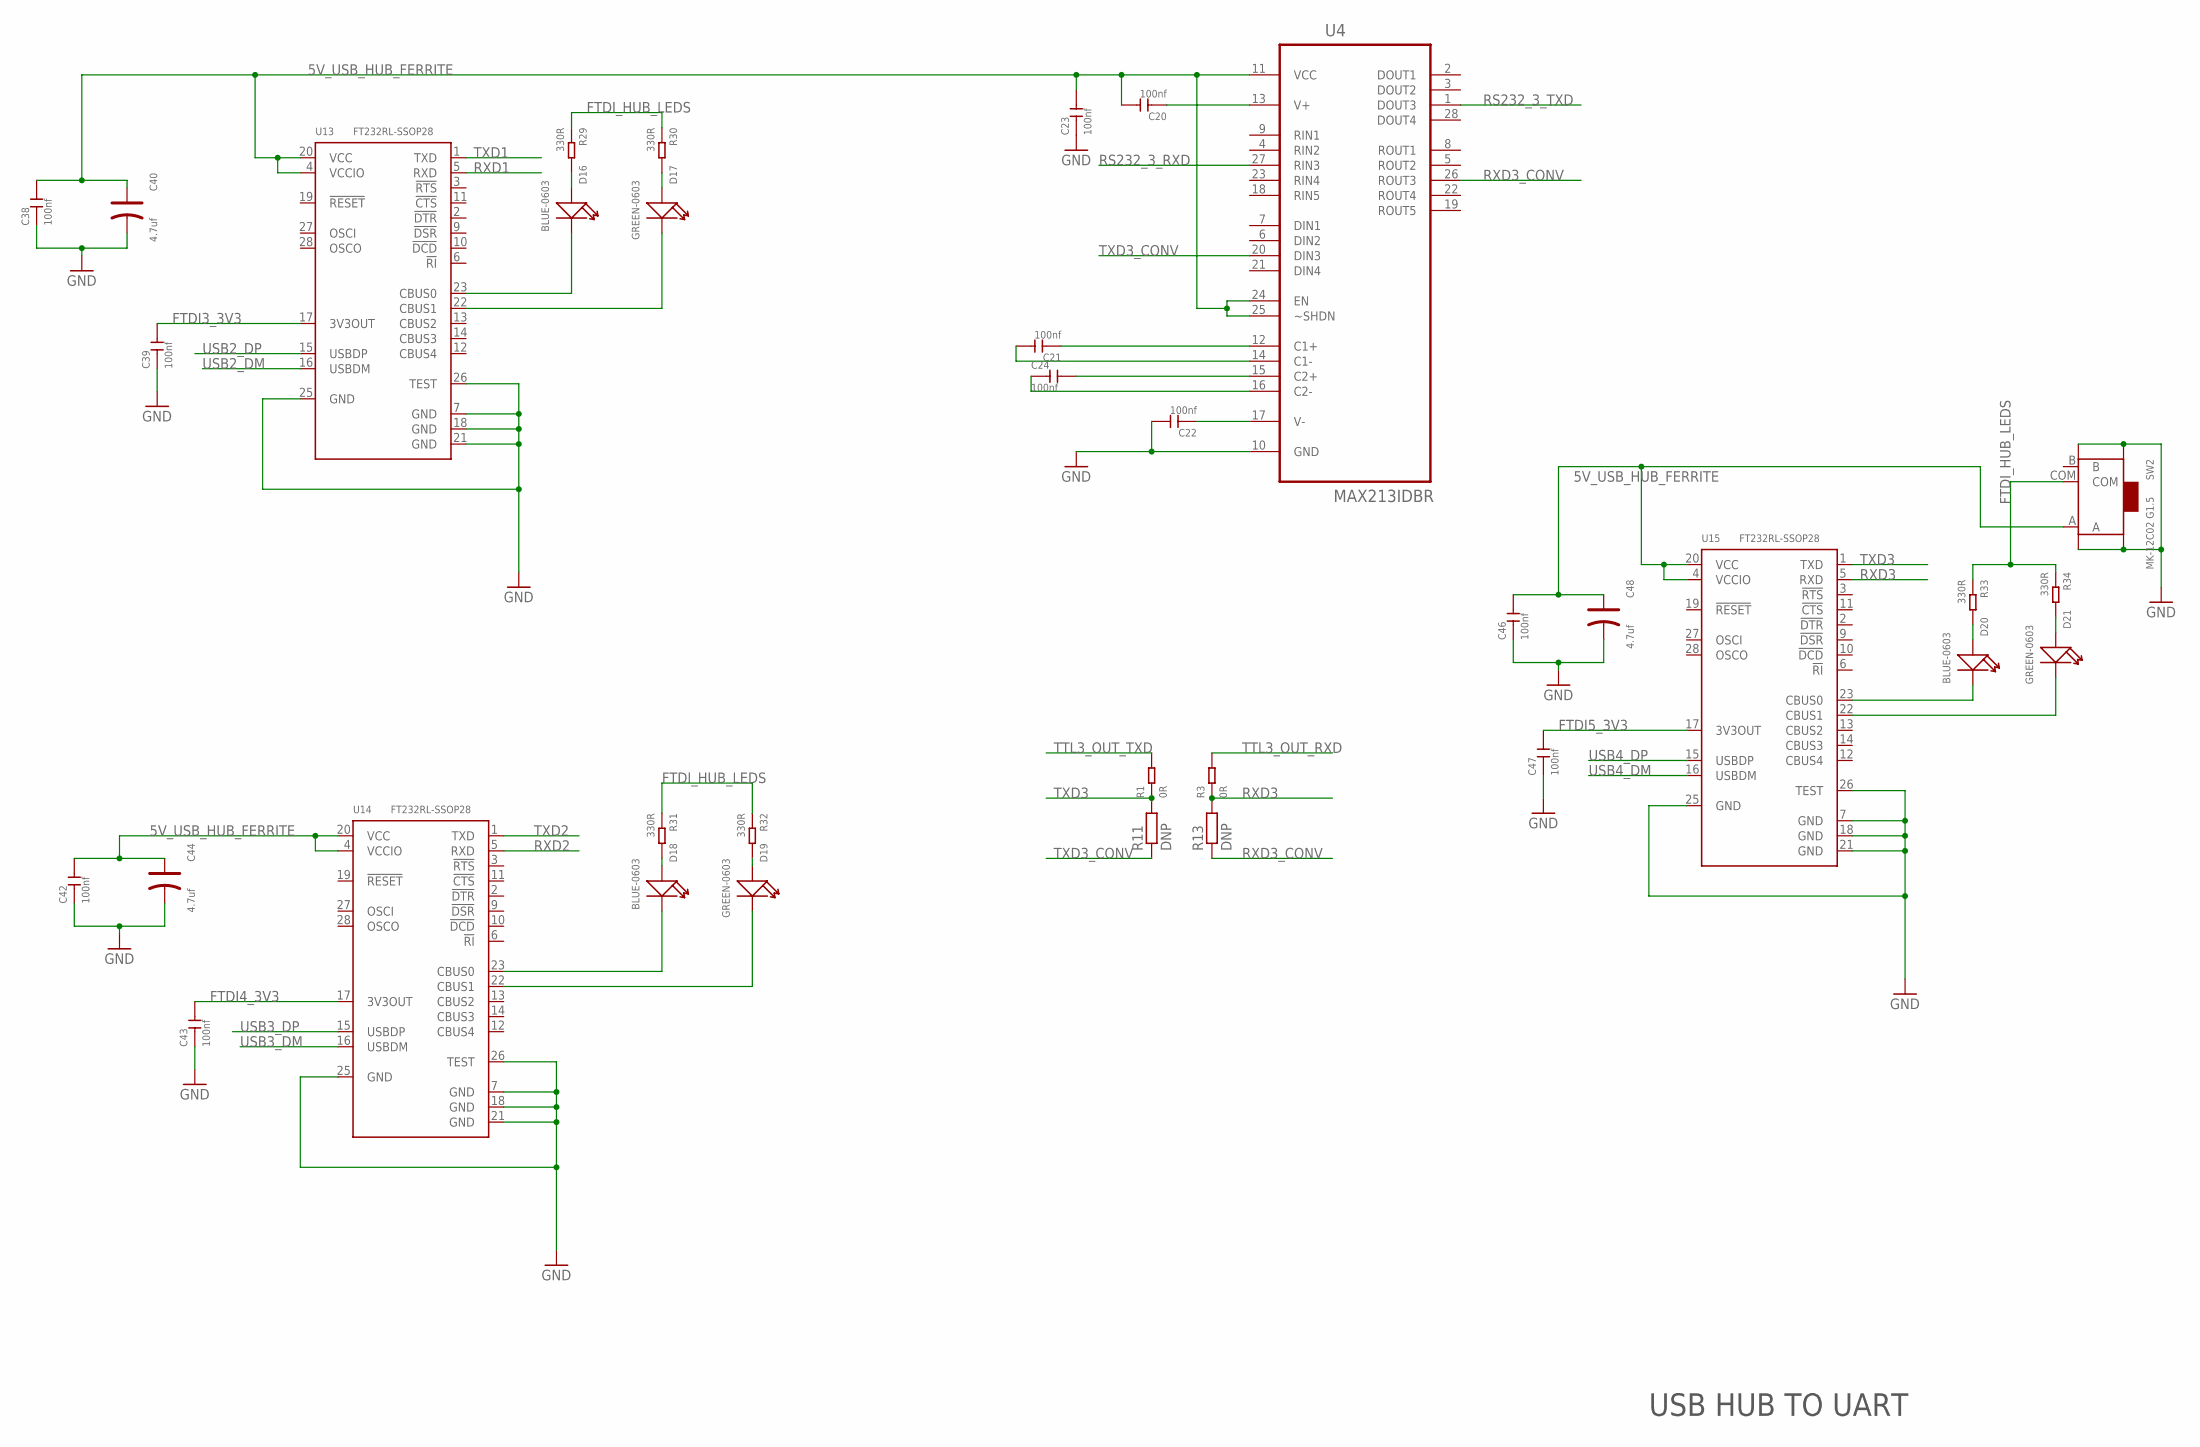
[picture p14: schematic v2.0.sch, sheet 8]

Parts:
C20, C21, C22, C23, C24, C38, C39, C42, C43, C46, C47: 100nf; C0603
C40, C44, C48: 4.7uf; AVX-A
D16, D18, D20: BLUE-0603; LED-0603
D17, D19, D21: GREEN-0603; LED-0603
R1, R3: 0R; R0603
R11, R13: DNP; R0603
R29, R30, R31, R32, R33, R34: 330R; R0603
SW2: MK-12C02 G1.5; SW7-SMD-L6.7X2.7X3.2MM
U4: MAX213IDBR; SOP65P780X200-28N
U13, U14, U15: FT232RL-SSOP28; SSOP28-0.65-10.2X5.2MM

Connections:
5V_USB_HUB_FERRITE: C20.2, C23.2, C38.2, C40.+, C42.2, C44.+, C46.2, C48.+, SW2.A, U4.11 (VCC), U4.24 (EN), U4.25 (~SHDN), U13.4 (VCCIO), U13.20 (VCC), U14.4 (VCCIO), U14.20 (VCC), U15.4 (VCCIO), U15.20 (VCC); also elsewhere on the board
FTDI3_3V3: C39.2, U13.17 (3V3OUT)
FTDI4_3V3: C43.2, U14.17 (3V3OUT)
FTDI5_3V3: C47.2, U15.17 (3V3OUT)
FTDI_HUB_LEDS: R29.1, R30.1, R31.1, R32.1, R33.1, R34.1, SW2.COM; also elsewhere on the board
GND: C22.2, C23.1, C38.1, C39.1, C40.-, C42.1, C43.1, C44.-, C46.1, C47.1, C48.-, SW2.SS1, SW2.SS2, SW2.SS3, SW2.SS4, U4.10 (GND), U13.7 (GND), U13.18 (GND), U13.21 (GND), U13.25 (GND), U13.26 (TEST), U14.7 (GND), U14.18 (GND), U14.21 (GND), U14.25 (GND), U14.26 (TEST), U15.7 (GND), U15.18 (GND), U15.21 (GND), U15.25 (GND), U15.26 (TEST); also elsewhere on the board
unnamed: C20.1, U4.13 (V+)
unnamed: C22.1, U4.17 (V-)
unnamed: C21.1, U4.12 (C1+)
unnamed: C21.2, U4.14 (C1-)
unnamed: D20.+, R33.2
unnamed: C24.2, U4.15 (C2+)
unnamed: C24.1, U4.16 (C2-)
unnamed: D21.+, R34.2
unnamed: D16.+, R29.2
unnamed: D17.+, R30.2
unnamed: D18.+, R31.2
unnamed: D19.+, R32.2
RS232_1_LED1: D16.-, U13.23 (CBUS0)
RS232_1_LED2: D17.-, U13.22 (CBUS1)
RS232_2_LED1: D18.-, U14.23 (CBUS0)
RS232_2_LED2: D19.-, U14.22 (CBUS1)
RS232_3_LED1: D20.-, U15.23 (CBUS0)
RS232_3_LED2: D21.-, U15.22 (CBUS1)
RS232_3_RXD: U4.27 (RIN3); also elsewhere on the board
RS232_3_TXD: U4.1 (DOUT3); also elsewhere on the board
RXD1: U13.5 (RXD); also elsewhere on the board
RXD2: U14.5 (RXD); also elsewhere on the board
RXD3: R3.1, R13.2, U15.5 (RXD)
RXD3_CONV: R13.1, U4.26 (ROUT3)
TTL3_OUT_RXD: R3.2; also elsewhere on the board
TTL3_OUT_TXD: R1.2; also elsewhere on the board
TXD1: U13.1 (TXD); also elsewhere on the board
TXD2: U14.1 (TXD); also elsewhere on the board
TXD3: R1.1, R11.2, U15.1 (TXD)
TXD3_CONV: R11.1, U4.20 (DIN3)
USB2_DM: U13.16 (USBDM); also elsewhere on the board
USB2_DP: U13.15 (USBDP); also elsewhere on the board
USB3_DM: U14.16 (USBDM); also elsewhere on the board
USB3_DP: U14.15 (USBDP); also elsewhere on the board
USB4_DM: U15.16 (USBDM); also elsewhere on the board
USB4_DP: U15.15 (USBDP); also elsewhere on the board

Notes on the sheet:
USB HUB TO UART

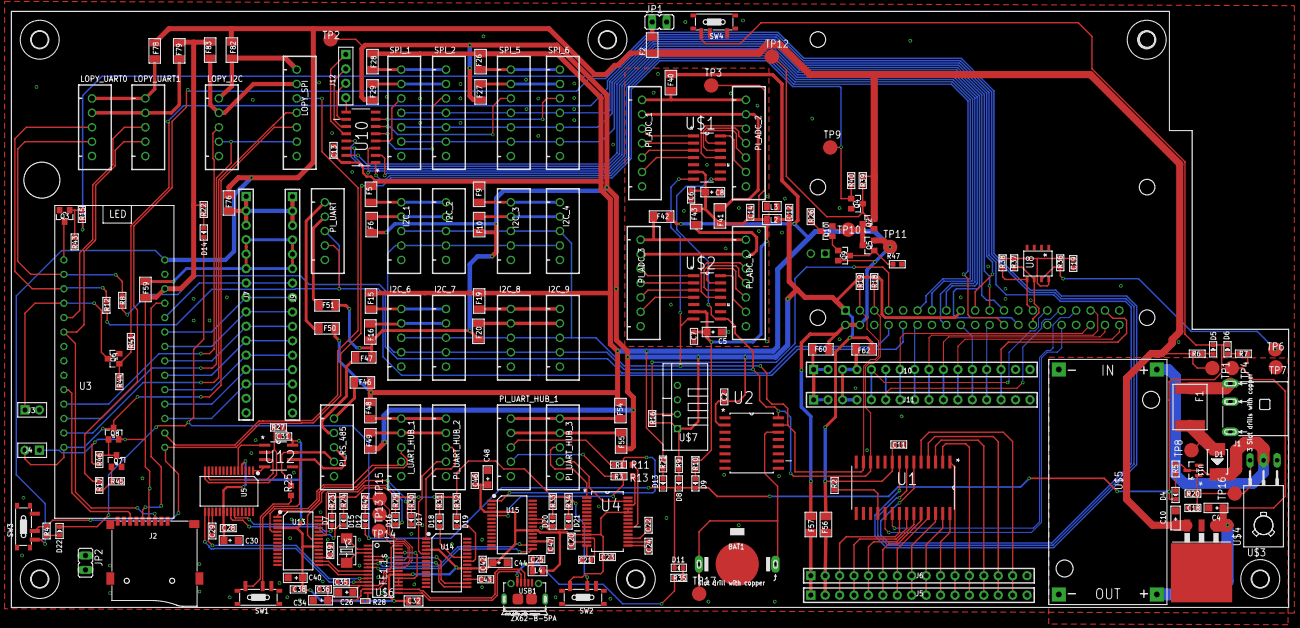
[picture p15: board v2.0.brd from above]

Board: 2 copper layers, 225.0 x 105.7 mm, 238 parts (1 on the bottom side), 227 nets.

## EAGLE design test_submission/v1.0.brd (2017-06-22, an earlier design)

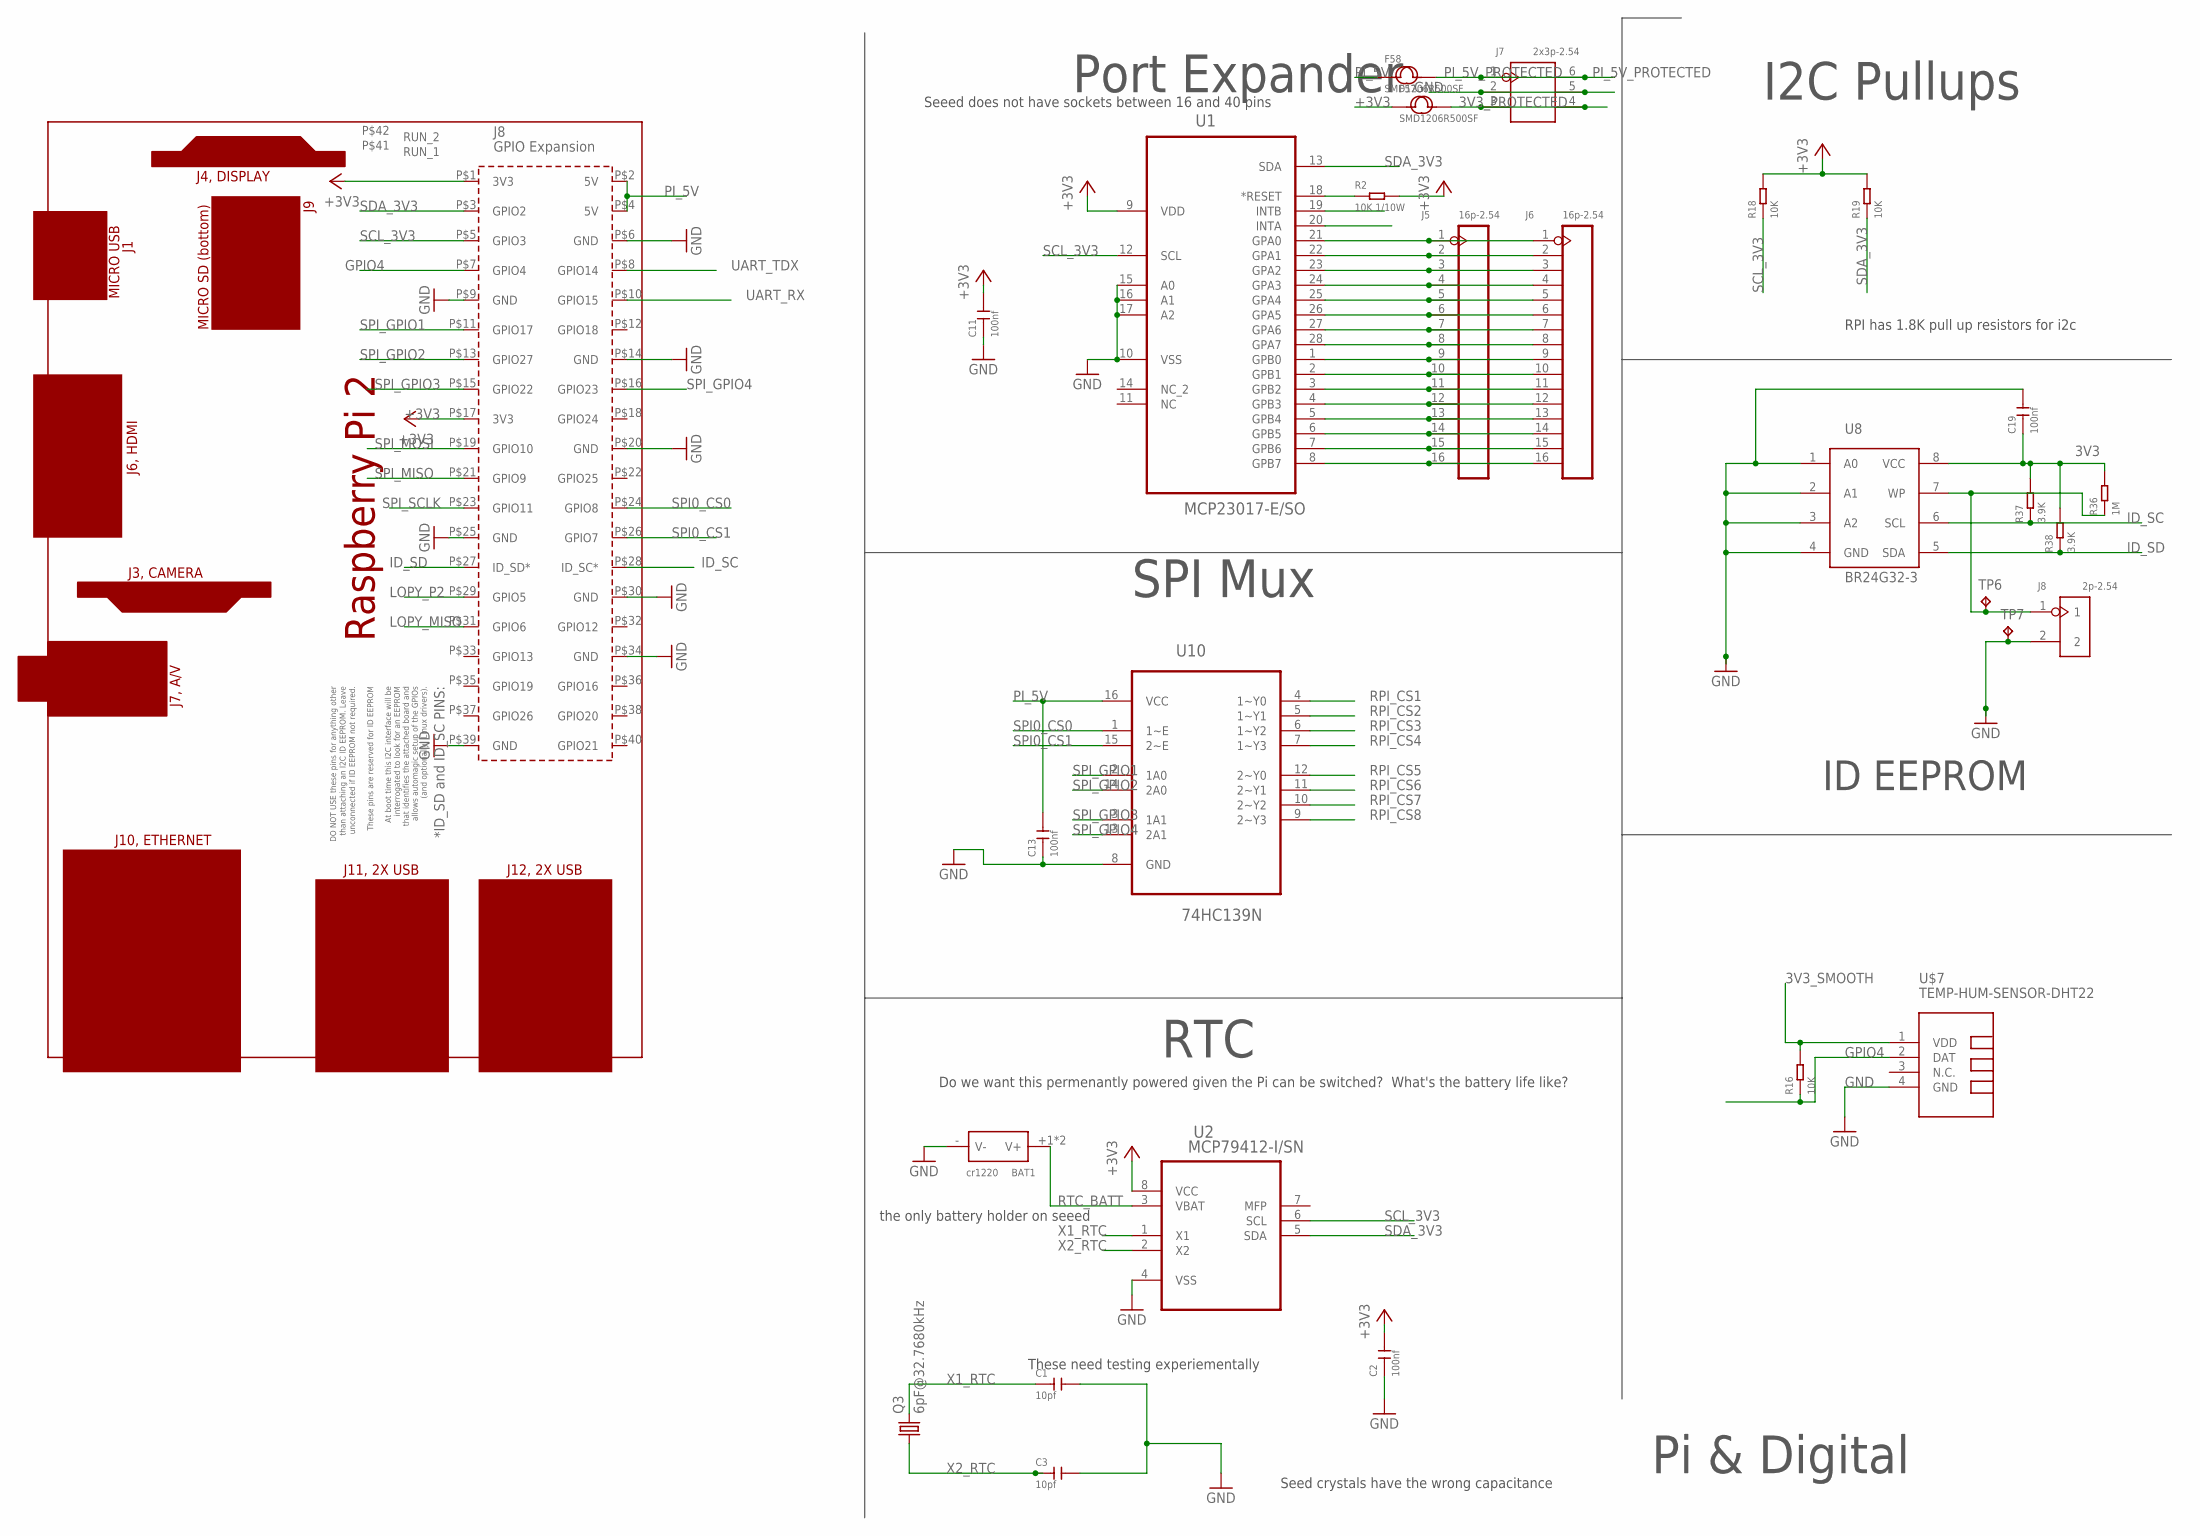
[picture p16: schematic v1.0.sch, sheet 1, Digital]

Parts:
BAT1: cr1220; BAT2P-13.5-CR1220
C1, C3: 10pf; C0603
C2, C11, C13, C19: 100nf; C0603
F57, F58: SMD1206R500SF; F1206
J5, J6: 16p-2.54; H16-2.54
J7: 2x3p-2.54; H2X3-2.54
J8: 2p-2.54; H2-2.54
PCB1: RPI2
Q3: 6pF@32.7680kHz; 86SMX
R2: 10K 1/10W; R0603
R16, R18, R19: 10K; R0603
R36: 1M; R0603
R37, R38: 3.9K; R0603
TP6, TP7: TPB2,54; B2,54
U1: MCP23017-E/SO; SOIC127P1032X265-28N
U2: MCP79412-I/SN; SOIC127P600X175-8N
U8: BR24G32-3; SOP8
U10: 74HC139N; DIP254P762X420-16
U$7: TEMP-HUM-SENSOR-DHT22

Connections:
3V3: C19.1, R36.2, R37.2, R38.2, U8.8 (VCC)
3V3_PROTECTED: F57.2, J7.3, J7.4
3V3_SMOOTH: R16.2, U$7.1 (VDD); also elsewhere on the board
+3V3: C2.2, C11.2, F57.1, PCB1.P$1 (3V3), PCB1.P$17 (3V3), R2.2, R18.2, R19.2, U1.9 (VDD), U2.8 (VCC); also elsewhere on the board
GND: BAT1.- (V-), C1.2, C2.1, C3.2, C11.1, C13.1, C19.2, J7.2, J7.5, J8.2, PCB1.P$6 (GND), PCB1.P$9 (GND), PCB1.P$14 (GND), PCB1.P$20 (GND), PCB1.P$25 (GND), PCB1.P$30 (GND), PCB1.P$34 (GND), PCB1.P$39 (GND), TP7.TP, U1.10 (VSS), U1.15 (A0), U1.16 (A1), U1.17 (A2), U2.4 (VSS), U8.1 (A0), U8.2 (A1), U8.3 (A2), U8.4 (GND), U10.8 (GND), U$7.4 (GND); also elsewhere on the board
GPIO4: PCB1.P$7 (GPIO4), R16.1, U$7.2 (DAT)
ID_SC: PCB1.P$28 (ID_SC*), R37.1, U8.6 (SCL)
ID_SD: PCB1.P$27 (ID_SD*), R38.1, U8.5 (SDA)
LOPY_MISO: PCB1.P$31 (GPIO6); also elsewhere on the board
LOPY_P2: PCB1.P$29 (GPIO5); also elsewhere on the board
unnamed: R2.1, U1.18 (*RESET)
unnamed: J5.1, J6.1, U1.21 (GPA0)
unnamed: J5.2, J6.2, U1.22 (GPA1)
unnamed: J5.3, J6.3, U1.23 (GPA2)
unnamed: J5.4, J6.4, U1.24 (GPA3)
unnamed: J5.5, J6.5, U1.25 (GPA4)
unnamed: J5.6, J6.6, U1.26 (GPA5)
unnamed: J5.7, J6.7, U1.27 (GPA6)
unnamed: J5.8, J6.8, U1.28 (GPA7)
unnamed: J5.9, J6.9, U1.1 (GPB0)
unnamed: J5.10, J6.10, U1.2 (GPB1)
unnamed: J5.11, J6.11, U1.3 (GPB2)
unnamed: J5.12, J6.12, U1.4 (GPB3)
unnamed: J5.13, J6.13, U1.5 (GPB4)
unnamed: J5.14, J6.14, U1.6 (GPB5)
unnamed: J5.15, J6.15, U1.7 (GPB6)
unnamed: J5.16, J6.16, U1.8 (GPB7)
unnamed: J8.1, R36.1, TP6.TP, U8.7 (WP)
PI_5V: C13.2, F58.1, PCB1.P$2 (5V), PCB1.P$4 (5V), U10.16 (VCC); also elsewhere on the board
PI_5V_PROTECTED: F58.2, J7.1, J7.6
RPI_CS1: U10.4 (1~Y0); also elsewhere on the board
RPI_CS2: U10.5 (1~Y1); also elsewhere on the board
RPI_CS3: U10.6 (1~Y2); also elsewhere on the board
RPI_CS4: U10.7 (1~Y3); also elsewhere on the board
RPI_CS5: U10.12 (2~Y0); also elsewhere on the board
RPI_CS6: U10.11 (2~Y1); also elsewhere on the board
RPI_CS7: U10.10 (2~Y2); also elsewhere on the board
RPI_CS8: U10.9 (2~Y3); also elsewhere on the board
RTC_BATT: BAT1.+1 (V+), BAT1.+2 (V+), U2.3 (VBAT)
SCL_3V3: PCB1.P$5 (GPIO3), R18.1, U1.12 (SCL), U2.6 (SCL); also elsewhere on the board
SDA_3V3: PCB1.P$3 (GPIO2), R19.1, U1.13 (SDA), U2.5 (SDA); also elsewhere on the board
SPI0_CS0: PCB1.P$24 (GPIO8), U10.1 (1~E)
SPI0_CS1: PCB1.P$26 (GPIO7), U10.15 (2~E)
SPI_GPIO1: PCB1.P$11 (GPIO17), U10.2 (1A0)
SPI_GPIO2: PCB1.P$13 (GPIO27), U10.14 (2A0)
SPI_GPIO3: PCB1.P$15 (GPIO22), U10.3 (1A1)
SPI_GPIO4: PCB1.P$16 (GPIO23), U10.13 (2A1)
SPI_MISO: PCB1.P$21 (GPIO9); also elsewhere on the board
SPI_MOSI: PCB1.P$19 (GPIO10); also elsewhere on the board
SPI_SCLK: PCB1.P$23 (GPIO11); also elsewhere on the board
UART_RX: PCB1.P$10 (GPIO15); also elsewhere on the board
UART_TDX: PCB1.P$8 (GPIO14); also elsewhere on the board
X1_RTC: C1.1, Q3.4 (2), U2.1 (X1)
X2_RTC: C3.1, Q3.1, U2.2 (X2)

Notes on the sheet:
Pi & Digital
Port Expander
SPI Mux
RTC
I2C Pullups
Do we want this permenantly powered given the Pi can be switched? What's the battery life like?
Seed crystals have the wrong capacitance
These need testing experiementally
Seeed does not have sockets between 16 and 40 pins
RPI has 1.8K pull up resistors for i2c
the only battery holder on seeed
ID EEPROM

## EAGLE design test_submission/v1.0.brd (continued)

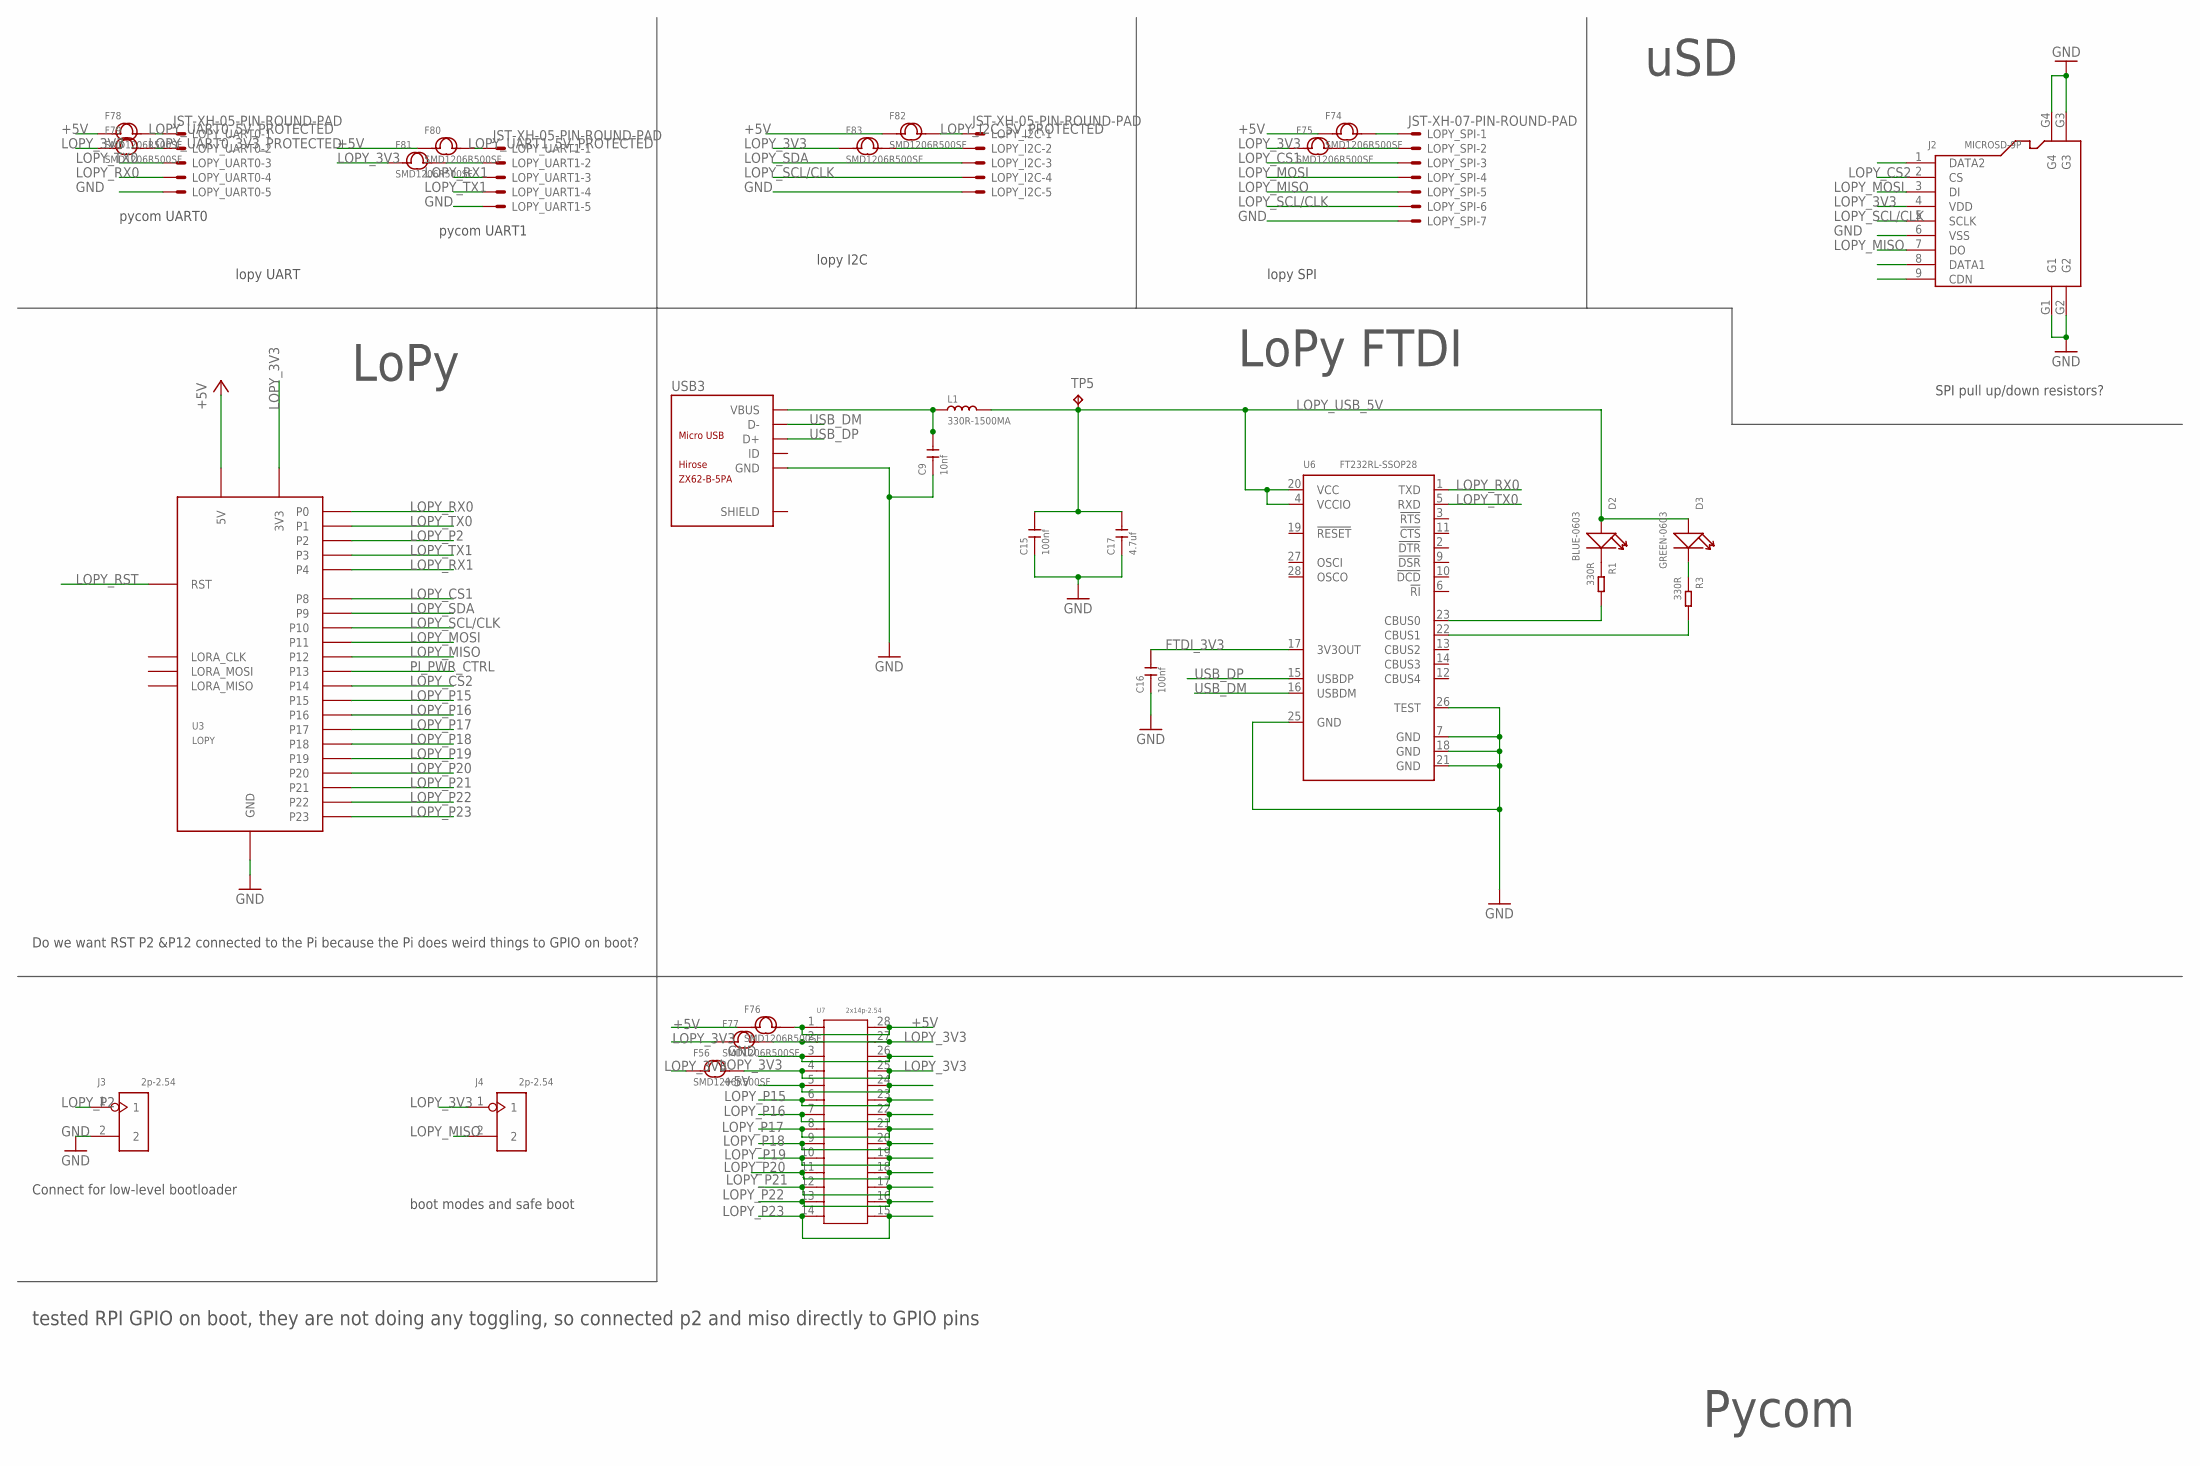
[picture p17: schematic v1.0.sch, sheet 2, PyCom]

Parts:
C9: 10nf; C0805
C15, C16: 100nf; C0603
C17: 4.7uf; C0603
D2: BLUE-0603; LED-0603
D3: GREEN-0603; LED-0603
F56, F74, F75, F76, F77, F78, F79, F80, F81, F82, F83: SMD1206R500SF; F1206
J2: MICROSD-9P; MICRO-SD9+4P-SMD-16.1X14.5X1.85MM
J3, J4: 2p-2.54; H2-2.54
L1: 330R-1500MA; L0805
LOPY_I2C: JST-XH-05-PIN-ROUND-PAD; JST-XH-05-PACKAGE-ROUND-PAD
LOPY_SPI: JST-XH-07-PIN-ROUND-PAD; JST-XH-07-PACKAGE-ROUND-PAD
LOPY_UART0, LOPY_UART1: JST-XH-05-PIN-ROUND-PAD; JST-XH-05-PACKAGE-ROUND-PAD
R1, R3: 330R; R0603
TP5: TPB2,54; B2,54
U3: LOPY
U6: FT232RL-SSOP28; SSOP28-0.65-10.2X5.2MM
U7: 2x14p-2.54; SCK28-2.54-35.6X10MM
USB3: ZX62-B-5PA; MICRO-USB5+6P-SMD-0.65-AB

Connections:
+5V: F74.1, F76.1, F76.2, F78.1, F80.1, F82.1, U3.P$28 (5V), U7.1, U7.5, U7.24, U7.28; also elsewhere on the board
FTDI_3V3: C16.2, U6.17 (3V3OUT); also elsewhere on the board
GND: C9.1, C15.1, C16.1, C17.1, J2.6 (VSS), J2.G1, J2.G2, J2.G3, J2.G4, J3.2, LOPY_I2C.5, LOPY_SPI.7, LOPY_UART0.5, LOPY_UART1.5, U3.P$27 (GND), U6.7 (GND), U6.18 (GND), U6.21 (GND), U6.25 (GND), U6.26 (TEST), U7.3, U7.26, USB3.5 (GND); also elsewhere on the board
LOPY_3V3: F56.1, F56.2, F75.1, F77.1, F77.2, F79.1, F81.1, F83.1, J2.4 (VDD), J4.1, U3.P$26 (3V3), U7.2, U7.4, U7.25, U7.27; also elsewhere on the board
LOPY_CS1: LOPY_SPI.3, U3.P$10 (P8)
LOPY_CS2: J2.2 (CS), U3.P$16 (P14)
LOPY_I2C_3V3_PROTECTED: F83.2, LOPY_I2C.2
LOPY_I2C_5V_PROTECTED: F82.2, LOPY_I2C.1
LOPY_MISO: J2.7 (DO), J4.2, LOPY_SPI.5, U3.P$14 (P12); also elsewhere on the board
LOPY_MOSI: J2.3 (DI), LOPY_SPI.4, U3.P$13 (P11)
LOPY_P2: J3.1, U3.P$4 (P2); also elsewhere on the board
LOPY_P15: U3.P$17 (P15), U7.6, U7.23
LOPY_P16: U3.P$18 (P16), U7.7, U7.22
LOPY_P17: U3.P$19 (P17), U7.8, U7.21
LOPY_P18: U3.P$20 (P18), U7.9, U7.20
LOPY_P19: U3.P$21 (P19), U7.10, U7.19
LOPY_P20: U3.P$22 (P20), U7.11, U7.18
LOPY_P21: U3.P$23 (P21), U7.12, U7.17
LOPY_P22: U3.P$24 (P22), U7.13, U7.16
LOPY_P23: U3.P$25 (P23), U7.14, U7.15
LOPY_RST: U3.P$1 (RST)
LOPY_RX0: LOPY_UART0.4, U3.P$2 (P0), U6.1 (TXD)
LOPY_RX1: LOPY_UART1.3, U3.P$6 (P4)
LOPY_SCL/CLK: J2.5 (SCLK), LOPY_I2C.4, LOPY_SPI.6, U3.P$12 (P10)
LOPY_SDA: LOPY_I2C.3, U3.P$11 (P9)
LOPY_SPI_3V3_PROTECTED: F75.2, LOPY_SPI.2
LOPY_SPI_5V_PROTECTED: F74.2, LOPY_SPI.1
LOPY_TX0: LOPY_UART0.3, U3.P$3 (P1), U6.5 (RXD)
LOPY_TX1: LOPY_UART1.4, U3.P$5 (P3)
LOPY_UART0_3V3_PROTECTED: F79.2, LOPY_UART0.2
LOPY_UART0_5V_PROTECTED: F78.2, LOPY_UART0.1
LOPY_UART1_3V3_PROTECTED: F81.2, LOPY_UART1.2
LOPY_UART1_5V_PROTECTED: F80.2, LOPY_UART1.1
LOPY_USB_5V: C15.2, C17.2, D2.+, D3.+, L1.2, TP5.TP, U6.4 (VCCIO), U6.20 (VCC); also elsewhere on the board
unnamed: D2.-, R1.1
unnamed: D3.-, R3.1
unnamed: R1.2, U6.23 (CBUS0)
unnamed: R3.2, U6.22 (CBUS1)
PI_PWR_CTRL: U3.P$15 (P13); also elsewhere on the board
USB_DM: U6.16 (USBDM), USB3.2 (D-)
USB_DP: U6.15 (USBDP), USB3.3 (D+)
VBUS: C9.2, L1.1, USB3.1 (VBUS)

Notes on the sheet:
Pycom
pycom UART1
pycom UART0
lopy I2C
lopy SPI
lopy UART
Do we want RST P2 &P12 connected to the Pi because the Pi does weird things to GPIO on boot?
SPI pull up/down resistors?
LoPy
uSD
LoPy FTDI
Connect for low-level bootloader
boot modes and safe boot
tested RPI GPIO on boot, they are not doing any toggling, so connected p2 and miso directly to GPIO pins

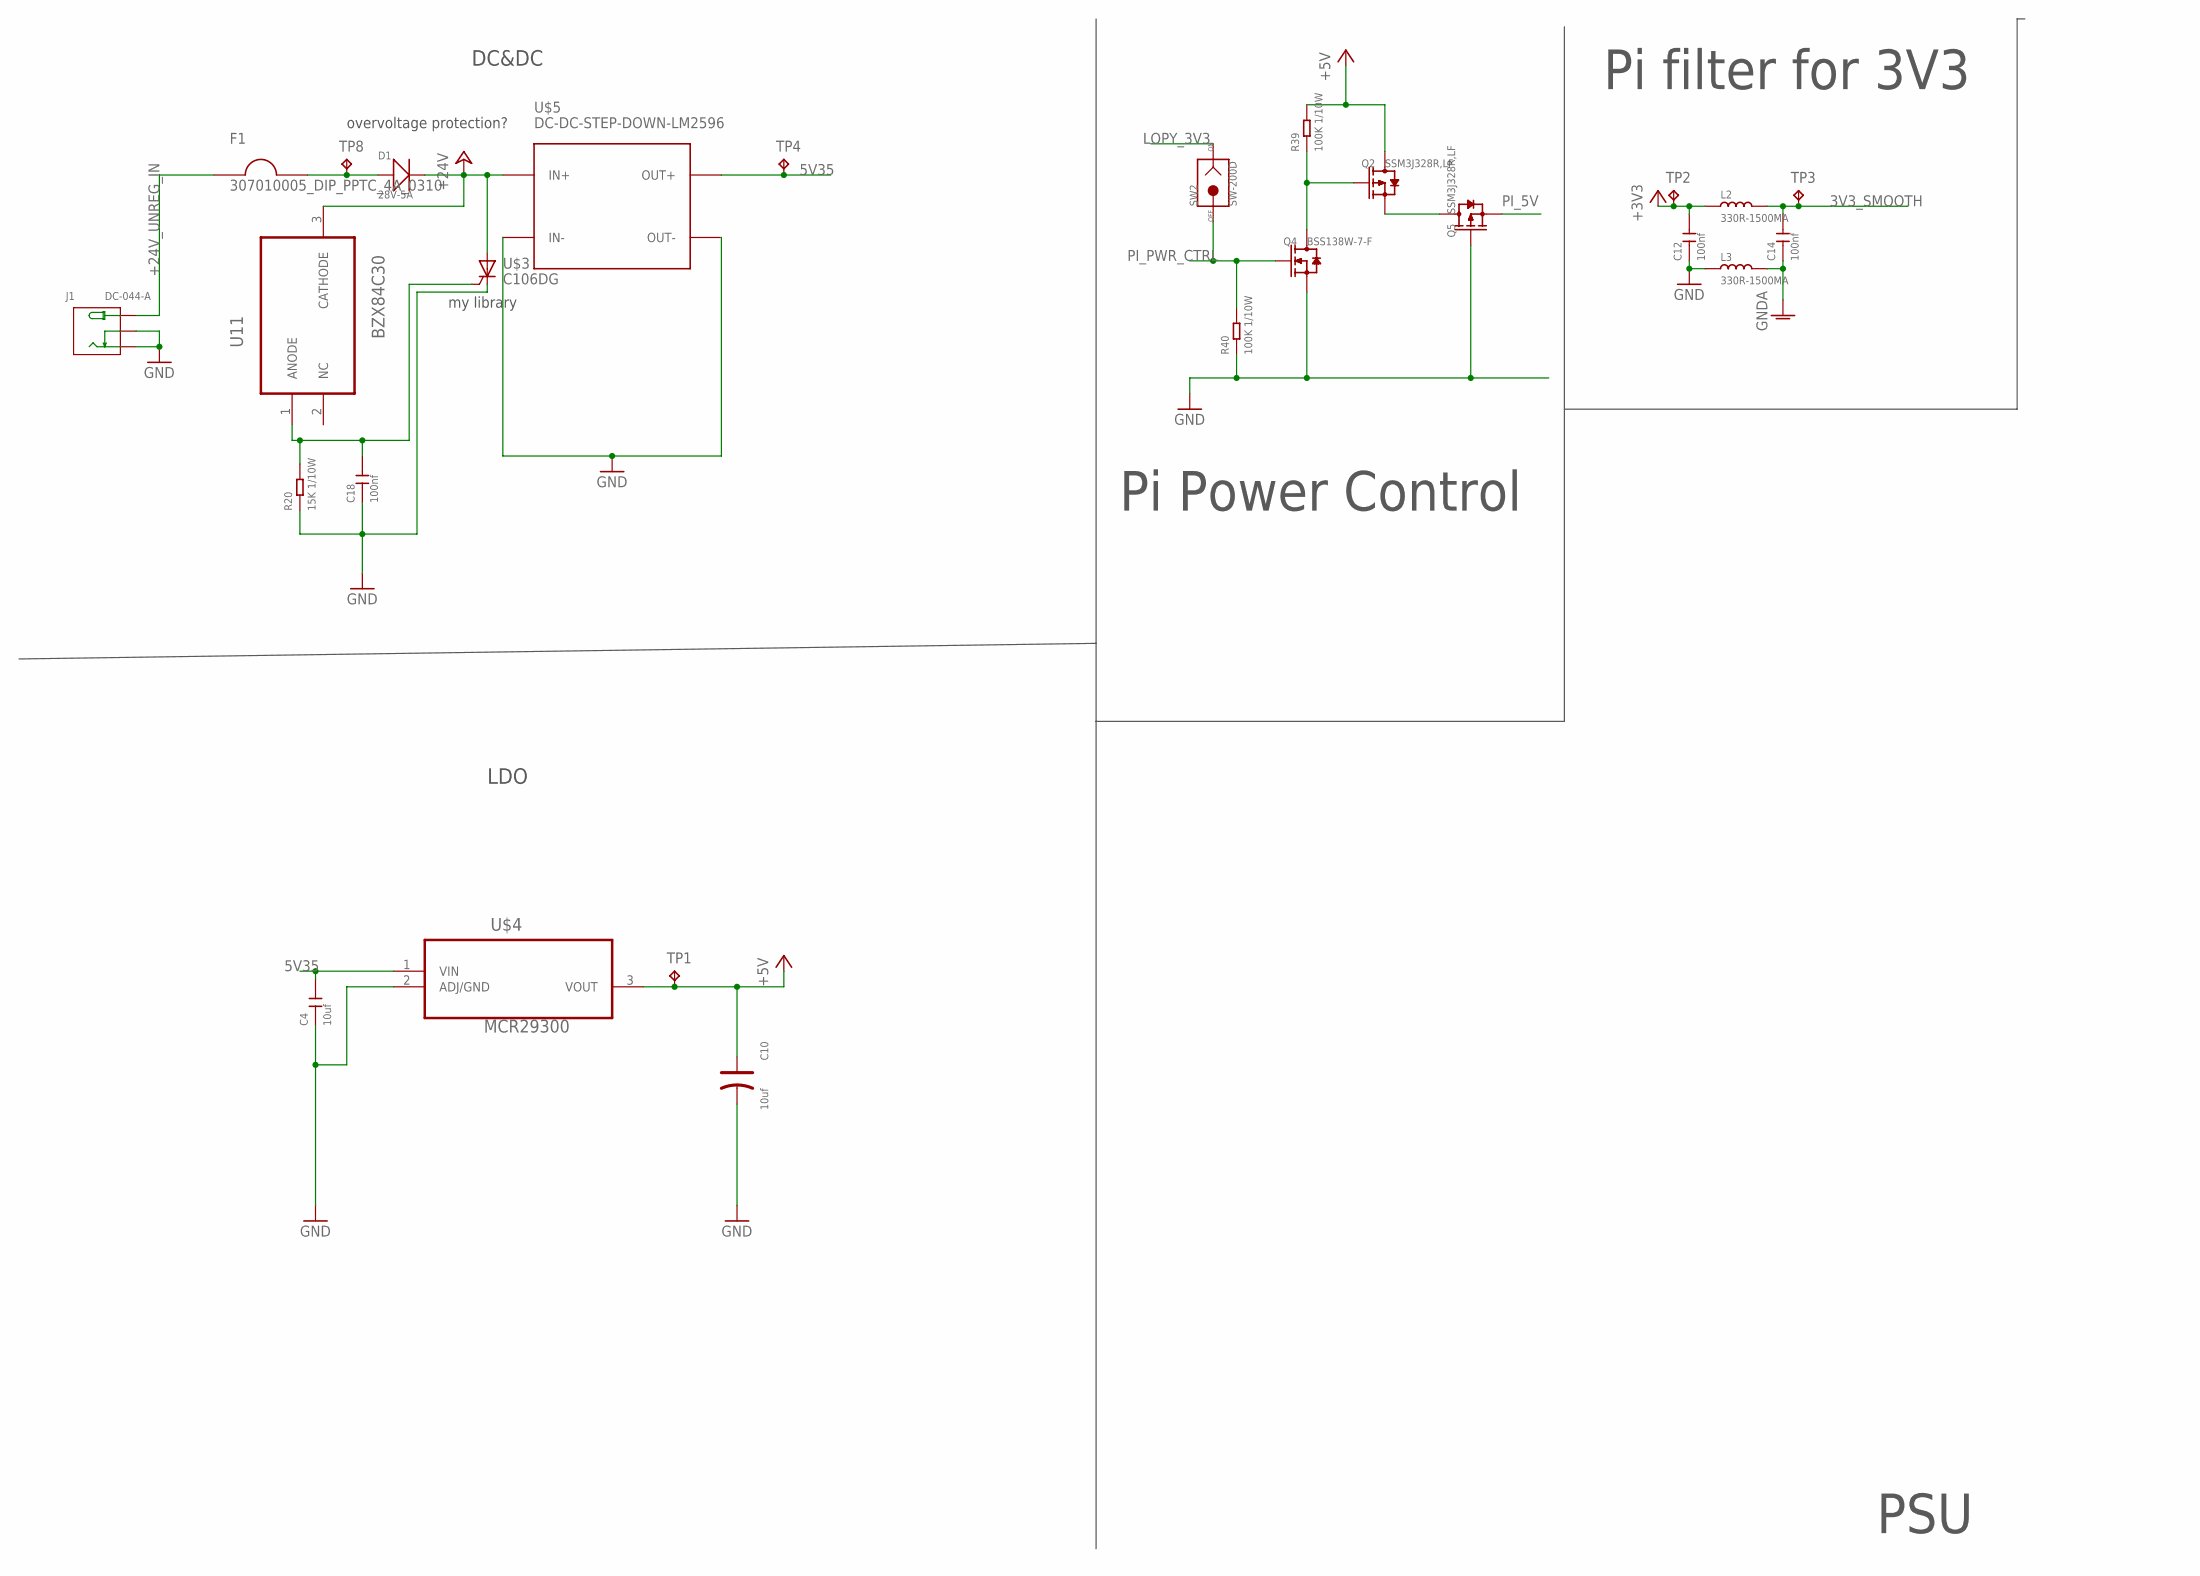
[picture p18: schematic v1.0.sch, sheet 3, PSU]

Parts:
C4: 10uf; C0603
C10: 10uf; AVX-A
C12, C14, C18: 100nf; C0603
D1: 28V-5A; DO-214AA
F1: 307010005_DIP_PPTC_4A_0310; TH_5MM_14MM
J1: DC-044-A; DCJ3P-11.6X9.6X7.0MM
L2, L3: 330R-1500MA; L0805
Q2, Q5: SSM3J328R,LF; SOT-23
Q4: BSS138W-7-F; SOT-23
R20: 15K 1/10W; R0603
R39, R40: 100K 1/10W; R0603
SW2: SW-200D; SW2-12.7-12.0X3.6X3.6MM
TP1, TP2, TP3, TP4, TP8: TPB2,54; B2,54
U11: BZX84C30; SOT91P240X110-3N
U$3: C106DG; TO-225AA
U$4: MCR29300; TO-263
U$5: DC-DC-STEP-DOWN-LM2596

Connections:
3V3_SMOOTH: C14.2, L2.2, TP3.TP; also elsewhere on the board
5V35: C4.2, TP4.TP, U$4.1 (VIN), U$5.OUT+; also elsewhere on the board
+3V3: C12.2, L2.1, TP2.TP; also elsewhere on the board
+5V: C10.+, Q2.3 (D), R39.2, TP1.TP, U$4.3 (VOUT); also elsewhere on the board
+24V: D1.-, U11.3 (CATHODE), U$3.1 (A), U$5.IN+; also elsewhere on the board
+24V_UNREG_IN: F1.P$1, J1.+
GND: C4.1, C10.-, C12.1, C18.1, J1.-, J1.CDN, L3.1, Q4.2 (S), Q5.1 (G), R20.1, R40.1, U$3.2 (C), U$4.2 (ADJ/GND), U$5.IN-, U$5.OUT-; also elsewhere on the board
GNDA: C14.1, L3.2; also elsewhere on the board
LOPY_3V3: SW2.1; also elsewhere on the board
unnamed: D1.+, F1.P$2, TP8.TP
unnamed: C18.2, R20.2, U11.1 (ANODE), U$3.3 (G1)
unnamed: Q2.2 (S), Q5.3 (D)
unnamed: Q2.1 (G), Q4.3 (D), R39.1
PI_5V: Q5.2 (S); also elsewhere on the board
PI_PWR_CTRL: Q4.1 (G), R40.2, SW2.2; also elsewhere on the board

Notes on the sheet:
PSU
LDO
DC&DC
Pi filter for 3V3
overvoltage protection?
Pi Power Control
my library


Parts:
C5, C8: 1UF 6.3V; C0402
C6, C7: 100nf; C0603
U$1, U$2: MCP3424-E/SL; SOIC127P600X175-14N

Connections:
+3V3_SMOOTH: C5.1, C6.2, C7.2, C8.1, U$1.6 (VDD), U$2.6 (VDD)
ADC1+: U$1.1 (CH1+); also elsewhere on the board
ADC1-: U$1.2 (CH1-); also elsewhere on the board
ADC2+: U$1.3 (CH2+); also elsewhere on the board
ADC2-: U$1.4 (CH2-); also elsewhere on the board
ADC3+: U$1.11 (CH3+); also elsewhere on the board
ADC3-: U$1.12 (CH3-); also elsewhere on the board
ADC4+: U$1.13 (CH4+); also elsewhere on the board
ADC4-: U$1.14 (CH4-); also elsewhere on the board
ADC5+: U$2.1 (CH1+); also elsewhere on the board
ADC5-: U$2.2 (CH1-); also elsewhere on the board
ADC6+: U$2.3 (CH2+); also elsewhere on the board
ADC6-: U$2.4 (CH2-); also elsewhere on the board
ADC7+: U$2.11 (CH3+); also elsewhere on the board
ADC7-: U$2.12 (CH3-); also elsewhere on the board
ADC8+: U$2.13 (CH4+); also elsewhere on the board
ADC8-: U$2.14 (CH4-); also elsewhere on the board
GNDA: C5.2, C6.1, C7.1, C8.2, U$1.5 (VSS), U$1.9 (ADR0), U$1.10 (ADR1), U$2.5 (VSS), U$2.9 (ADR0); also elsewhere on the board
SCL_3V3: U$1.8 (SCL), U$2.8 (SCL); also elsewhere on the board
SDA_3V3: U$1.7 (SDA), U$2.7 (SDA); also elsewhere on the board

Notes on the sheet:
ADC
1101000
1101001


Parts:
D4, D5, D6, D8, D9, D10, D13, D14: RED-0603; LED-0603
D11: BLUE-0603; LED-0603
R5, R11, R35: 1K; R0603
R6, R21: 220R; R0603
R7: 330R; R0603
R9, R10, R22: 100R; R0603
SW1, SW3, SW4: SW-200D; SW2-12.7-12.0X3.6X3.6MM

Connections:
3V3_SMOOTH: R10.2; also elsewhere on the board
5V35: R7.2; also elsewhere on the board
5V_USB_HUB: R35.2; also elsewhere on the board
+3V3: R9.2; also elsewhere on the board
+5V: R6.2; also elsewhere on the board
+24V: R5.2; also elsewhere on the board
GND: SW1.2, SW3.2, SW4.2; also elsewhere on the board
LOPY_3V3: R22.2; also elsewhere on the board
LOPY_USB_5V: R11.2; also elsewhere on the board
unnamed: D9.+, R10.1
unnamed: D8.+, R9.1
unnamed: D6.+, R7.1
unnamed: D5.+, R6.1
unnamed: D4.+, R5.1
unnamed: D11.+, R35.1
unnamed: D10.+, R11.1
unnamed: D4.-, D5.-, D6.-, SW1.1
unnamed: D14.+, R22.1
unnamed: D10.-, D11.-, D14.-, SW4.1
unnamed: D8.-, D9.-, D13.-, SW3.1
unnamed: D13.+, R21.1
PI_5V: R21.2; also elsewhere on the board

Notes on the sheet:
LEDs


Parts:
F2, F3, F4, F5, F6, F7, F8, F9, F10, F11, F12, F13, F14, F15, F16, F17, F18, F19, F20, F21, F22, F23, F24, F25, F26, F27, F28, F29, F30, F31, F32, F33, F34, F35, F36, F37, F38, F39, F40, F41, F42, F43, F44, F45, F46, F47, F48, F49, F50, F51, F52, F53, F54, F55: SMD1206R500SF; F1206
I2C_1, I2C_2, I2C_3, I2C_4, I2C_5, I2C_6, I2C_7, I2C_8, I2C_9, I2C_10: JST-XH-05-PIN-ROUND-PAD; JST-XH-05-PACKAGE-ROUND-PAD
I_UART_HUB_1: JST-XH-05-PIN-ROUND-PAD; JST-XH-05-PACKAGE-ROUND-PAD
PI_ADC_1, PI_ADC_2, PI_ADC_3, PI_ADC_4: JST-XH-07-PIN-ROUND-PAD; JST-XH-07-PACKAGE-ROUND-PAD
PI_RS_485: JST-XH-05-PIN-ROUND-PAD; JST-XH-05-PACKAGE-ROUND-PAD
PI_UART: JST-XH-05-PIN-ROUND-PAD; JST-XH-05-PACKAGE-ROUND-PAD
PI_UART_HUB_2, PI_UART_HUB_3: JST-XH-05-PIN-ROUND-PAD; JST-XH-05-PACKAGE-ROUND-PAD
SPI_1, SPI_2, SPI_3, SPI_4, SPI_5, SPI_6, SPI_7, SPI_8: JST-XH-07-PIN-ROUND-PAD; JST-XH-07-PACKAGE-ROUND-PAD

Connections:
3V3_SMOOTH: F3.1, F6.1, F8.1, F10.1, F12.1, F14.1, F16.1, F18.1, F20.1, F22.1, F23.1, F25.1, F27.1, F29.1, F31.1, F33.1, F35.1, F37.1, F39.1, F41.1, F43.1, F45.1, F47.1, F49.1, F51.1, F53.1, F55.1; also elsewhere on the board
ADC1+: PI_ADC_1.3; also elsewhere on the board
ADC1-: PI_ADC_1.4; also elsewhere on the board
ADC2+: PI_ADC_1.5; also elsewhere on the board
ADC2-: PI_ADC_1.6; also elsewhere on the board
ADC3+: PI_ADC_2.3; also elsewhere on the board
ADC3-: PI_ADC_2.4; also elsewhere on the board
ADC4+: PI_ADC_2.5; also elsewhere on the board
ADC4-: PI_ADC_2.6; also elsewhere on the board
ADC5+: PI_ADC_3.3; also elsewhere on the board
ADC5-: PI_ADC_3.4; also elsewhere on the board
ADC6+: PI_ADC_3.5; also elsewhere on the board
ADC6-: PI_ADC_3.6; also elsewhere on the board
ADC7+: PI_ADC_4.3; also elsewhere on the board
ADC7-: PI_ADC_4.4; also elsewhere on the board
ADC8+: PI_ADC_4.5; also elsewhere on the board
ADC8-: PI_ADC_4.6; also elsewhere on the board
ADC_1_3V3_P: F41.2, PI_ADC_1.2
ADC_1_5V_P: F40.2, PI_ADC_1.1
ADC_2_3V3_P: F39.2, PI_ADC_2.2
ADC_2_5V_P: F38.2, PI_ADC_2.1
ADC_3_3V3_P: F43.2, PI_ADC_3.2
ADC_3_5V_P: F42.2, PI_ADC_3.1
ADC_4_3V3_P: F45.2, PI_ADC_4.2
ADC_4_5V_P: F44.2, PI_ADC_4.1
GND: I2C_1.5, I2C_2.5, I2C_3.5, I2C_4.5, I2C_5.5, I2C_6.5, I2C_7.5, I2C_8.5, I2C_9.5, I2C_10.5, I_UART_HUB_1.5, PI_ADC_1.7, PI_ADC_2.7, PI_ADC_3.7, PI_ADC_4.7, PI_RS_485.5, PI_UART.5, PI_UART_HUB_2.5, PI_UART_HUB_3.5, SPI_1.7, SPI_2.7, SPI_3.7, SPI_4.7, SPI_5.7, SPI_6.7, SPI_7.7, SPI_8.7; also elsewhere on the board
PI_5V: F2.1, F4.1, F5.1, F7.1, F9.1, F11.1, F13.1, F15.1, F17.1, F19.1, F21.1, F24.1, F26.1, F28.1, F30.1, F32.1, F34.1, F36.1, F38.1, F40.1, F42.1, F44.1, F46.1, F48.1, F50.1, F52.1, F54.1; also elsewhere on the board
PI_5V_SPI_1_P: F28.2, SPI_1.1
PI_I2C_2_5V_P: F9.2, I2C_3.1
PI_I2C_3V3_2_P: F10.2, I2C_3.2
PI_I2C_3V3_3: F6.2, I2C_1.2
PI_I2C_3V3_3_P: F8.2, I2C_2.2
PI_I2C_3V3_4_P: F12.2, I2C_4.2
PI_I2C_3V3_5_P: F14.2, I2C_6.2
PI_I2C_3V3_6_P: F22.2, I2C_5.2
PI_I2C_3V3_7_P: F16.2, I2C_7.2
PI_I2C_3V3_8_P: F18.2, I2C_8.2
PI_I2C_3V3_9_P: F20.2, I2C_9.2
PI_I2C_3V3_10_P: F37.2, I2C_10.2
PI_I2C_5V_3_P: F7.2, I2C_2.1
PI_I2C_5V_4_P: F11.2, I2C_4.1
PI_I2C_5V_5_P: F13.2, I2C_6.1
PI_I2C_5V_6_P: F21.2, I2C_5.1
PI_I2C_5V_7_P: F15.2, I2C_7.1
PI_I2C_5V_8_P: F17.2, I2C_8.1
PI_I2C_5V_9_P: F19.2, I2C_9.1
PI_I2C_5V_10_P: F36.2, I2C_10.1
PI_I2C_5V_P: F5.2, I2C_1.1
PI_RS485_3V3_P: F47.2, PI_RS_485.2
PI_RS485_5V_P: F46.2, PI_RS_485.1
PI_SPI_3V3_1_P: F29.2, SPI_1.2
PI_SPI_5V_2_P: F2.2, SPI_2.1
PI_UART_3V3_P: F51.2, PI_UART.2
PI_UART_5V_P: F50.2, PI_UART.1
PI_UART_HUB_1_3V3_P: F49.2, I_UART_HUB_1.2
PI_UART_HUB_1_5V_P: F48.2, I_UART_HUB_1.1
PI_UART_HUB_2_3V3_P: F53.2, PI_UART_HUB_2.2
PI_UART_HUB_2_5V_P: F52.2, PI_UART_HUB_2.1
RPI_CS1: SPI_1.3; also elsewhere on the board
RPI_CS2: SPI_2.3; also elsewhere on the board
RPI_CS3: SPI_3.3; also elsewhere on the board
RPI_CS4: SPI_4.3; also elsewhere on the board
RPI_CS5: SPI_5.3; also elsewhere on the board
RPI_CS6: SPI_6.3; also elsewhere on the board
RPI_CS7: SPI_7.3; also elsewhere on the board
RPI_CS8: SPI_8.3; also elsewhere on the board
RS485_A: PI_RS_485.3; also elsewhere on the board
RS485_B: PI_RS_485.4; also elsewhere on the board
SCL_3V3: I2C_1.4, I2C_2.4, I2C_3.4, I2C_4.4, I2C_5.4, I2C_6.4, I2C_7.4, I2C_8.4, I2C_9.4, I2C_10.4; also elsewhere on the board
SDA_3V3: I2C_1.3, I2C_2.3, I2C_3.3, I2C_4.3, I2C_5.3, I2C_6.3, I2C_7.3, I2C_8.3, I2C_9.3, I2C_10.3; also elsewhere on the board
SPI_3V3_2_P: F3.2, SPI_2.2
SPI_3V3_3_P: F23.2, SPI_3.2
SPI_3V3_4_P: F25.2, SPI_4.2
SPI_3V3_5_P: F27.2, SPI_5.2
SPI_3V3_6_P: F31.2, SPI_6.2
SPI_3V3_7_P: F33.2, SPI_7.2
SPI_3V3_8_P: F35.2, SPI_8.2
SPI_5V_3_P: F4.2, SPI_3.1
SPI_5V_4_P: F24.2, SPI_4.1
SPI_5V_5_P: F26.2, SPI_5.1
SPI_5V_6_P: F30.2, SPI_6.1
SPI_5V_7_P: F32.2, SPI_7.1
SPI_5V_8_P: F34.2, SPI_8.1
SPI_MISO: SPI_1.5, SPI_2.5, SPI_3.5, SPI_4.5, SPI_5.5, SPI_6.5, SPI_7.5, SPI_8.5; also elsewhere on the board
SPI_MOSI: SPI_1.4, SPI_2.4, SPI_3.4, SPI_4.4, SPI_5.4, SPI_6.4, SPI_7.4, SPI_8.4; also elsewhere on the board
SPI_SCLK: SPI_1.6, SPI_2.6, SPI_3.6, SPI_4.6, SPI_5.6, SPI_6.6, SPI_7.6, SPI_8.6; also elsewhere on the board
UART1_RDX: I_UART_HUB_1.4; also elsewhere on the board
UART1_TDX: I_UART_HUB_1.3; also elsewhere on the board
UART2_RDX: PI_UART_HUB_2.4; also elsewhere on the board
UART2_TDX: PI_UART_HUB_2.3; also elsewhere on the board
UART3_RDX: PI_UART_HUB_3.4; also elsewhere on the board
UART3_TDX: PI_UART_HUB_3.3; also elsewhere on the board
UART_HUB_3_3V3_P: F55.2, PI_UART_HUB_3.2
UART_RX: PI_UART.4; also elsewhere on the board
UART_TDX: PI_UART.3; also elsewhere on the board
UART_USB_HUB_3_5V: F54.2, PI_UART_HUB_3.1

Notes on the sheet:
Raspberry Pi connector sockets
I2C can support up to 1008 slave devices
ADC Sockets
RS485 Rpi
RPI UART
RPI HUB UART

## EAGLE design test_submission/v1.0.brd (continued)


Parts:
C28, C29, C35, C36: 100nf; C0603
C30: 4.7uf; C0603
C31: 100nf; C0805
C32, C33, C34: 10uf; C0805
D7: BLUE-0603; LED-0603
D15: GREEN-0603; LED-0603
R23, R24: 330R; R0603
R25: 4.7K; R0603
R26, R27: 10K; R0603
R28: 2.7K 1/16W; R0402
SW5: SW-200D; SW2-12.7-12.0X3.6X3.6MM
U5: FT232RL-SSOP28; SSOP28-0.65-10.2X5.2MM
U12: SP483ECN-L; SOIC127P600X175-8N
U$6: FE1.1S; FE1.1S_SSOP-28
USB1: ZX62-B-5PA; MICRO-USB5+6P-SMD-0.65-AB
Y2: 12MHZ; X2-SMD-5.0X3.2X1.3MM

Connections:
5V_USB_HUB: C32.1, R25.2, U$6.20 (VDD5), USB1.1 (VBUS); also elsewhere on the board
FTDI2_3V3: C29.2, U5.17 (3V3OUT)
FTDI2_CBUS1: R23.2, U5.23 (CBUS0)
FTDI2_RE: R27.1, U5.14 (CBUS3), U12.2 (~RE)
FTDI2_RXD: U5.5 (RXD), U12.1 (RO)
FTDI2_TE: U5.13 (CBUS2), U12.3 (DE)
FTDI2_TXD: U5.1 (TXD), U12.4 (DI)
FTID2_CBUS2: R24.2, U5.22 (CBUS1)
GND: C28.1, C29.1, C30.1, C31.1, C32.2, C33.1, C34.1, C35.1, C36.1, R26.2, R28.1, U5.7 (GND), U5.18 (GND), U5.21 (GND), U5.25 (GND), U5.26 (TEST), U12.5 (GND), U$6.1 (VSS), USB1.5 (GND); also elsewhere on the board
unnamed: D7.+, D15.+, SW5.1
unnamed: D7.-, R23.1
unnamed: D15.-, R24.1
unnamed: R25.1, R26.1, U5.19 (!RESET)
unnamed: U$6.2 (XOUT), Y2.1
unnamed: U$6.3 (XIN), Y2.2
unnamed: R28.2, U$6.14 (REXT)
unnamed: C35.2, U$6.28 (VD18)
unnamed: C36.2, U$6.13 (VD33)
unnamed: C34.2, U$6.21 (VD33_O)
unnamed: C33.2, U$6.12 (VD18_O)
PI_5V: C28.2, C30.2, C31.2, R27.2, SW5.2, U5.4 (VCCIO), U5.20 (VCC), U12.8 (VCC); also elsewhere on the board
RS485_A: U12.6 (A); also elsewhere on the board
RS485_B: U12.7 (B); also elsewhere on the board
RS485_DM: U5.16 (USBDM), U$6.10 (DM1)
RS485_DP: U5.15 (USBDP), U$6.11 (DP1)
UART1_DM: U$6.8 (DM2); also elsewhere on the board
UART1_DP: U$6.9 (DP2); also elsewhere on the board
UART2_DM: U$6.6 (DM3); also elsewhere on the board
UART2_DP: U$6.7 (DP3); also elsewhere on the board
UART3_DM: U$6.4 (DM4); also elsewhere on the board
UART3_DP: U$6.5 (DP4); also elsewhere on the board
USB_HUB_DM: U$6.15 (DMU), USB1.2 (D-)
USB_HUB_DP: U$6.16 (DPU), USB1.3 (D+)
USB_HUB_VD33_O: U$6.17 (XRSTJ), U$6.18 (VBUSM), U$6.19 (BUSJ), U$6.26 (OVCJ)

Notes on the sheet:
RPI RS485
disable for these LEDS?
USB HUB and RS485


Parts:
C38, C39, C42, C43, C46, C47: 100nf; C0603
C40, C44, C48: 4.7uf; C0603
D16, D18, D20: BLUE-0603; LED-0603
D17, D19, D21: GREEN-0603; LED-0603
R4, R12, R14: 4.7K; R0603
R8, R13, R15: 10K; R0603
R29, R30, R31, R32, R33, R34: 330R; R0603
SW6, SW7, SW8: SW-200D; SW2-12.7-12.0X3.6X3.6MM
U13, U14, U15: FT232RL-SSOP28; SSOP28-0.65-10.2X5.2MM

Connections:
5V_USB_HUB: R4.2, R12.2, R14.2; also elsewhere on the board
FTDI_3V3: C39.2, C43.2, C47.2, U13.17 (3V3OUT), U14.17 (3V3OUT), U15.17 (3V3OUT); also elsewhere on the board
GND: C38.1, C39.1, C40.1, C42.1, C43.1, C44.1, C46.1, C47.1, C48.1, R8.2, R13.2, R15.2, U13.7 (GND), U13.18 (GND), U13.21 (GND), U13.25 (GND), U13.26 (TEST), U14.7 (GND), U14.18 (GND), U14.21 (GND), U14.25 (GND), U14.26 (TEST), U15.7 (GND), U15.18 (GND), U15.21 (GND), U15.25 (GND), U15.26 (TEST); also elsewhere on the board
unnamed: R4.1, R8.1, U13.19 (!RESET)
unnamed: R12.1, R13.1, U15.19 (!RESET)
unnamed: R14.1, R15.1, U14.19 (!RESET)
unnamed: D20.+, D21.+, SW6.1
unnamed: D18.+, D19.+, SW7.1
unnamed: D16.+, D17.+, SW8.1
unnamed: D16.-, R29.1
unnamed: D17.-, R30.1
unnamed: R29.2, U13.23 (CBUS0)
unnamed: R30.2, U13.22 (CBUS1)
unnamed: D18.-, R31.1
unnamed: D19.-, R32.1
unnamed: R31.2, U14.23 (CBUS0)
unnamed: R32.2, U14.22 (CBUS1)
unnamed: D20.-, R33.1
unnamed: D21.-, R34.1
unnamed: R33.2, U15.23 (CBUS0)
unnamed: R34.2, U15.22 (CBUS1)
PI_5V: C38.2, C40.2, C42.2, C44.2, C46.2, C48.2, SW6.2, SW7.2, SW8.2, U13.4 (VCCIO), U13.20 (VCC), U14.4 (VCCIO), U14.20 (VCC), U15.4 (VCCIO), U15.20 (VCC); also elsewhere on the board
UART1_DM: U13.16 (USBDM); also elsewhere on the board
UART1_DP: U13.15 (USBDP); also elsewhere on the board
UART1_RDX: U13.1 (TXD); also elsewhere on the board
UART1_TDX: U13.5 (RXD); also elsewhere on the board
UART2_DM: U14.16 (USBDM); also elsewhere on the board
UART2_DP: U14.15 (USBDP); also elsewhere on the board
UART2_RDX: U14.1 (TXD); also elsewhere on the board
UART2_TDX: U14.5 (RXD); also elsewhere on the board
UART3_DM: U15.16 (USBDM); also elsewhere on the board
UART3_DP: U15.15 (USBDP); also elsewhere on the board
UART3_RDX: U15.1 (TXD); also elsewhere on the board
UART3_TDX: U15.5 (RXD); also elsewhere on the board

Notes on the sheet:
USB HUB TO UART


Board: 2 copper layers, 177.8 x 106.3 mm, 251 parts (0 on the bottom side), 239 nets.

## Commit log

2017-06-02 started everything from scratch using opl library
    [v1.brd]
2017-06-05 As worked on together
    [v1.0.brd, v1.brd]
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2017-06-05 SPI CS expander
    [v1.0.brd, v1.0.sch]
2017-06-05 added SPI CS expander on it's own page
    [v1.0.brd, v1.0.sch]
2017-06-06 added power circuit
    [v1.0.brd, v1.0.sch]
2017-06-07 General tidying, PSU mods, and pycom library created and added
    [v1.0.brd, v1.0.sch]
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2017-06-08 seeed dc-dc library finished RTC added
    [v1.0.brd, v1.0.sch]
2017-06-08 added crystal for RTC
    [v1.0.brd, v1.0.sch]
2017-06-08 LDO for 5V
    [v1.0.brd, v1.0.sch]
2017-06-08 very minor tweaks
    [v1.0.brd, v1.0.sch]
2017-06-08 added pycom accessories
    [v1.0.brd, v1.0.sch]
2017-06-08 pycom USB
    [v1.0.brd, v1.0.sch]
2017-06-08 USB to FT23
    [v1.0.brd, v1.0.sch]
2017-06-11 lopy FTDI and SD card socket
    [v1.0.brd]
2017-06-11 RPI SPI, I2C and UART sockets
    [v1.0.brd, v1.0.sch]
2017-06-11 polyfuse on Vin
    [v1.0.brd, v1.0.sch]
2017-06-12 Various tidying
    [v1.0.brd, v1.0.sch]
2017-06-12 lopy connectors
    [Seeed_OPL_List_download-20160608.xlsx, v1.0.brd, v1.0.sch]
2017-06-12 lopy the rest of the connectors
    [v1.0.brd, v1.0.sch]
2017-06-12 rtc crystals changed pi now power controller bypass for ldo rs485 driver
    [v1.0.brd, v1.0.sch]
2017-06-13 now correct version from yesterdays modifications
    [v1.0.brd, v1.0.sch]
2017-06-13 replaced with PI_5V and 3V3_SMOOTH where relevant
    [v1.0.brd, v1.0.sch]
2017-06-13 adc sockets
    [v1.0.brd, v1.0.sch]
2017-06-13 changed back to +5V - has LDO on it - and added RS485 socket
    [v1.0.brd, v1.0.sch]
2017-06-13 zener diode
    [v1.0.brd, v1.0.sch]
2017-06-13 start of poly fuse tidy
    [v1.0.brd, v1.0.sch]
2017-06-13 I think I am done?
    [v1.0.brd, v1.0.sch]
2017-06-13 Some tidying
    [v1.0.brd, v1.0.sch]
2017-06-13 tidy sockets
    [v1.0.brd, v1.0.sch]
2017-06-13 mcp23017 socket
    [v1.0.brd, v1.0.sch]
2017-06-14 finally thyristor - to check the library and grid
    [v1.0.brd, v1.0.sch]
2017-06-14 changing ldo
    [v1.0.brd, v1.0.sch]
2017-06-15 corrections in
    [Seeed_OPL_List_download-20160608.xlsx, v1.0.brd, v1.0.sch]
2017-06-18 eeprom and USB hub + UART
    [v1.0.brd, v1.0.sch]
2017-06-19 changed pins on sockets to have ground at the end
    [v1.0.brd, v1.0.sch]
2017-06-19 version printed, submitted to Steven
    [v1.0.brd, v1.0.sch]
2017-06-19 solving errors
    [v1.0.brd, v1.0.sch]
2017-06-20 starting board layout
    [v1.0.brd, v1.0_backup.sch$1.sch, v1.backup.sch$9.sch]
2017-06-20 board start
    [v1.0.brd, v1.0.sch]
2017-06-20 board arrangement
    [v1.0.brd, v1.0.sch]
2017-06-21 started double checking board position against schematics
    [v1.0.sch, v1.0_not saved.brd]
2017-06-21 board done
    [v1.0.brd, v1.0.sch]
2017-06-22 added temperature sensor and started labelling the board sockets
    [v1.0.brd, v1.0.sch]
2017-06-22 names and board labels
    [v1.0.brd, v1.0.sch]
2017-06-22 seeed submission - still looking for .ulp file to create bom
    [v1.0.GBL, v1.0.GBO, v1.0.GBP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]
2017-06-23 adding rs232 level converter
    [v1.0.brd, v1.0.sch]
2017-06-23 level converter added
    [v1.0.brd, v1.0.sch]
2017-06-23 board done after adding the level converter
    [v1.0.brd]
2017-06-23 added the mounting holes, need to tidy the board
    [v1.0.brd, v1.0.sch]
2017-06-23 added corrections on first 2 pages
    [v1.0.brd, v1.0.sch]
2017-06-23 changes names for 3v3 out for ftdi chip
    [v1.0.brd, v1.0.sch]
2017-06-23 fist changes
    [v1.0.brd, v1.0.sch]
2017-06-25 all the corrections are in, I am making a another check
    [v1.0.brd, v1.0.sch]
2017-06-25 added corrections and had a check
    [v1.0.brd, v1.0.sch]
2017-06-26 General pendantry of tidying and ERC etc
    [v1.0.brd, v1.0.sch]
2017-06-26 Clustering things ready for PCB layout
    [v1.0.brd, v1.0.sch]
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2017-06-27 before autoroute attempt
    [v1.0.brd, v1.0.sch]
2017-06-27 Most of the board laid out
    [v1.0.brd, v1.0.sch]
2017-06-28 All components now placed
    [v1.0.brd]
2017-06-28 Board layout potentially complete - just needs a name now
    [v1.0.brd, v1.0.sch]
2017-06-30 Pi control of LoPy reset added Pi & lopy uart0 connected
    [v1.0.brd, v1.0.sch]
2017-07-03 Switches changed for toggle as opposed to push FETs added for Pi -> lopy control lines
    [v1.0.brd, v1.0.sch]
2017-07-03 Now has 2 TTL serial ports
    [v1.0.brd, v1.0.sch]
2017-07-04 As submitted
    [BOM for Seeed.xlsx, BOMv1.0.xlsx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]
2017-07-12 Part placement file generated
    [v1.0.brd]
2017-08-02 Add the v1 schematic and board into the folder
    [v1.0.brd, v1.0.sch]
2017-08-02 Start of mods for V2
    [v2.0.brd, v2.0.sch]
2017-08-03 moved some test pads around
    [v2.0.brd]
2017-08-04 More work on fixing bugs
    [v2.0.brd, v2.0.sch]
2017-08-04 fixed name of pycom pin 12 signal track
    [v2.0.brd, v2.0.sch]
2017-08-08 More updates to fix issues and start of v2 BOM
    [AQN-BOM.xlsx, v2.0.brd, v2.0.sch]
2017-08-09 More updates, and verifing of current state of BOM
    [AQN-BOM.xlsx, v2.0.brd, v2.0.sch]
2017-08-10 Lopy reset and bootloader now on port expander
    [v2.0.brd, v2.0.sch]
2017-08-10 Start of connector / fuse rationalisation
    [v2.0.brd, v2.0.sch]
2017-08-10 More rearranging
    [v2.0.brd, v2.0.sch]
2017-08-10 Updated BOM to match Eagle data. Added Seeed BOM.
    [AQN-BOM.xlsx, Seeed-AQN-BOM.xlsx]
2017-08-10 V2 laid out
    [v2.0.brd, v2.0.sch]
2017-08-11 Removed two fuses, as per the final version
    [AQN-BOM.xlsx, Seeed-AQN-BOM.xlsx]
2017-08-11 Added missing pricing information
    [AQN-BOM.xlsx]
2017-08-11 RTC changed to one that doesn't rely on external crystal
    [v2.0.brd, v2.0.sch]
2017-08-11 Added final few parts
    [AQN-BOM.xlsx, Seeed-AQN-BOM.xlsx]
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2017-08-11 Added UART 0-ohms and UART Pi 1 header
    [AQN-BOM.xlsx, Seeed-AQN-BOM.xlsx]
2017-08-11 Fixed quantities
    [AQN-BOM.xlsx, Seeed-AQN-BOM.xlsx]
2017-08-11 More minor layout tweaks
    [v2.0.brd]
2017-08-13 Added custom PiSEB logo
    Logo imported using this tutorial: https://learn.sparkfun.com/tutorials/importing-custom-images-into-eagle/all
    [v2.0.brd]
2017-09-11 added the schematic and board into v2 folder
    [v2.0.brd, v2.0.sch]
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

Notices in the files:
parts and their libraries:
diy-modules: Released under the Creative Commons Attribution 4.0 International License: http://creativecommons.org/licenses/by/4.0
